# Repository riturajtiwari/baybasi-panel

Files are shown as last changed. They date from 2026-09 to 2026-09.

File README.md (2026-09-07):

# Baybasi pixel wall

Software and firmware for a WS2812B video wall. The wall is 64 pixels wide and
192 pixels high. Each wall has 48 panels of 16 x 16 pixels.

There are two identical displays. The two displays do not share a cable, a
ground or a clock. Each display is a complete and independent system.

The software runs today without hardware. A software DDP sink receives the
pixel data and shows the result in a browser. You can test the driver and the
upload utility before the boards arrive.

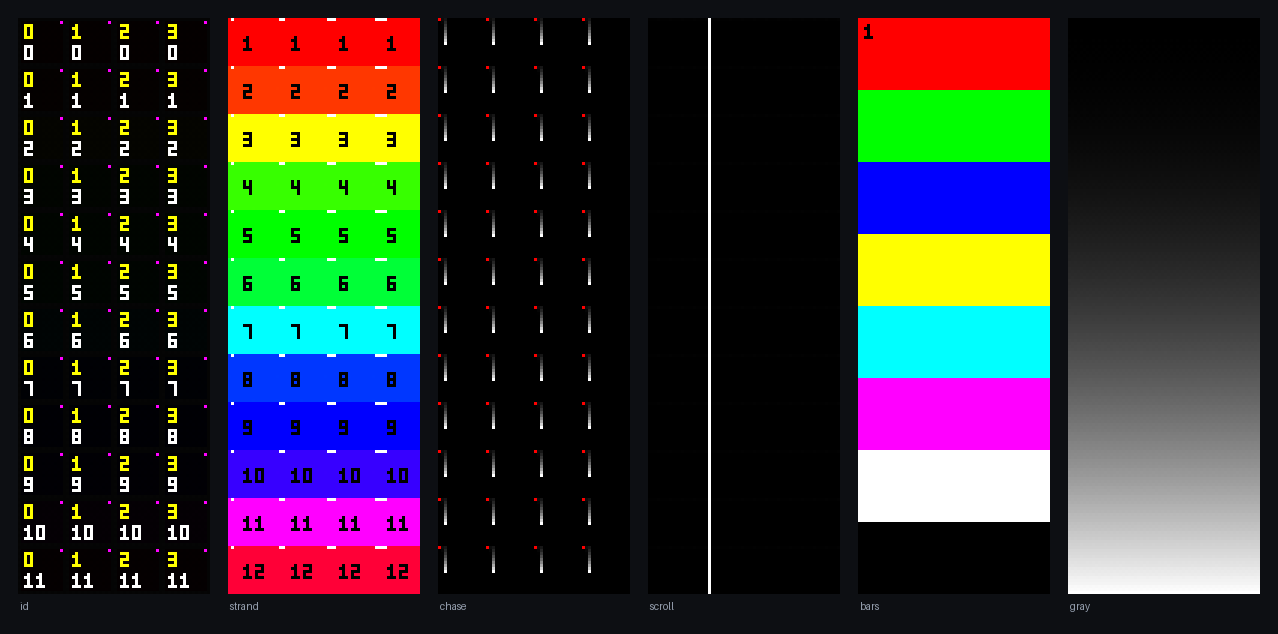
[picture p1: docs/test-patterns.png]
The test patterns


---

## 1. The system

Each display contains these parts:

| Part | Quantity |
|---|---|
| Raspberry Pi 3 or newer, Pi OS Lite, headless | 1 |
| 8-port unmanaged switch | 1 |
| Controller board, one for each panel column | 4 |
| 16 x 16 WS2812B panel | 48 |

Each controller board holds an ESP32-S3-DevKitC-1, a WIZnet W5500 Ethernet
module and two SN74AHCT245N level shifters. Each board has 12 data outputs.
Each output drives one panel. The panels are not in a daisy chain. Thus one
strand has 256 LEDs and one frame needs 7.98 ms.

The Raspberry Pi holds all the geometry. A controller knows only the quantity
of bytes that it owns. All four controllers use the same firmware.

---

## 2. The contents of this repository

| Directory | Contents |
|---|---|
| `sw/` | The driver, the upload utility and the software DDP sink. Python. |
| `fw/` | The controller firmware. C++, PlatformIO, arduino-esp32 3.x. |
| `hw/` | The board design, the fabrication files and the enclosure. KiCad. |
| `HANDOFF-software.md` | The specification. |

`sw/README.md` and `fw/README.md` give more data about each part.

---

## 3. Before you start

You must have these programs:

- Python 3.9 or newer
- `ffmpeg` and `ffprobe`, on the PATH
- PlatformIO, but only to build the firmware

Install the software:

```bash
cd sw && python3 -m venv .venv && .venv/bin/pip install -e .
```

Make sure that the configuration is correct:

```bash
.venv/bin/baybasi check
```

The command shows the geometry and the wire budget. The command shows
`no problems found` if the configuration is correct.

---

## 4. Procedure: test the software without hardware

Do this procedure before the boards arrive. The procedure finds mapping errors
on a screen. You do not have to look at 8 feet of LEDs.

1. Start the software DDP sink in the first terminal:

   ```bash
   cd sw && .venv/bin/baybasi sink
   ```

2. Open `http://localhost:8088` in a browser.

3. Send a test pattern from the second terminal:

   ```bash
   cd sw && .venv/bin/baybasi pattern id --target 127.0.0.1
   ```

4. Look at the browser. Each of the 48 panels shows its own column number in
   yellow and its own row number in white. If a number is in the wrong
   position, correct the `panels:` list in `sw/config/wall.yaml`.

5. Send the other patterns. Refer to section 7.

6. Stop the pattern. Then start the driver and the upload utility:

   ```bash
   cd sw && .venv/bin/baybasi driver --target 127.0.0.1
   ```

   ```bash
   cd sw && .venv/bin/baybasi web
   ```

7. Open `http://localhost:8080`. Add a media file. Set the fit policy. Look at
   the preview.

**Caution: Do not send two patterns at the same time.** Two senders on UDP port
4048 cause torn frames. The sink shows a warning if this condition occurs.

---

## 5. Procedure: install on the Raspberry Pi

Do this procedure on each of the two Raspberry Pi computers.

```bash
sudo IFACE=eth0 PI_IP=192.168.50.1 ./sw/deploy/install.sh
```

The script does these tasks:

1. Installs Python, `ffmpeg` and `chrony`.
2. Installs the software in `/opt/baybasi`.
3. Puts the media library in `/var/lib/baybasi`.
4. Sets the wired interface to `192.168.50.1/24`.
5. Sets `ipv4.never-default yes` on that interface.
6. Starts the driver and the upload utility as services.

**The LED network must not become the default route.** The LED network has no
connection to the internet. If the LED network becomes the default route, the
Raspberry Pi loses DNS and NTP. NTP keeps the two displays in step.

---

## 6. Procedure: flash and commission a board

**Warning: Flash each board on the bench. Do not flash a board that is in a
controller.** A devkit in a controller with USB power sends 5 V out through the
power terminal. The 5 V can energize the panel column.

**Note:** Many USB-A to USB-C cables supply power only. Such a cable makes the
devkit port look defective. If the devkit does not show on the USB bus, replace
the cable first.

1. Connect the devkit to the computer with a USB-C data cable.

2. Build and flash the firmware:

   ```bash
   cd fw && pio run -t upload
   ```

3. Flash all 10 devkits at the same session. Then install the devkits in the
   controllers.

4. Connect the controller to the switch. Apply power.

5. Find the board on the Raspberry Pi:

   ```bash
   baybasi discover
   ```

   The board shows its factory MAC address. The column is empty.

6. Give the board its column:

   ```bash
   baybasi assign aa:bb:cc:dd:ee:ff 2
   ```

   The board writes the column to NVS. Then the board restarts. The board keeps
   the column after an update.

7. Do steps 4 to 6 for each of the four boards.

After the first flash, use the network for all subsequent updates:

```bash
baybasi ota .pio/build/baybasi-ctrl/firmware.bin --pi-ip 192.168.50.1
```

If an update fails, remove the devkit from its sockets. Then install a
different devkit.

---

## 7. The test patterns

```bash
baybasi pattern <name> --target 127.0.0.1
```

| Name | Function | What you must see |
|---|---|---|
| `id` | Panel identification | Each panel shows its column and its row. |
| `strand` | Output identification | Each output has a different colour. |
| `chase` | LED chain | A comet moves smoothly along the chain. |
| `scroll` | Frame synchronization | A white column moves across the wall. The line does not break at the column seams. |
| `bars` | Colour order | The top band is red. |
| `gray` | Gamma and dither | A smooth ramp. There are no bands. |
| `solid` | Power supply | A flat colour. |

`scroll` is the most important pattern. Only `scroll` shows a synchronization
error between the four controllers.

**Caution: `solid` at full white causes the maximum current.** Do not use
`solid` at full white before the power injection is correct.

---

## 8. Configuration

`sw/config/wall.yaml` holds all the geometry. The file is data and not code.
You can correct an error in the wall with a text editor. You do not have to
change the Python code.

The file contains these items:

| Item | Function |
|---|---|
| `panel.chain` | The sequence of the 256 LEDs in one panel. |
| `controllers[].panels` | The wall row that each output drives. |
| `transform` | The rotation of one panel. Use this for a panel that is upside down. |
| `color_order` | The channel sequence on the network. |
| `render` | The frame rate, the gamma, the brightness and the epoch. |
| `network` | The addresses, the port and the packet size. |

Example: row 7 of column 2 shows the picture of row 8. To correct this error,
change two lines in the `panels:` list. Then restart the driver.

---

## 9. The status LED

The status LED is the only indication that you can see when the board is behind
a panel.

| Colour | Condition |
|---|---|
| Red | The board is in the start sequence. |
| Red, slow flash | There is no Ethernet link. |
| Amber | The link is up. There are no pixels for more than 500 ms. |
| Blue | The board receives data. The outputs are off. |
| Green, slow pulse | The board operates correctly. |
| Magenta | The frames are not complete. |
| White, pulse | An update is in progress. |
| White, fast flash | The operator sent a Find command. |
| Red, fast flash | There is a fault. Read the serial log. |

---

## 10. Keep the two displays in step

No messages go between the two displays. Each Raspberry Pi calculates the frame
number from the time of day:

```python
frame_index = int((time.time() - EPOCH) * FPS) % n_frames
```

Thus the two displays agree only if the two playlists are the same. The
playlist compiles to a frame timeline. The manifest digest is a hash of that
timeline.

Procedure:

1. Upload the same media to the first Raspberry Pi.
2. Upload the same media to the second Raspberry Pi.
3. Download the manifest from the second Raspberry Pi.
4. Use the **Compare** button on the first Raspberry Pi.

If the two digests agree, the two walls show the same content. If the two
digests do not agree, the utility gives the reason:

```
$ baybasi manifest --compare pi-b.json
DIFFERS:
  sunset.jpg: fit letterbox vs crop
  same media, different playlist order
```

The `EPOCH` value in `wall.yaml` must be the same on the two computers. The
`wall_digest` value must also be the same.

---

## 11. Troubleshooting

| Symptom | Cause | Correction |
|---|---|---|
| The sink shows torn frames and a high gap count. | Two senders transmit on port 4048. | Stop the other `baybasi pattern` or `baybasi driver`. |
| The wall shows noise at power-up. | The level shifters became active too soon. | Measure GPIO 8. GPIO 8 must stay high until the first complete frame. Check R15 to the 3V3E rail. |
| The wall keeps one picture after a fault. | The controller still receives packets. | Look at the driver log. A controller goes to black 500 ms after the last packet. |
| Red and green are not correct. | The Pi and the firmware both change the channel order. | Set `LED_ORDER_GRB` to 0 in `fw/src/config.h`. Refer to section 12. |
| The driver reports dropped frames. | The Raspberry Pi cannot do the work in time. | Read the stage times in `baybasi status`. The slowest stage is the cause. |
| The board does not show in `baybasi discover`. | There is no link, or the board has no address. | Look at the status LED. A red flash shows that there is no link. |
| The two walls do not agree. | The playlists are different. | Compare the manifests. Refer to section 10. |

---

## 12. Two decisions that the specification did not make

**The network carries RGB. The firmware changes the sequence to GRB.** The
WS2812B is a GRB device, but that is a property of the LED and not of the
network. The DDP data-type byte declares RGB. Thus a GRB payload would give
incorrect data to Wireshark and to other DDP tools.

One flag controls each side: `color_order` in `wall.yaml`, and `LED_ORDER_GRB`
in `fw/src/config.h`. Only one of the two must change the sequence. The `bars`
pattern shows which condition is true. The top band must be red.

**Each controller has its own DDP destination identifier, 10 to 13.** The four
boards are still different only by IP address. The identifier comes from the
column number. The firmware also accepts identifier 1 and identifier 255. The
byte counts do not change.

The identifier gives two advantages. One software sink on one computer can
replace four boards on four addresses. A packet that goes to the incorrect
board is rejected and not shown.

---

## 13. Tests

Python, 70 tests:

```bash
cd sw && .venv/bin/python -m pytest tests -q
```

Firmware logic, 20 tests. The tests run on the host computer:

```bash
cd fw && clang++ -std=c++17 -O1 -g -fsanitize=thread -I test/shim \
    -o /tmp/fwtest test/test_framebuf.cpp src/framebuf.cpp && /tmp/fwtest
```

---

## 14. The condition of this project

The software is complete and tested. A measured run gives 30.0 frames each
second with 0 torn frames and 0 protocol errors. The Raspberry Pi work is
3.0 ms of the 33.3 ms budget.

The firmware is complete but **no person has flashed the firmware to a board**.
The boards are in fabrication. Only the frame assembler is proven. The frame
assembler compiles on the host computer and passes the thread tests.

These items are not proven:

- The Ethernet start sequence
- The `/OE` sequence at power-up
- The update through the network
- The LED library with the 12 pins of the board

Do these three checks first at the bench:

1. The serial log shows the factory MAC address and a successful `ETH.begin`.
2. `baybasi discover` finds the board.
3. `baybasi pattern bars` lights the panels. The top band is red. There is no
   flash at power-up.

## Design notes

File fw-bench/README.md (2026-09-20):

# Bench panel test

Confirm WS2812B panels are alive before any of the real hardware exists. Runs on
a **classic ESP32 devkit** (ESP-WROOM-32, 30-pin, HW-394 or similar), not the
ESP32-S3 the controllers use.

Shares nothing with `../fw` except the serpentine mapping. Different chip,
different pins, no Ethernet. Do not carry pin numbers between them.

## What it does

Chains **4 panels on one wire** (1024 LEDs, one row of the wall) and cycles four
patterns forever. **It runs standalone.** Flash it, unplug the laptop, and it
keeps going: nothing waits on serial and nothing ever finishes.

| # | Pattern | Lit at once | Answers |
|---|---|---|---|
| 1 | **Panel walk**, one panel white | 256 | Is each panel alive, and in what order? |
| 2 | **Band**, a sliding hue-cycling band on every panel | 128 | All panels at once, and every colour channel |
| 3 | **Block**, a quarter panel marching the row in six colours | 64 | Every LED, every colour, at full brightness |
| 4 | **Trace**, one LED end to end | 1 | Exactly which LED does the chain stop at? |

**Nothing ever lights the whole row.** 1024 LEDs at white is ~61 A, which no
bench supply wants, least of all unattended. So the most any pattern lights is
one panel's worth. That is not only safer, it looks better: FastLED scales the
whole frame down to fit the current cap, so lighting less at a time means what
IS lit runs near full brightness.

**The onboard LED blinks at 1 Hz while the firmware is alive.** With no laptop
attached that is your only diagnostic, and it is worth more than it looks:
panels dark but LED blinking means power, data or panels, not a crashed board.

## The two numbers that change on a chain

| | One wire, 4 panels | Production, 12 outputs |
|---|---|---|
| LEDs per wire | 1024 | 256 |
| Frame time | ~31 ms, so ~32 fps | 8 ms, so 125 fps |
| Whole string white | **~61 A** | ~15 A per output |

This rig is a bench convenience. Those two numbers are the whole reason the real
controller gives every panel its own output.

## Powering it standalone

The dev kit needs its own 5 V once the laptop is gone. Two ways:

- **USB phone charger into the USB-C port.** Preferred. It isolates the ESP32
  from LED rail sag, so a heavy moment on the panels cannot brown out the board
  and reset it mid-test. Still tie ESP32 **GND** to panel **GND**.
- **VIN pin from the same 5 V that drives the panels.** One supply, and the
  common ground comes free, but a sagging rail takes the ESP32 down with it.

**Set `SUPPLY_MA` in `src/main.cpp` to what your bench supply can actually
deliver.** It defaults to 5000 mA. FastLED rescales brightness every frame to
stay inside it, so the column comes out dim. That is correct, not a fault.

**Inject 5 V at both ends of the chain.** Twelve panels fed from one end drop a
lot of voltage along the way, and the far panels go dim and orange. That is
voltage drop, not dead LEDs, and it is the most common false alarm on a chain
this long.

## NEVER power a panel from the dev kit

This destroyed a dev kit on 2026-09-13. Read both warnings before you wire anything.

The panel's lead carries three conductors: 5 V, DIN, GND. **Plug all three into the dev
kit and you have made the dev kit the panel's power supply.** Use two of them. Tape off
or pull the 5 V conductor.

256 WS2812B is 15.4 A at white. `SUPPLY_MA` defaults to 5000, so FastLED will happily
scale to a 5 A budget and ask the 5 V pin for it:

| Path | Realistic capability |
|---|---|
| Laptop USB 2.0 port | 500 mA |
| USB 3 port | 900 mA |
| Phone charger | 1.5 - 3 A |
| Dev kit 5 V trace and USB connector | ~1 - 2 A |
| What the firmware asks for at default | **5 A** |

Five to ten times what the path can carry. What burns is the USB connector, the board's
5 V trace or its series protection diode, and the AMS1117 on the same rail.

The production board does not make this mistake: J1-J12 are two-pin, DATA + GND, no
+5 V pin, with 330 ohm in series on every output. Wire the bench the same way.

If you genuinely must run a panel from USB, say so in the build flags. After the
ESP32's own ~50 mA a laptop port leaves about 400 mA, which is seven LEDs at white or
the whole panel at ~2.5 %:

```bash
PLATFORMIO_BUILD_FLAGS="-DPANELS=1 -DSUPPLY_MA=400" pio run -t upload
```

That is enough to prove a panel is alive and nothing more.

## NEVER drive data into an unpowered panel

The WS2812B's DIN pin has an ESD clamp diode to VDD. Drive DIN at 3.3 V while the
panel's 5 V rail is dead and that diode forward-biases, and **your GPIO becomes the
power supply for the whole panel**:

    GPIO 13 -> LED1 DIN -> ESD clamp diode -> the panel's entire 5 V net

An ESP32 pad is rated 40 mA absolute maximum. 256 WS2812B just sitting quiescent is
~256 mA, and at the ~2.6 V a clamp diode passes they are all in brownout, where the
draw is not 256 mA but whatever the half-biased silicon decides. LED 1's diode fails
short, GPIO 13 becomes a dead short to ground, and the AMS1117 on the dev kit
current-limits at about 1 A while dropping 1.7 V. That is the smoke.

**A switched-off supply does not save you. It is the reason it never stops.** An SMPS
with its switch off still has output capacitors and a bleeder resistor between +V and
-V, and -V is tied to your ESP32 ground. The panel's 5 V net therefore has a permanent
path to ground, so the GPIO never charges something up and stops. It sources current
until something fails.

Two rules, both cheap:

1. **One switch for everything.** Panel 5 V comes up before or with the ESP32, and goes
   down after it. Easiest is to power the ESP32 from the same 5 V that feeds the panels.
2. **330 ohm in series with DIN at the ESP32 end. Always, not just when debugging.**
   It caps a repeat of this at 3.3 V / 330 = 10 mA, which the pad shrugs off, and it
   does not measurably soften the edge over a short lead.

If it has already happened: the dev kit is scrap, do not try to rescue it. Test the
panel on a known-good board too — a damaged LED 1 blocks data to everything behind it.

## Wiring

- **330 ohm in series** between **GPIO 13** and **panel DIN**. See above. Not optional.
- **Panel GND** to an ESP32 **GND** pin. Not optional either, and the usual reason a
  column sits dark.
- **No wire, ever, between the dev kit's 5 V or VIN pin and the panel.** The panel's
  5 V comes from the bench supply and only from the bench supply:

      bench supply (ON) --5 V--+-- panel VDD
                               +-- panel GND --+-- ESP32 GND     <- mandatory
      USB -- ESP32 -- GPIO 13 --[330]----------+-- panel DIN
- **Panel 5 V and GND** to the bench supply, at both ends of the chain.
- ESP32 powered from a USB charger, or from VIN — see above.
- Keep the lead to the first panel under about 30 cm.

**Power the panel supply on first, and off last.** Every time.

A phone charger makes a fault worse than a laptop does: a laptop USB port will often
current-limit or shut down, a charger will happily deliver 2 A into a short.

**GPIO 12 is not used and must not be.** Held high at reset it sets the flash
voltage wrong and the board will not boot. On the header it sits between D14 and
D13, so count pins rather than trusting the gap.

### Do not use the blue level shifter

The 4-channel BSS138 board shifts through a MOSFET with 10 k pull-ups. The rising
edge takes hundreds of nanoseconds against a 400 ns data pulse, so it turns clean
data into garbage. It is the part the controller design rejected in favour of the
SN74AHCT245. Drive the first panel straight from the ESP32 at 3.3 V.

3.3 V into a 5 V-powered WS2812B is marginal on paper, since DIN wants
0.7 x VDD = 3.5 V, but it works over a short lead and is how these are normally
bench-tested. Only the first panel sees it; every LED reshapes the signal for the
next one, so a long chain is no harder than a short one. If the first panel
misbehaves:

1. Shorten the data lead.
2. Drop the panel supply to about 4.5 V, which pulls the threshold under 3.3 V.

(The 330 ohm series resistor is already mandatory — see the wiring section.)

## Bringing up the controller board on flying leads

The devkit in hand measures **2.5 mm wider** between its header rows than the
board's A1L/A1R sockets - 25.4 mm against 22.86 mm, which is exactly one 2.54 mm
pitch. It will not seat. **Do not press harder**: the sockets are factory-soldered
and splaying their contacts turns a good board into scrap.

You do not need it seated.

### First try: does the LEFT row alone go in?

At a 2.54 mm mismatch one row often seats while the other rides outboard. If the
left row (A1L) is down, **you need no jumpers at all** - everything the bring-up
firmware touches is on it:

| Devkit pad | GPIO | On this board |
|---|---|---|
| 4, 5, 6 | 4, 5, 6 | LED outputs D1, D2, D3 -> J1, J2, J3 |
| 7  | 7  | sync in |
| 8  | 15 | W5500 RST |
| 12 | 8  | /OE for both 245s |
| 16, 17, 18, 19 | 10, 11, 12, 13 | W5500 CS, MOSI, SCK, MISO |
| 20 | 14 | W5500 INT |
| 21, 22 | - | 5 V in, GND |

**The whole W5500 interface is on that row**, so Ethernet and the production
firmware in `../fw` can be brought up with the devkit half-seated. D4-D12 are all
on the right row and stay dark; they are nine more copies of the circuit D1-D3
already proves.

Three cautions while it sits at an angle:

- **Check the loose row touches nothing.** Those pins sit over U2's socket and
  the output resistors. Slide card or Kapton underneath.
- **Confirm seating in one second:** power from J13 with no USB. If the devkit
  comes up, pads 21 and 22 are making contact.
- **Expect noise on J4-J12.** Their 245 inputs float with the row unseated, so
  the buffers pass garbage to those terminals. Harmless if nothing is connected.

Do not leave a devkit levered like this permanently - the seated pins carry the
bending moment and A1L's contacts take it.

### If neither row seats: three jumpers

Female-to-male Dupont leads: the female end onto the devkit's header pin, the
male end (0.64 mm square) straight into the socket hole. Count holes on **A1L**,
the LEFT socket, from the **TOP** of the board - the J1-J6 terminal-block end,
with the devkit's USB ports toward the bottom edge.

| Devkit pin | A1L hole | Carries |
|---|---|---|
| `GND` (below `5Vin`) | **22**, the last one | the only logic reference. Not optional |
| `8`  | **12** | /OE. LOW or nothing leaves the board |
| `4`  | **4**  | output D1 -> R1 330R -> J1 |

**Check the count before you trust it.** A1L hole 22 is a dead short to the J13
GND terminal, and hole 21 shows a diode drop to J13 `+` through Q1. If those two
do not read that way you are counting from the wrong end, and hole 4 is really
hole 19 (GPIO13) - which will look exactly like a dead board.

Power:

- **Board** from J13, off the bench supply.
- **Devkit** from USB only. Do NOT also jumper 5 V: its 5 V pin back-feeds this
  board through Q1's channel. See FABRICATION.md.
- **Panel 5 V and GND from the bench supply**, never from this board. J1-J12
  carry DATA + GND only, which is exactly why this board cannot repeat the
  dev-kit failure above.
- Panel DIN to J1's **square** pad (`J1-J12: SQ PAD = DATA` on the silkscreen).

```bash
pio run -e ctrl-board -t upload
```

Flash over the **COM** port (the UART bridge). The monitor is on the **USB**
port, because the env sets `ARDUINO_USB_CDC_ON_BOOT=1`.

What lights proves: J13, Q1, the 5 V rail, U3 and the 3V3E rail, R15, U1, R1,
J1 and the full signal chain. What it does not touch: U2 and outputs 7-12, and
the W5500. Add `-DLED_PIN=5` and move the jumper to A1L hole 5 to walk along
D2, D3, and so on.

## Flashing the S3 devkits: expect the BOOT dance

Confirmed on hardware 2026-09-19. These boards have two USB-C ports. The one that
enumerates on macOS as **`/dev/cu.usbmodem*`** is the **native USB-Serial/JTAG**
port, not a UART bridge (a bridge would appear as `cu.wchusbserial*` or
`cu.usbserial-*`). esptool cannot reset a native-USB port into download mode while
application firmware owns it, so a plain upload fails with:

    A fatal error occurred: Failed to connect to ESP32-S3: No serial data received.

Force download mode by hand, every upload:

1. Hold **BOOT**.
2. Tap **RST**.
3. Wait a beat, release **BOOT**.
4. The RGB LED goes dark - that is your confirmation. Wait ~2 s to enumerate.

**Then do NOT pass `--upload-port`.** The device renames itself between application
mode and ROM download mode (seen: `usbmodem1234561` -> `usbmodem101`), so a pinned
port fails with "No such file or directory". Let auto-detect find it:

```bash
ls /dev/cu.* && pio run -e ctrl-all12 -t upload
```

A good upload reports `USB mode: USB-Serial/JTAG` and `Hash of data verified` on
every block. It also prints the **MAC address** - record it, the driver assigns
columns by MAC.

## Build and flash

PlatformIO is not installed by default on this machine:

```bash
uv tool install platformio
```

Plug the devkit in with a **data** USB-C cable first. A charge-only cable is
indistinguishable from a dead board. Check it appeared with `ls /dev/cu.*`,
looking for `/dev/cu.wchusbserial*`. The HW-394 uses a CH340C, which macOS
Sequoia drives natively.

```bash
pio run -t upload && pio device monitor
```

If upload times out, hold **BOOT**, tap **EN**, release **BOOT**, retry.

### If nothing lights at all

Check the chipset before suspecting hardware. These panels are older than the
WS2812B the wall is specified around, and the wrong chipset looks identical to a
dead column. Uncomment one line in `platformio.ini` and reflash:

```
; -DLED_CHIPSET=WS2811
; -DLED_CHIPSET=WS2812
; -DLED_CHIPSET=SK6812
```

### Testing a different number of panels

`PANELS` is a build flag, so no source edit is needed:

```bash
pio run -t upload                                   # 4 panels, one row
PLATFORMIO_BUILD_FLAGS="-DPANELS=1"  pio run -t upload   # a single panel
PLATFORMIO_BUILD_FLAGS="-DPANELS=12" pio run -t upload   # a whole column
```

Every pattern scales itself, and the lit-LED count stays bounded at one panel's
worth regardless, so a column is no harder on the supply than a row.

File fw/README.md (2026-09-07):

# Baybasi controller firmware

One image for all four boards. ESP32-S3-DevKitC-1, W5500 on SPI, twelve
parallel WS2812B outputs through two SN74AHCT245N level shifters.

```bash
pio run                      # build
pio run -t upload            # first flash, over the devkit's USB-C, on the bench
pio device monitor
```

Then everything after the first flash goes over Ethernet, from the Pi:

```bash
baybasi ota .pio/build/baybasi-ctrl/firmware.bin --pi-ip 192.168.50.1
```

## Flash all ten before any of them goes into a board

Two traps, both of which cost a day if you meet them mid-assembly:

- **Many USB-A to USB-C cables are charge-only** and make the devkit's port look
  dead. If nothing enumerates, change the cable before you change anything else.
- **A devkit seated in a board with USB live back-feeds 5 V** out through the
  power terminal and tries to power the panel column. Flash on the bench, before
  the devkits are seated. If you must flash a seated devkit, do it with the LED
  PSU on, or with the panel supply disconnected.

Recovery from a bricked OTA is to pull the devkit out of its sockets and put
another one in. That is what the sockets are for.

## Pin map

Final, from the board's pad coordinates. `src/config.h`.

| Function | GPIO |
|---|---|
| W5500 CS / MOSI / SCK / MISO | 10 / 11 / 12 / 13 |
| W5500 INT | 14 |
| W5500 RST | 15, active low |
| LED outputs D1, D2, D3 | 4, 5, 6 |
| LED outputs D4 … D12 | 1, 2, 21, 38, 39, 40, 41, 42, 47 |
| Level-shifter /OE, both chips | 8 |
| Sync input, optional, unpopulated | 7 |
| Status RGB LED | 48 |

## The three things that will otherwise cost you a day

**Twelve outputs cannot use RMT.** The ESP32-S3 has four RMT transmit channels.
Twelve parallel outputs go through the LCD_CAM peripheral in parallel mode,
which is what `I2SClocklessLedDriver` does. Any GPIO works, because it routes
through the GPIO matrix.

**GPIO 8 is /OE and is pulled up to 3V3E on the board.** HIGH means the shifters
are high-impedance and every panel sees a defined low through R16-R27. The
firmware holds it high through boot and drives it low only once the first
*complete* frame has been buffered and clocked out. Skip that and the wall
shows noise at power-up.

**The W5500 needs 50 ms after RST is released before SPI.** `net.cpp` does the
reset itself and waits, then passes `rst = -1` to `ETH.begin` so the driver does
not pulse it again and skip the wait.

## Order of events at power-up

1. `/OE` stays HIGH. Nothing on the wall lights up.
2. Ethernet comes up. Static address from NVS if this board has a column; DHCP
   (in practice link-local) if it does not, which is enough to be seen and
   commissioned and not enough to be mistaken for a working column.
3. The first complete DDP frame is buffered and clocked out.
4. `/OE` goes LOW and the wall becomes visible.

## Board identity

All four boards run the same binary, so something has to say which column a
board owns. That something is NVS, not the image — building four images turns
every OTA into an opportunity to put column 3's code on column 1.

An unassigned board broadcasts an announcement every two seconds on UDP 4049
carrying its factory MAC, which is unique per chip. The W5500's MAC is that same
factory MAC, so the identity on the wire and the identity in the announcement
cannot drift apart. The Pi holds the MAC-to-column table, consistent with the Pi
holding all the other geometry.

Commissioning a replacement board:

```bash
baybasi discover                   # watch the new MAC appear
baybasi assign aa:bb:cc:dd:ee:ff 2 # it reboots onto 192.168.50.13 and stays there
```

Or the same two steps in the upload utility's **Controllers** panel, which also
has a **Find** button that flashes the board's status LED — useful when the
board is behind a panel, mid-column, and you need to know which one it is.

## Frame handling

The board owns 9216 bytes and knows nothing else about the wall. Seven data
packets arrive per frame; one zero-length broadcast PUSH latches all four
controllers together.

Completeness is tracked as a set of byte intervals, not a byte count — a
duplicated packet must not be mistaken for a complete frame. An incomplete
frame at PUSH is counted and **dropped**, never shown.

Three buffers, not two. A frame takes 7.98 ms to clock out and the LED
peripheral reads its buffer by DMA the whole time; with two buffers a latch
arriving mid-transmission hands the network thread the buffer still being
clocked out. The writer, the frame waiting, and the frame being shown are always
distinct, with no lock on the receive path.

After 500 ms with no packets the board fades to black over 600 ms. A frozen wall
looks like working content and hides the fault.

## Status LED

The only thing you can see once the board is in an enclosure behind a panel.

| | |
|---|---|
| red | booting |
| red, blinking | no Ethernet link |
| amber | link up, no pixels for over 500 ms |
| blue | receiving, outputs still disabled |
| green, breathing | running |
| magenta | frames are arriving incomplete |
| white, pulsing | OTA in progress |
| white, flashing | "Find" from the Pi |
| red, fast | fault — read the serial log |

## Colour order

The Pi sends RGB; this firmware reorders to GRB on the way into the strand
buffer (`LED_ORDER_GRB` in `config.h`). If your build of the LED library *also*
reorders, the two swaps cancel and red and green come out exchanged. Set
`LED_ORDER_GRB` to 0 and rebuild.

`baybasi pattern bars` on the Pi settles it in one look: the top band is red.

## Tests

The frame assembler is the part most likely to be subtly wrong, and it is pure
logic, so it compiles and runs on a host:

```bash
clang++ -std=c++17 -O1 -g -fsanitize=thread -I test/shim \
    -o /tmp/fwtest test/test_framebuf.cpp src/framebuf.cpp && /tmp/fwtest
```

That covers out-of-order and duplicated packets, a lost packet leaving the frame
incomplete, the RGB-to-GRB reorder across packet boundaries, and a two-thread
stress test of the triple buffer under ThreadSanitizer.

## Not yet run on hardware

The boards are in fabrication. Everything above is written against the
datasheets, `hw/FABRICATION.md` and the arduino-esp32 3.x API; the frame logic
is tested on a host, but nothing here has been flashed. The first three things
to check on the bench, in order:

1. Serial output shows the factory MAC and `ETH.begin` succeeding.
2. `baybasi discover` on the Pi sees the announcement.
3. `baybasi pattern bars` — panels light, red at the top, no flicker at
   power-up.

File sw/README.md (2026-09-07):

# Baybasi wall software

Driver, upload utility and software DDP sink for a 64 x 192 WS2812B wall, per
`../HANDOFF-software.md`. The controller firmware is in `../fw`.

Everything here runs today, against the software sink, with no hardware.

```bash
python3 -m venv .venv && .venv/bin/pip install -e .   # needs ffmpeg on PATH
.venv/bin/baybasi check                               # validate the wall config

# terminal 1 - pretend to be all four controllers
.venv/bin/baybasi sink --bind 127.0.0.1
#   -> http://localhost:8088

# terminal 2 - drive them
.venv/bin/baybasi pattern scroll --target 127.0.0.1
```

`scroll` is the pattern you will use more than any other: a single white column
sweeping across the wall. If the four controllers ever latch at different
times, the line breaks at the column seams and nothing else shows that.

## What is here

| | |
|---|---|
| `baybasi/ddp.py` | the wire format, and the rules that go with it |
| `baybasi/geometry.py` | `wall.yaml` -> per-controller index arrays |
| `baybasi/pixels.py` | gamma, brightness, dither, pack/unpack |
| `baybasi/media.py` | ffmpeg decode and the frame cache |
| `baybasi/library.py` | playlist, timeline, manifest |
| `baybasi/driver.py` | the 30 fps loop |
| `baybasi/sender.py` | packetise, send, broadcast PUSH, wall-clock pacing |
| `baybasi/sink.py`, `sinkweb.py` | the software controller and its viewer |
| `baybasi/patterns.py` | test patterns |
| `baybasi/webapp.py`, `web/` | the upload utility |
| `baybasi/control.py` | discovery, commissioning, OTA |
| `config/wall.yaml` | **all** the geometry |
| `deploy/` | systemd units and a Pi installer |

## Commands

```
baybasi check                          validate the config, print the wire budget
baybasi sink [--out web|ansi|png]      software DDP controller + viewer
baybasi pattern <name> [--target IP]   send a test pattern
baybasi driver [--pattern <name>]      run the wall
baybasi web                            the upload utility
baybasi add FILE...                    add media from the command line
baybasi playlist                       show the compiled timeline
baybasi manifest [--compare other.json]  print or diff the manifest
baybasi discover                       watch for controllers announcing themselves
baybasi assign MAC COLUMN              commission a board
baybasi ota IMAGE [--mac ...]          push firmware over Ethernet
baybasi status                         what the running driver reports
baybasi render --pattern id            render frames to PNG, no network at all
```

Patterns: `id` `strand` `scroll` `chase` `bars` `gray` `solid`.

## The wall config

`config/wall.yaml` holds the whole geometry: panel chain, row-to-output map,
per-panel rotation, addresses, gamma, brightness, epoch. It is data because it
*will* be wrong somewhere on the first build, and you will want to fix it by
editing a file at 2 a.m. rather than editing Python.

The chain is expressed as `axis`/`start`/`serpentine` rather than a hard-coded
formula. The defaults reproduce the team's verified mapping exactly, and a test
asserts that against `local = x * 16 + (y if x % 2 == 0 else 15 - y)`.

Row 7 of column 2 showing row 8's picture is a two-line edit in `panels:`.
A panel mounted upside down is `transform: rot180` on that row.

## Bring-up order

1. `baybasi check` - config valid, every pixel driven exactly once, 8.92 Mbps.
2. `baybasi sink` in one terminal, `baybasi pattern id --target 127.0.0.1` in
   another. Every panel should be captioned with its own column and row.
3. `baybasi pattern chase` - the comet must walk the serpentine smoothly. A
   zig-zagging comet means the chain spec is wrong.
4. With boards: `baybasi discover`, then `baybasi assign <mac> <column>` for
   each. They keep the assignment across OTA.
5. `baybasi pattern bars` - **check red is at the top.** This is the one thing
   the software cannot check for you; see "Colour order" below.
6. `baybasi pattern scroll` - look along the column seams for a broken line.
7. `baybasi web`, upload something, and look at the preview before it is eight
   feet tall.

## Two walls, one media set

The displays share no cable and no clock. Both Pis compute

```python
frame_index = int((time.time() - EPOCH) * FPS) % n_frames
```

so they stay together only if they are playing the *same timeline*. The
playlist therefore compiles to a deterministic frame timeline - an ordered list
of (media, fit, frame count) - and the manifest digest over that timeline is
what you compare between the two Pis.

Upload to each Pi in turn, then on either one open the utility and use
**Compare** with the other's `manifest.json`. Matching digests mean matching
walls. A mismatch is reported in operator terms, not as a hash:

```
$ baybasi manifest --compare /media/usb/pi-b-manifest.json
DIFFERS:
  sunset.jpg: fit letterbox vs crop
  same media, different playlist order
```

`EPOCH` is in `wall.yaml` and must be identical on both Pis. So must the clock:
both run NTP, and `chronyc tracking` is worth a look before you trust the sync.

## Decisions this made that the handoff left open

**Colour order on the wire is RGB, and the firmware reorders to GRB.** The
WS2812B is a GRB part, but that is a property of the LED, not of the link. DDP's
data-type byte declares RGB, so sending GRB while declaring RGB would mislead
Wireshark and any third-party DDP tool. One flag on each side controls it
(`color_order` here, `LED_ORDER_GRB` in the firmware) and *exactly one* of them
must swap. `baybasi pattern bars` tells you which way round you are in one look:
the top band is red.

**Each controller has its own DDP destination id (10-13).** The handoff says the
four boards differ only by IP address, which is still true - the id is derived
from the column, the firmware also accepts the standard id 1 and the broadcast
255, and no byte counts change. It buys two things: one software sink on one
host can stand in for four boards on four addresses, and a packet that arrives
at the wrong board is rejected instead of drawn.

**Media is pre-decoded to raw frames at wall resolution.** A frame is 36 864
bytes; a 30-second clip is 33 MB. The driver then memory-maps and slices instead
of decoding, which is what lets a Pi 3 hold 30 fps with room to spare, and it
makes the two Pis produce byte-identical pixels from byte-identical files.

**Rendering in the sink runs on its own thread.** The first version encoded PNGs
on the receive thread, overflowed the socket buffer, and reported its own
slowness as torn frames from the driver. A debugging tool that lies about the
thing it is debugging is worse than none.

## Performance

Measured on this development machine, per frame, against a 33.33 ms budget:

```
decode 0.08 ms   gamma/dither 0.30 ms   pack 0.88 ms   send 0.33 ms
```

The driver reports these continuously and, when it cannot keep up, names the
slowest stage - because "dropped frames" on its own tells you nothing you can
act on.

## Tests

```bash
.venv/bin/python -m pytest tests -q      # 68 tests, ~12 s
```

They cover the wire rules (payload ceiling, no PUSH on data packets, exactly
seven packets plus one broadcast PUSH per frame), the panel chain against the
team's verified formula, pack/unpack round-tripping, the gamma/dither pipeline,
the playlist timeline and manifest diffing, the upload flows, and a real
driver-to-sink loop over a socket including a deliberately torn frame.

## Installing on a Pi

```bash
sudo IFACE=eth0 PI_IP=192.168.50.1 ./deploy/install.sh
```

That installs to `/opt/baybasi`, puts the library in `/var/lib/baybasi`, sets
the wired interface static with `ipv4.never-default yes` so the LED network
cannot become the default route, enables NTP, and starts both services.

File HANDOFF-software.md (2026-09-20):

# Baybasi pixel wall — software handoff

Build the software for a WS2812B video wall whose hardware is already designed,
ordered and specified. Nothing in this document is open for redesign; the
electrical and topology decisions are settled and the boards are in fabrication.
What does not exist yet is any software at all.

## What to build

1. **The driver.** Runs on a Raspberry Pi. Decodes media, maps it onto the wall,
   and streams pixels to four controller boards over Ethernet at 30 fps.
2. **The upload utility.** Lets a non-technical person put media on the Pi from a
   laptop or phone, order it into a playlist, and see what the wall will show.
3. **The controller firmware.** Runs on each ESP32-S3. Receives pixel data and
   drives twelve WS2812B panels in parallel. Treat this as in scope: nothing
   works without it, and the pin map below is final.

## The system this plugs into

There are **two physically separate displays**. They share no cable, no ground
and no clock. Each is a complete independent system:

| Per display | Count |
|---|---|
| Raspberry Pi 3 or newer, Pi OS Lite, headless | 1 |
| 8-port unmanaged switch | 1 |
| Controller board, one per panel column | 4 |
| 16×16 WS2812B panel | 48 |

Each controller board is an ESP32-S3-DevKitC-1 with a WIZnet W5500 Ethernet
module on SPI and two SN74AHCT245N level shifters. It has **twelve parallel data
outputs, one per panel**. Panels are never daisy-chained. That is what holds a
strand to 256 LEDs and the frame time to 8 ms.

## Geometry

A display is **64 pixels wide by 192 tall, portrait**. Four columns of panels
across, twelve rows down.

- Column `c` in 0..3 covers `x = c*16 .. c*16+15`. Controller `c` drives it.
- Row `r` in 0..11 covers `y = r*16 .. r*16+15`. Output `D(r+1)` drives it.
- Within a panel, the chain is **column-serpentine**, verified against the
  team's earlier code:

```python
# x, y are 0..15 within the panel
local = x * 16 + (y if x % 2 == 0 else 15 - y)
```

Put the row-to-output assignment and the panel chain order in **YAML, not code**.
It will be wrong somewhere on the first build and you will want to fix it by
editing data at 2 a.m., not by editing Python.

## Pixel format

WS2812B is 24-bit **GRB**, most significant bit first. There is no intensity or
global brightness byte; that is APA102 and this is not that. Brightness is
arithmetic you do before transmission.

Timing, which sets the ceiling and is not negotiable:

| | |
|---|---|
| Bit period | 1.25 µs |
| Per LED | 30 µs |
| 256-LED strand | 7.68 ms |
| Latch | 300 µs budget, covers both the 50 µs and 280 µs part variants |
| **Frame floor, one strand** | **7.98 ms, so 125 fps** |
| **Target** | **30 fps** |

All twelve outputs run simultaneously, so a board's frame time is one strand's,
not twelve.

## Wire protocol

**DDP over UDP, port 4048.** Not Art-Net, not E1.31. Chosen and settled.

- The Pi holds all geometry. A controller knows only how many bytes it owns and
  where they go on its twelve outputs. All four controllers run identical
  firmware and differ only by IP address.
- Each controller owns 3072 pixels, which is 9216 bytes.
- **Payload must not exceed 1472 bytes.** The W5500 does not fragment IP. Use
  480 pixels per packet: 1440 bytes of data plus a 10-byte DDP header is 1450.
- Send a **broadcast PUSH** to latch all four controllers on the same frame.
  Latching per-controller tears visibly at the column seams.
- The controller **double-buffers and latches only complete frames.** A torn
  frame must be dropped, not shown.
- After **500 ms with no packets**, the controller fades to black. A frozen wall
  looks like working content and hides the fault.

Aggregate bandwidth per display is about 8.8 Mbps, so 100 Mbit is ample.

## Network

- Both displays use the **identical subnet, 192.168.50.0/24**. They never see
  each other, so there is no conflict.
- Pi is `.1`. Controllers are `.11` through `.14`, static, held in NVS and set
  at commissioning rather than compiled in. See **Board identity** below.
- Set `ipv4.never-default yes` on the Pi's wired interface. The LED network must
  not become the default route.
- Wired only. No WiFi anywhere in the pixel path.

## Keeping the two displays in step

**No messages pass between the displays.** Both Pis run NTP and derive the same
frame from wall-clock time:

```python
frame_index = int((time.time() - EPOCH) * FPS) % n_frames
```

`EPOCH` is a fixed constant compiled into both. This means **the media set on
both Pis must be byte-identical**, including playlist order. The upload utility
has to make that easy and has to make divergence visible.

## Deliverable 1: the driver

Runs on the Pi. Python is fine; NumPy for the pixel pipeline.

- Decode JPG, PNG, GIF and video. GIF and video both become frame sequences.
- Scale to 64×192. The wall is tall and narrow and most source media is not, so
  make the fit policy configurable per item: letterbox, crop, or stretch.
- Apply gamma then brightness in 16-bit, then dither down to 8-bit. Banding on a
  large dim wall is the most common way this looks cheap.
- Slice into four column spans, pack each into DDP packets, send, broadcast PUSH.
- Pace to 30 fps against a monotonic clock, not `sleep(1/30)`.
- Report achieved fps and dropped frames. Log when the pipeline cannot keep up
  and say which stage was slow.
- **Ship a test-pattern generator.** Panel ID overlay, per-strand colour
  identification, and a vertical white line scrolling horizontally. That last
  one is the pattern that reveals tearing between columns, and you will use it
  more than anything else.

## Deliverable 2: the upload utility

Runs on the Pi. The Pi is headless, so this is a small web app reachable from a
laptop or phone on the same network.

- Accept JPG, PNG, GIF and video. Validate on upload, do not fail at playback.
- List, delete, reorder into a playlist. Set the per-item fit policy and duration.
- **Preview what the wall will actually show**, rendered at 64×192 through the
  same scaling and gamma path as the driver. Someone will upload a landscape
  photo and needs to see the crop before it is eight feet tall.
- Tell the driver to reload without a restart.
- Because the two displays are network-isolated from each other, the same media
  must be uploaded to each Pi in turn. Make that a first-class flow and show a
  checksum or manifest so a mismatch between the two walls is obvious.

### Commissioning, which also lives in the utility

The MAC-to-column table has to be editable by a person, and this is where that
happens. Without it the boards are provisioned by editing a file over SSH, which
is exactly the job that gets done wrong on a ladder at 11 p.m.

- **Discover unprovisioned boards.** There is no DHCP on the pixel segment, so
  discovery cannot lean on it. Have an unassigned board announce itself with a
  UDP beacon carrying its factory MAC and firmware version, and have the utility
  listen. Show MAC, firmware, assigned column, last seen, and whether it is
  currently receiving frames.
- **Assign, reassign and clear** a column for a MAC. Four columns, four boards.
- **Refuse duplicate assignments.** Two boards claiming the same column is the
  failure that silently duplicates a quarter of the image, and it looks like a
  content bug rather than a wiring one. Block it, do not warn about it.
- **Identify a board physically.** A button that makes the selected board flood
  its whole column white, or blink its status LED. Behind the wall there are four
  identical boxes and a MAC tells you nothing about which is which. This one
  control is the difference between ten minutes of commissioning and an hour.
- **Survive a swap.** Replace a board, its new MAC appears unassigned, assign it
  the same column, done. No reflash, no rebuild.

**The MAC table is the one thing that must NOT be copied between the two Pis.**
Media and playlist have to be byte-identical across both displays; the board
assignments are per-display, because they name different physical hardware.
Whatever you build for pushing content to both walls must exclude this table,
and it is worth a test that proves it does.

## Deliverable 3: the controller firmware

Arduino framework or ESP-IDF, your call.

**Final pin map.** These came from the board's pad coordinates and are not
suggestions:

| Function | GPIO |
|---|---|
| W5500 CS / MOSI / SCK / MISO | 10 / 11 / 12 / 13 |
| W5500 INT | 14 |
| W5500 RST | 15, active low |
| LED outputs D1, D2, D3 | 4, 5, 6 |
| LED outputs D4 … D12 | 1, 2, 21, 38, 39, 40, 41, 42, 47 |
| Level-shifter /OE, both chips | 8 |
| Sync input, optional, unpopulated | 7 |
| Status RGB LED | 48 |

Two things that will otherwise cost you a day:

- **The ESP32-S3 has only four RMT transmit channels.** Twelve parallel outputs
  must use the LCD_CAM peripheral in parallel mode, which is what FastLED's
  ESP32-S3 I2S driver and I2SClocklessLedDriver use. Any GPIO works because it
  routes through the GPIO matrix.
- **GPIO 8 drives /OE and is pulled up to 3.3 V on the board.** High means the
  shifters are high-impedance and the panels see a defined low through the
  output pull-downs. Hold it high through boot and drive it low only once the
  first complete frame is buffered. Otherwise the wall shows noise at power-up.

Ethernet brings up with `ETH.begin(ETH_PHY_W5500, ...)` on arduino-esp32 core
3.x. Wait 50 ms after releasing RST before touching SPI.

## Getting firmware onto the boards

**First flash is over USB, on the bench, before the devkits are seated.** Each
ESP32-S3-DevKitC-1 has a USB-C port with a USB-to-UART bridge; esptool,
PlatformIO or the Arduino IDE all work. Flash all ten in one sitting before any
of them goes into a controller. Two traps: many USB-A to USB-C cables are
charge-only and make the port look dead, and a devkit seated in a board with USB
live will back-feed 5 V out through the power terminal and try to power the
panel column. Bench flashing avoids both.

**Everything after that is over Ethernet, pushed from the Pi.** The boards end
up mid-column, inside enclosures, behind panels, and the enclosure has no USB
opening. Build OTA in from the start, serve the image from the Pi, and make the
driver able to report each controller's running firmware version.

**Recovery is to pull the devkit.** It sits in sockets precisely so a bricked
OTA or a dead chip is a swap rather than a rework.

### Board identity

All four controllers run the same image, so something has to tell a board which
column it owns. Do not solve this by building four firmware images; that turns
every OTA into an opportunity to put column 3's code on column 1.

Recommended: identity lives in NVS, not in the image. A board with no assignment
comes up, takes a link-local or DHCP address, and announces itself with its
factory MAC, which is unique per chip. You assign it a column once, it persists,
and OTA never touches it. Set the W5500's MAC from the same factory MAC so the
two identities cannot drift apart.

The Pi keeps the MAC-to-column table, which is consistent with the Pi holding
all the other geometry. Commissioning a replacement board is then: plug it in,
see the unassigned MAC appear, tell it which column it is.

## Decided already — do not reopen

One panel per output. Pi holds geometry, controllers hold byte counts. DDP over
UDP. Wired Ethernet only. Gamma and brightness on the Pi. Two fully independent
systems synchronised by wall clock. Panel power is injected separately and never
routes through a controller board.

## Where to start

- Prior art from the team, and the source of the panel mapping:
  https://github.com/chanchal1987/baybasi_panel_2025
- Board design, pin map and fabrication notes: `hw/` in this repo, especially
  `hw/FABRICATION.md`.
- **Build a software DDP sink first.** A script that listens on 4048 and renders
  received frames to a window or a PNG. It lets the driver and the utility be
  finished and demoed before a single board arrives, and it is the only way to
  debug mapping bugs without staring at eight feet of LEDs.

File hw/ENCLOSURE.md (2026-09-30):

# Per-column unit enclosure, rev B

One printed box per column holds the 12-way fused block and the column
controller, block above board, on the inside of a hinged door. Four make a
display, two to a 16 in door. Source: [enclosure.scad](enclosure.scad).
Outputs: [enclosure/](enclosure/), regenerated by
[export_enclosure.sh](export_enclosure.sh), which also runs
[annotate_enclosure.py](annotate_enclosure.py) to label the illustrations.

**Box: 144 wide x 328 tall x 65 deep (mm).** Two fit a 406 mm door with
118 mm to spare. Allow about 430 mm of door height, which covers the box plus
the feed bends above and below it.

## Illustrations

The unit as you'll meet it, standing on its door, with the lid and cover on and
off. The coloured parts inside and the cables are stand-ins; the lid and cover
are tinted only so you can tell them apart. In OpenSCAD, pick `illus_closed`,
`illus_open`, `illus_lead` or `illus_mount` from the `part` dropdown to turn
any of these round yourself.

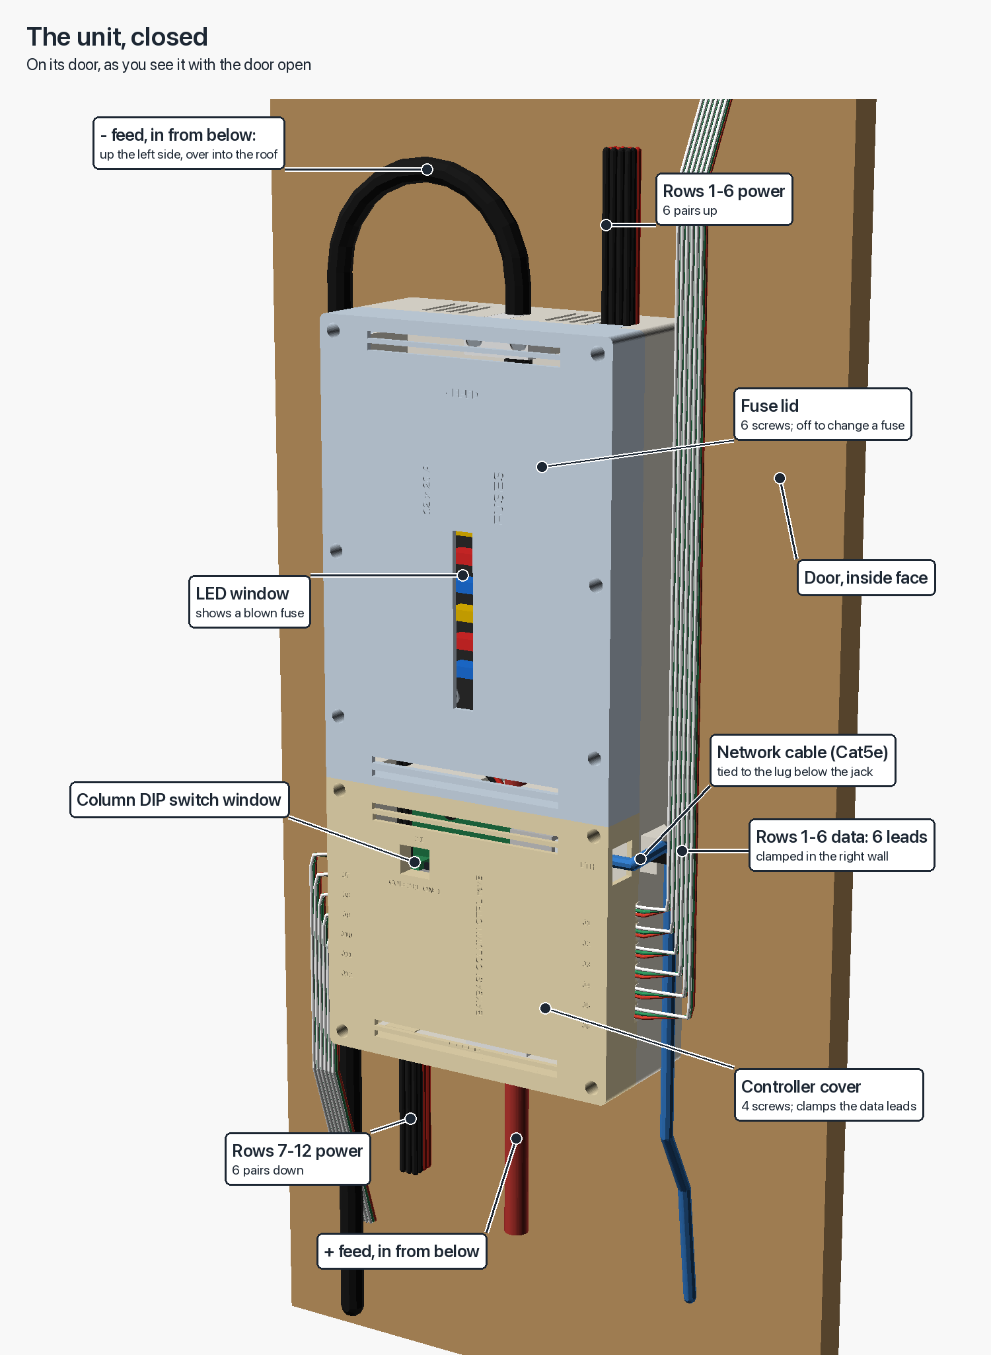
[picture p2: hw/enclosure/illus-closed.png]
The unit, closed, on its door


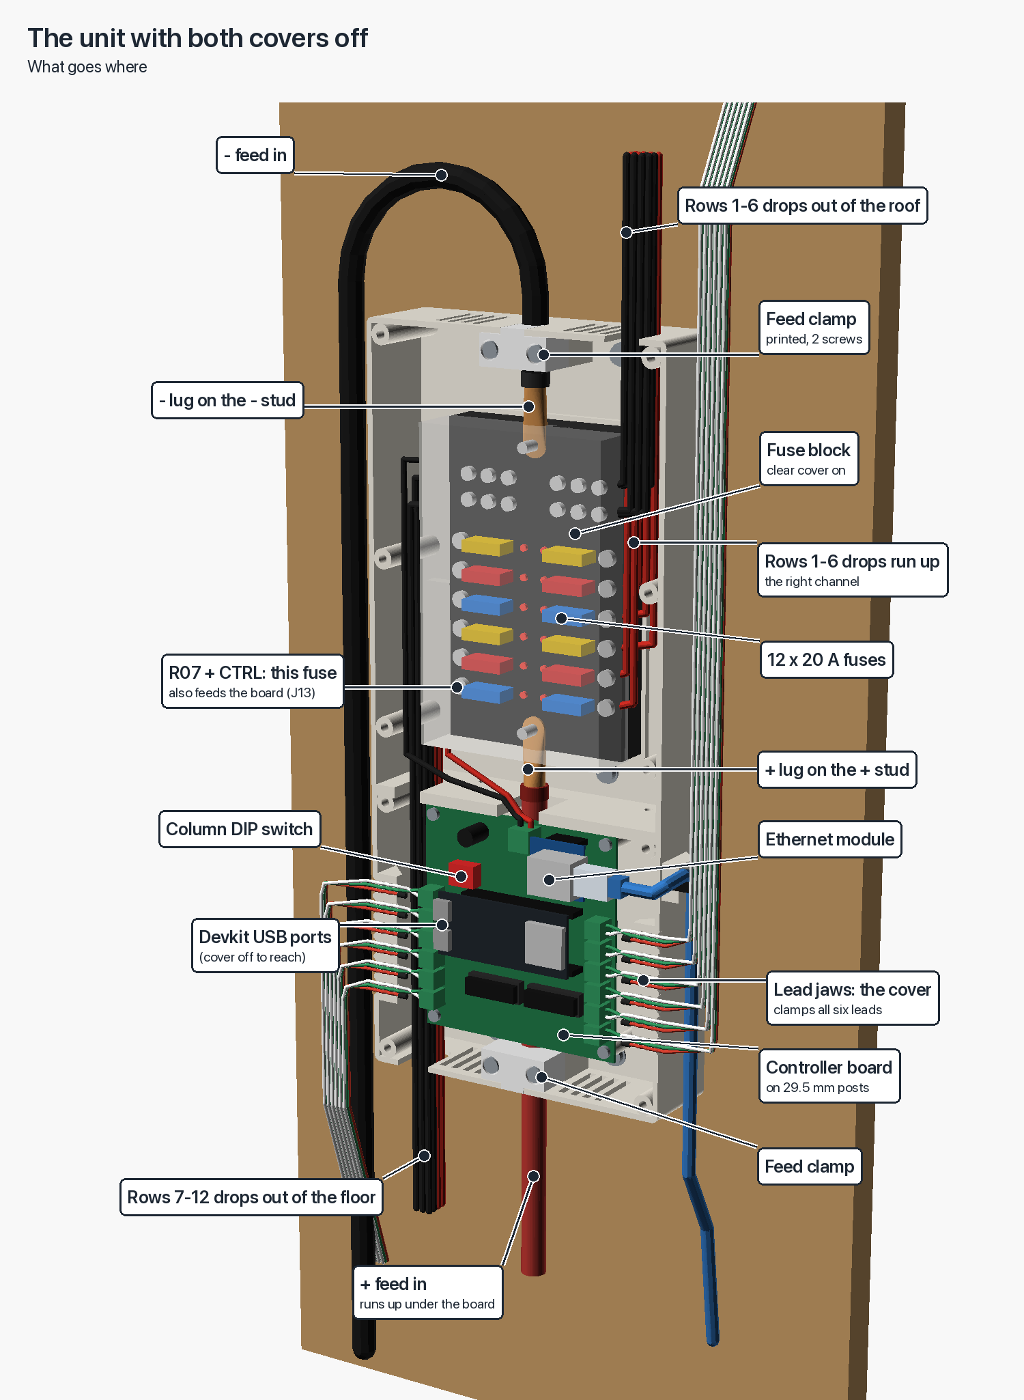
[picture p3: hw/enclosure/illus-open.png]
The unit with both covers off


### How the data leads are held

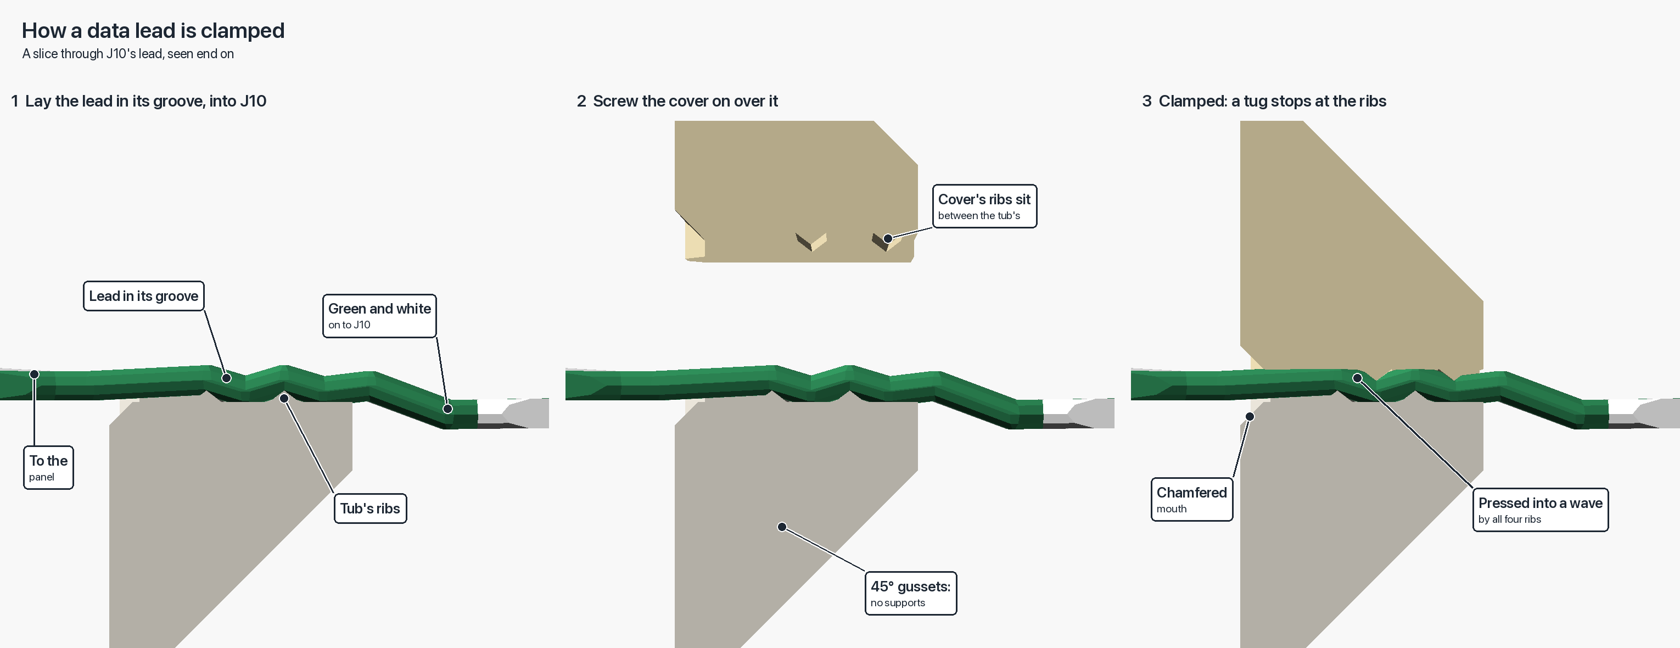
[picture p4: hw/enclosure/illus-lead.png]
How a data lead is clamped


Each panel's data lead is wired straight into its terminal, J1-J12, as the
shopping list plans. There is no connector at the box. The lead's box end is
cut off, green (data) and white (ground) go into the terminal, and red, the
panel's own 5 V, is cut back at both ends under heat-shrink. Three things
keep a tug off the terminal:

1. **Ribbed jaws in the wall.** Each lead lies flat in a groove at the
   tub/cover joint. The cover's ribs sit between the tub's, so its four
   screws press all six leads on a side into a slight wave. A tug would have
   to drag the lead through the wave.
2. **A P-clip on the door**, within about 10 cm of the box, for each side's
   six leads. E-2 already asks for a clamp on both sides of the hinge. This
   one also holds the leads while the cover is off.
3. **Slack inside**: a small bow between the jaws and the terminal.

You unplug a panel at the panel end, where the lead's own latch is, the same
as its power drop. Rev A held a JST housing in the wall instead. Whichever
half sat there, either its lock was out of reach inside the box or the leads
needed crimping male at both ends, so it is gone.

### How the box mounts to the door

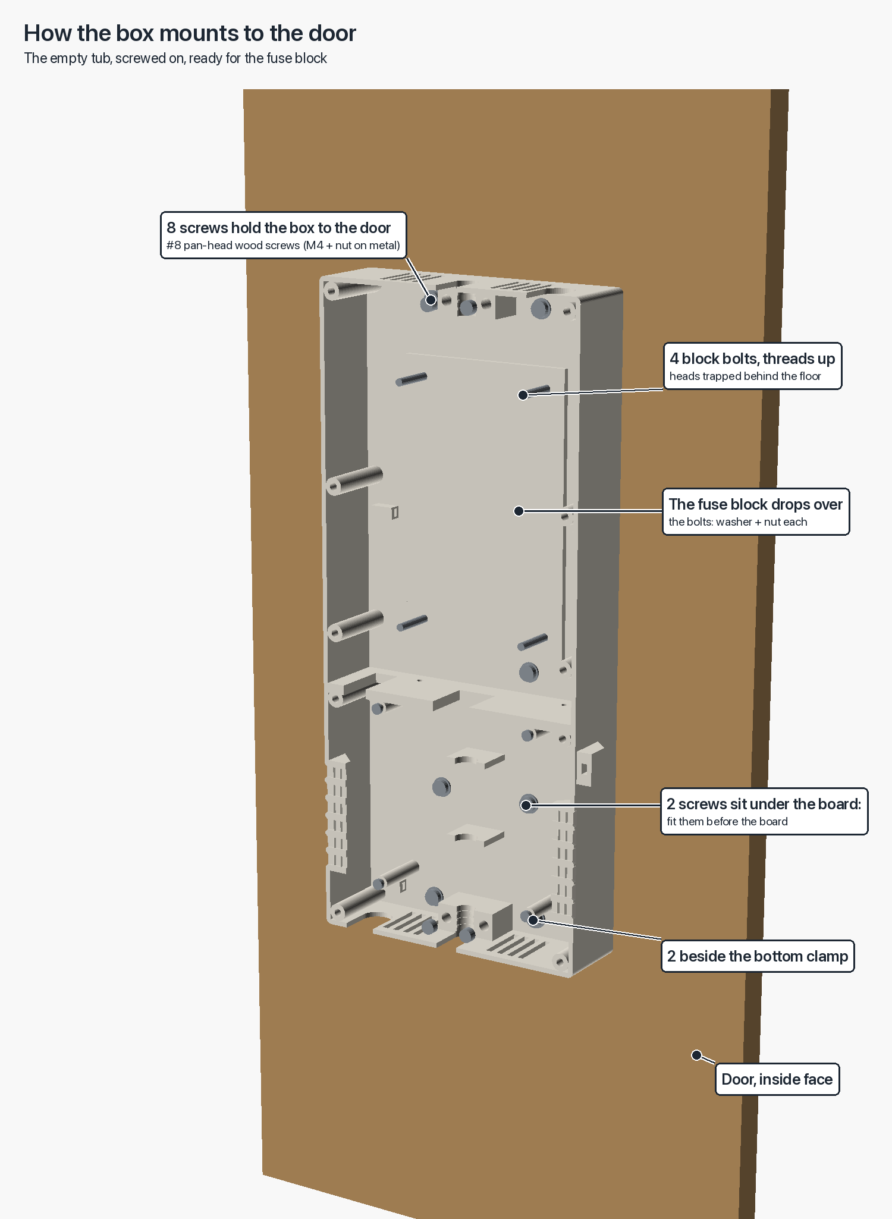
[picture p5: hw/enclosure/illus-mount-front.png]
How the box mounts to the door


The tub, the back half, screws flat to the inside face of the door with 8
screws through its 3 mm floor, into 4.5 mm holes: two by the roof clamp, two
in the gallery above the divider, two under the board and two by the floor
clamp. For the split tub, four are in each half. Fit them before anything
goes in the box, because two end up under the board. The covers screw to the
tub separately, so the tub never comes off the door to change a fuse or reach
the board.

| Door | Door screws, 8 per box |
|---|---|
| 3/4 in wood or plywood | #8 x 5/8 in pan-head wood screw. About 12 mm bites into the door and 7 mm stays behind it |
| 1/2 in wood or plywood | #8 x 1/2 in pan-head wood screw |
| sheet steel, 1-2 mm | #8 x 1/2 in pan-head sheet-metal screw into a 3.2 mm pilot hole, or M4 x 10 pan head with a nut behind |
| hollow-core | a plywood backer panel glued and screwed to the door first; the skin alone won't hold a screw |

A screw should reach no further than 3 mm (the floor) plus about two thirds
of the door's thickness. The loaded unit weighs about 1.5 kg, so eight #8s
are far more than it needs.

The fuse block has its own four M4 bolts. Their hex heads sit in pockets in the
back of the floor, trapped between the tub and the door so they can't turn, with
the threads standing up through the floor. The block drops over them and takes
a washer and nut on each.

**Closing it up.** The controller cover takes 4 M3 x 12 socket-head screws and
the fuse lid takes 6, all into brass heat-set inserts in the tub's corner
bosses. The screw heads sit at the bottom of 6.5 mm counterbores, so use a
2.5 mm hex key with a long arm. Fit the cover first. Its jaws clamp the data
leads and its tongue closes the floor drop slot, so before it goes on each
lead should lie flat in its labelled groove, and the rows 7-12 drops should
be tied down in the bottom of the floor slot. The lid's tongue does the same
for the rows 1-6 drops in the roof slot. Tighten each screw until its cover
sits flat on the tub all round, then stop. The grip on the leads and drops is
set by the geometry, not by torque, and a brass insert in PETG strips if you
lean on it.

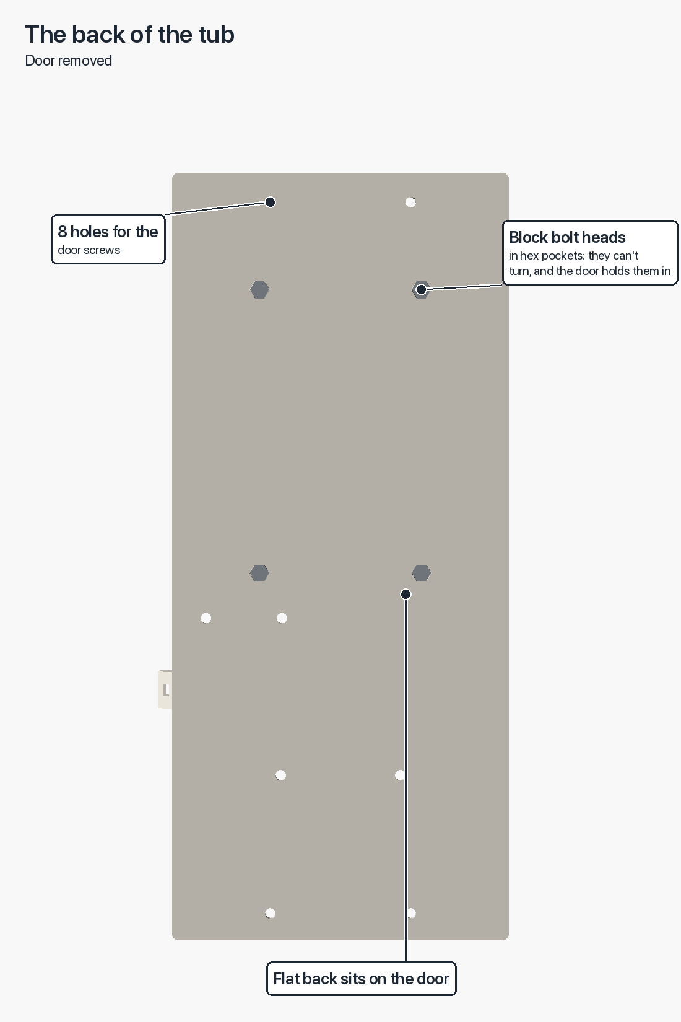
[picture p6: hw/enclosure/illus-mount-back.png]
The back of the tub


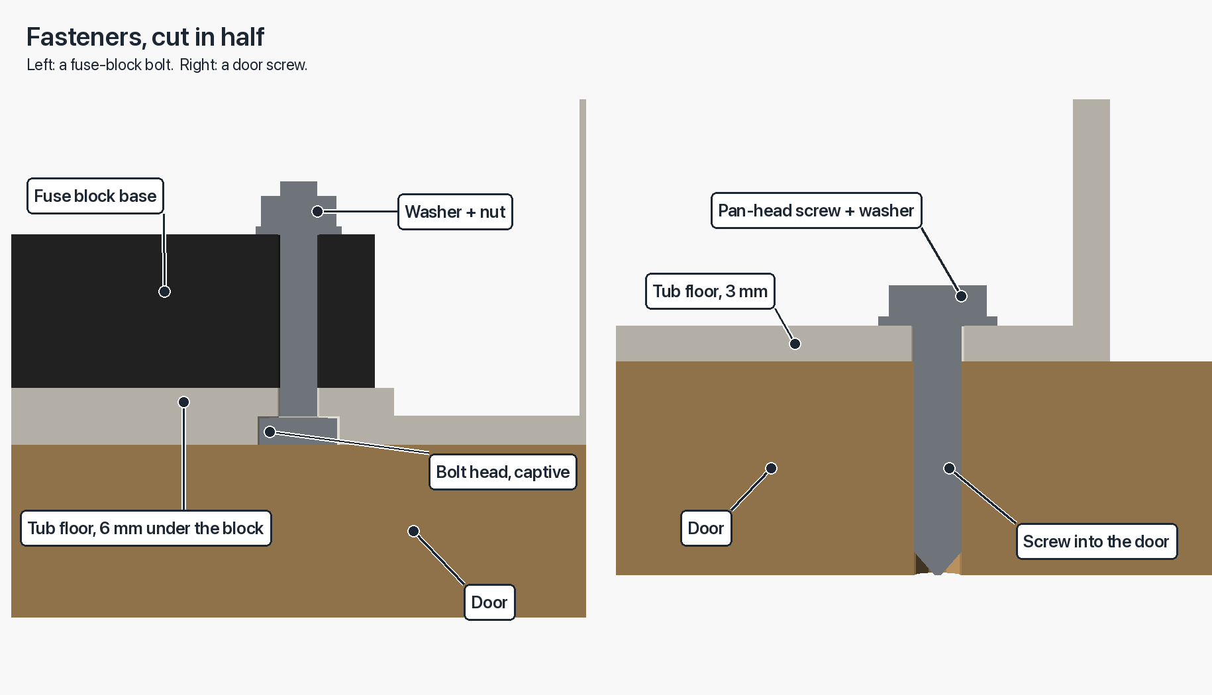
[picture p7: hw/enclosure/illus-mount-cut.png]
Fasteners cut in half


### More views

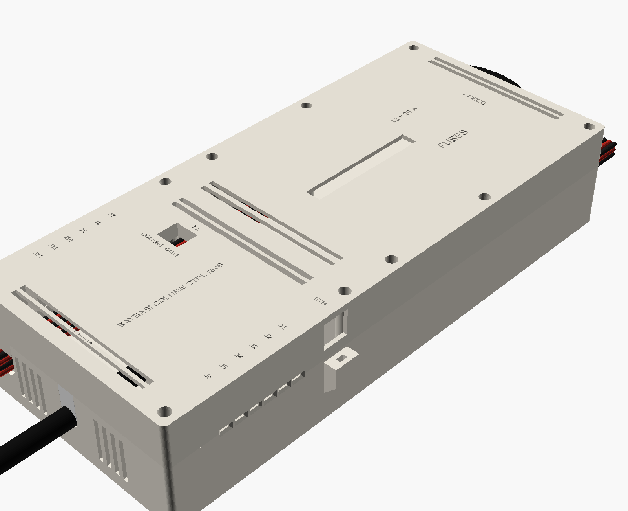
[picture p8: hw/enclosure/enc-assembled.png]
closed

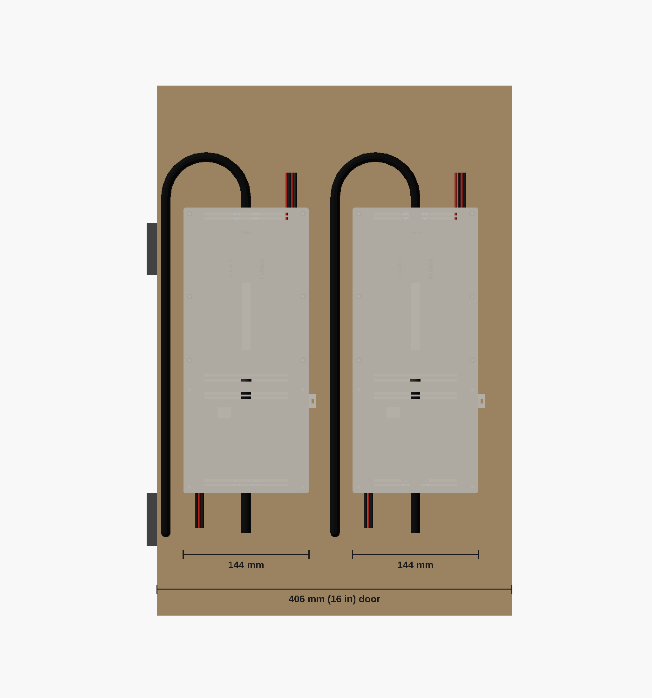
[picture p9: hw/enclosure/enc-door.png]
two on a door


## Design decisions

**The block stands on end, - end up.** DAIER's drawings of the FB-1714 put
the + and - studs on the centreline at opposite ends. The block's own cover
lets a cable reach a stud only through a notch in that end wall, so each 6 AWG
lug must point straight out along the block's axis. E-1 draws the block lying
across the box. That puts both feeds out through the side walls. Block, lug,
heat-shrink and clamp at each end come to 215 mm of box before either cable
turns, so two do not fit on the door.
Standing the block on end, the - feed drops straight in through the roof and
the + feed comes straight up through the floor. Neither cable bends inside the
box. Both come from the supply at the foot of the wall, so the - climbs the
left side of the box and bends over into the roof clamp. At the 45 mm minimum
radius that takes about 26 mm beside the box and 60 mm above it. The rows 1-6
drops leave the right of the roof, clear of the bend.

**The + feed runs under the board.** The board sits below the block, so the
+ cable passes under it on the centreline. The board stands on 29.5 mm posts
to clear it. **That sets the box depth, not the block**:
`blk_lug_z` + half the cable + 2 mm + the board's solder tails. The depth
moves 1:1 with `blk_lug_z`, which answers the "enclosure depth" open item on
the electrical sheet once you measure it.

**The board turns 90 degrees clockwise.** J13 faces up, towards the block that
feeds it, about 40 mm from the + stud. J1-J6 and the RJ45 face the
right wall, and J7-J12 and the devkit's USB face the left wall.

**Half the column goes up, half down (E-3).** The right half of the box serves
rows 1-6. The right fuse column's six drops and the six negative screws on
that side go up the right channel and out of the roof slot, and J1-J6's leads
leave the right wall and turn up. The left half serves rows 7-12. Its drops
go down the left channel, through a notch in the divider, past the board
between the cover's corner screw and the board's post, and out of a floor slot
beside the + clamp. J7-J12's leads leave the left wall and turn down. Power
leaves the ends and data the sides, so the looms part at the box (E-3 note 3).
Label the fuses to match. R07 is the left column's bottom fuse, the one
nearest J13.

**The controller shares fuse R07.** E-1 doubles the board's 5 V onto R07's
output screw, a 14 AWG ring over the drop's ring, instead of giving it its own
5 A inline fuse. So the gallery no longer holds a tap holder. Label the fuse
`R07 + CTRL`.

**Two front covers.** The fuse **lid** (6 screws) covers the block, the
gallery and the roof clamp, and a tongue on it closes the roof drop slot. The
controller **cover** (4 screws) clamps the twelve data leads, and its tongue
closes the floor drop slot. A fuse change never unclamps a data lead, and the
box never comes off the door.

**Feeds are clamped to the tub, not to a cover.** Each feed gets a split
saddle clamp: half in the tub, half a separate printed part held by 2 x M4. Its
bore is `feed_od - 0.8` with three ridges, and the clamp bottoms out on the
cradle, so the grip is set by geometry rather than by torque. The wall
opening has a bell mouth. The flexing belongs in the hinge loop, so also
P-clip each feed to the door 100-150 mm outside the box (E-2's "clamp on
both sides").

**Drops**: twelve wires a side, tied at two anchors each, and each slot is
closed over its bundle by a tongue on the lid (roof) or the cover (floor).
**Data**: six leads a side in ribbed jaws at the joint, labelled J1-J12 on
the cover. **Cat5e**: the lead plugs straight into the module through
the right wall, turns down the side, and a cable tie through the lug below the
opening holds it. (Rev A's tie block sat flat on the mounting surface with its
slot along the cable, so a tie couldn't go round the lead. The lug replaces it.)

**USB is reached by taking the cover off, not through a wall port.** A wall
port was designed and dropped. The devkit is a third-party board whose USB
position is unmeasured, the port would crowd J7-J12's leads out of the left
wall, and README section 6 says not to flash in a controller at all. With the
cover off, a USB-C plug reaches the devkit over J7-J9 and over the tub's low
wall without removing the board. See "Reflashing in place" below.

**The DIP switch is set through a window** in the cover. It is about 25 mm
down, so set it with a pick. Poles run right to left: 1, 2, SP, SP. Read ON from the
switch body; KiCad's footprint puts ON towards the bottom of the box, but
that is its convention, not the part's.

**Venting.** Slots in the floor and roof walls either side of each clamp, and
rows across both faces top and bottom. Air comes in low and leaves high on a
vertical door. The LED slot in the lid shows the blown-fuse LEDs with the lid
on.

**The tub prints in two halves.** They split at the divider between lid and
cover, each half fits a 220 mm bed, and they join with 2 x M3 through the
divider. Each half also has its own door screws. `part="tub"` is the one-piece
version, for a 330 mm bed.

## Measure before printing

The block's dimensions come from DAIER's own FB-1714 drawings: the
[dimensioned drawing](https://www.daierswitches.com/cdn/shop/products/FB-1714DimensionedDrawing_1600x.jpg)
and the [product size sheet](https://www.daierswitches.com/cdn/shop/files/FB-171412-WayBladeFuseBlockSize_1600x.jpg).
The two sheets disagree by up to 2 mm. A reseller
[listing](https://carkart.com/products/daiertek-12-way-fuse-block-12-volt-blade-fuse-block-with-led-indicator-12-circuit-fuse-box-12v-ato-atc-marine-fuse-panel-24v-wi)
identifies the DaierTek Amazon block as FB-1714, but the part in hand has not
been checked. **Treat every value below as a guess until measured.**

| Parameter | Default | Source | What it moves |
|---|---|---|---|
| `blk_lug_z` | 16 | estimated from DAIER's end view | **Box depth, 1:1.** Fit a 6 AWG lug on a stud; measure mounting face to barrel axis |
| `blk_l`, `blk_w` | 137.7, 85.1 | DAIER size sheet (138.25, 85.0 on the drawing) | box height, channel width |
| `blk_w_cover` | 88.0 | DAIER drawing | channel width |
| `blk_h` | 36.5 | DAIER drawing (35.7 on the size sheet) | assert against the lid |
| `blk_hole_px`, `blk_hole_py` | 121.0, 69.1 | DAIER size sheet; 123.25 x 70 on the drawing may be the back screws | the four block bolts. **Check on the template** |
| `blk_stud_in` | 8.35 | in line with the holes on both sheets | where the lugs sit |
| `lug_reach` | 16 | 6 AWG ring lug for M5: ~30 long less the stud's inset | gallery and roof zone height |
| `feed_od` | 11.0 | brief | clamp bore and wall slot |
| `pcb_pins` | 3.0 | assumed | board post height, depth 1:1 |
| `dk_usb_by` | 80.5 | silkscreen outline (third-party devkit) | ghost only; check the plug clears J7-J9 |
| `lead_w`, `lead_t` | 5.2, 1.7 | typical flat 3 x 22 AWG LED lead | the jaw grooves. **Calipers on one of the leads** |
| `lead_bite` | 0.6 | guess | how hard the jaws grip. **Coupon check 1** |
| `rj45_h`, `sock_h`, `hdr_spacer` | 13.5, 8.5, 2.5 | rev A, BOM, FABRICATION.md | depth, Ethernet opening |
| block bolt length | M4 x 25 | DAIER's end view shows the holes through the whole ~16 mm base; plus 3 mm of floor, washer, nut | measure the base thickness at its holes; add any extra to the bolt |

Asserts in the SCAD stop the build if a measurement makes two printed
features collide, or leaves the rows 7-12 drops no room past the board.
`openscad` echoes the box size on every run.

## Coupon and template first

Print `coupon.stl`, `template.stl` and one `clamp.stl` (about 1.5 h in
total) before the tub, which takes a day.

1. **Lead clamp.** Two insert-and-screw jaw pieces, a strip of the side wall
   each. Lay a real data lead flat in a groove, screw the halves together, and
   hang a full gallon jug of water (about 4 kg) from the lead for a minute.
   It must not creep. If it does, raise `lead_bite` by 0.2. If the lead won't
   lie flat in its groove, set `lead_w` and `lead_t` from calipers.
2. **Inserts.** Seat an M3 and an M4 heat-set insert. Adjust `m3_insert` /
   `m4_insert` if they are loose or crack the boss.
3. **Block bolt.** An M4 hex bolt head must drop into the pocket from below
   without turning.
4. **Feed clamp.** Screw the clamp onto the cradle over an offcut of the real
   6 AWG. It should grip hard enough that you cannot pull the cable through by
   hand. Adjust `feed_od` or `feed_squeeze`.
5. **Template.** Stand the block on it. All four bolt holes and the outline
   must line up, and each stud must sit on the spine running past each end.

## Print settings

PETG, not PLA: the box lives next to 60 A joints on a warm wall, and PLA
creeps under heat-set inserts. 0.4 mm nozzle, 0.2 mm layers, 4 perimeters,
5 top and 5 bottom layers, 20-25 % gyroid infill. **No supports on any
part**, and every STL is exported already in its print orientation:

| Part | Qty | Orientation | Bed | ~Time* |
|---|---|---|---|---|
| `tub-upper.stl` | 1 | floor down | 144 x 204 | 10 h |
| `tub-lower.stl` | 1 | floor down | 153 x 124 | 8 h |
| `lid.stl` | 1 | face down | 144 x 204 | 6 h |
| `cover.stl` | 1 | face down | 144 x 124 | 5 h |
| `clamp.stl` | 2 | clamping face up | 32 x 17 | 0.3 h |
| `coupon.stl`, `template.stl` | 1 | as exported | | 1 h |
| `tub.stl` (instead of the halves) | 1 | floor down | 153 x 328 | 18 h |

\*Scaled from rev A's 8 h box by volume. About 30 h and 750 g of PETG per
unit, or 240 h for all eight.

## Hardware, per unit

| | Qty |
|---|---|
| M3 x 5.7 heat-set insert | 16: 4 board posts, 4 cover, 6 lid, 2 tub joint |
| M4 heat-set insert, ~5.6 OD | 4: feed clamps |
| M3 x 12 socket head | 10: lid 6, cover 4 |
| M3 x 8 socket head | 2: tub joint, split tub only (a 12 would bottom out) |
| M3 x 6 pan head | 4: board to posts |
| M4 x 20 socket head | 4: feed clamps |
| M4 x 25 hex bolt (DIN 933), nut, washer | 4: block; length per the table above |
| #8 pan-head screw, length and type by door (table above) | 8: box to door |
| cable tie, up to 3.6 mm wide | 5: four on the drops, one on the Cat5e |
| screw-mount P-clip, 3/8 in (E-1's stock) | 2: one per side for the data leads, near the box |
| 22 AWG bootlace ferrule | 24: green and white of each data lead |
| heat-shrink, ~2.5 mm bore | 24: each red conductor, cut at both ends |

Installing the heat-set inserts uses an iron as a heat tool only. Every
electrical joint is still a crimp or a screw terminal.

## Assembly order

1. Press all the heat-set inserts in. For the split tub, the joint inserts go
   into `tub-lower` from its split face.
2. Drop the four M4 hex bolts into the pockets under the block seat, threads
   up. The door will hold them captive; tape them for now.
3. Split tub only: butt the halves at the divider and fit the two M3 joint
   screws from the gallery side.
4. **Mount the empty tub on the door** with its 8 screws. Two of them sit
   under the board, so they have to go in first.
5. Lower the block over the bolts, - end up, and fit washers and nuts.
6. **+ feed:** lay it into the floor slot and along the guides under the board
   position. Land the 6 AWG lug on the + stud and screw the floor clamp down.
7. **- feed:** lay it into the roof slot, land the lug on the - stud, and screw
   the roof clamp down.
8. Mount the board on its posts with J13 at the top. Its tails clear the
   + feed by 2 mm, so check that nothing sags onto them.
9. Drops: crimp and land them on the block. **Rows 1-6**, the right fuse
   column and the right six negative screws: up the right channel and out of
   the roof slot. **Rows 7-12**, the left column and the left negatives: down
   the left channel, through the divider notch, past the board on its left
   and out of the floor slot. Tie each bundle at both of its anchors.
10. Controller 5 V (E-1): stack the 14 AWG tap's ring on R07's output screw,
    over the drop's ring, and run it through the divider notch to J13+. Run
    J13- to a negative-bus screw the same way.
11. Data: cut each lead's box end off. Cut red back at both ends and
    heat-shrink the stubs, because it is the panel's live 5 V. Ferrule green
    and white, lay the lead flat in its groove as labelled on the cover
    (J7-J12 left, J1-J6 right), leave a small bow, and screw it into its
    terminal, data on the square pad (FABRICATION.md). Set the DIP switch.
12. Fit the cover (it clamps the leads) and the lid. Plug in the Cat5e and tie
    it below the opening.
13. Outside the box: bring the pair in from below. The + goes straight up into
    the floor clamp. The - runs up the left side of the box and bends over
    into the roof clamp, radius at least 45 mm. P-clip both to the door. Then
    P-clip each side's data leads within about 10 cm of the box, rows 1-6
    turning up the right side and rows 7-12 down the left.

**Changing a fuse:** remove the lid's 6 screws, then press the block cover's
latches and lift it off. All 12 fuses are there. R07's also feeds the controller.
Spares and the puller live in the pocket on the inside of the lid.

**Reflashing in place:** README section 6 says to flash on the bench, because
USB back-feeds the column through the board (FABRICATION.md, "known,
accepted"). If you must flash in place, **pull fuse R07 first**. That
isolates J13 from the block, so USB powers only the controller, and panel R07
goes dark until you refit it. Then take the cover off and plug in. The data
leads stay put in their grooves, held by the P-clips outside.

## Open

- **Door height** is not fixed yet. The unit needs about 430 mm including its
  feed bends.
- **The depth is 65 mm until `blk_lug_z` is measured.** Confirm the bay
  clears it with the door shut.
- **Door spacing.** Each unit needs about 26 mm clear on its left for the
  - feed and about 20 mm on its right for the rows 1-6 leads and the Cat5e.
  So place the boxes 30 mm from the hinge edge and 50 mm apart, which leaves
  38 mm at the free edge. On door 2, whose hinge is on the right, the 38 mm
  gap is at the hinge. The enc-door render shows this spacing. Check it
  against the real door and hinge.
- **Data lead size.** `lead_w` and `lead_t` are guesses for the shopping
  list's flat 3 x 22 AWG leads.
- DAIER's page lists the 24 small terminals as **M4 threaded studs**. If they
  take ring or fork terminals rather than ferrules, those lugs are longer, so
  check they still turn up inside the 24 mm channels (`side_ch`).

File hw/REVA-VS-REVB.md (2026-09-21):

# revA vs revB — pre-order verification

Run 2026-09-21, before committing to ten boards. revA is the batch-1 design
that was fabricated, assembled and validated on the bench; everything on it
checked out except the dev-kit socket pitch. The question this answers is
whether revB differs from it in exactly two intended ways and nothing else.

Method: compare the two **board files** with KiCad's own parser, not the
generators. `git show 76fae02:hw/baybasi-ctrl.kicad_pcb` is revA.

**Result: two intended changes, no unintended ones.**

## 1. Components — SW1 added, nothing else

| | revA | revB |
|---|---|---|
| parts | 63 | 64 |
| added | | `SW1` |
| removed | | none |
| footprint substitutions | | none |

## 2. Netlist — every revA connection preserved exactly

74 nets in both.

- **Only in revB:** `COL_B0`, `COL_B1`, `COL_SP0`, `COL_SP1`
- **Only in revA:** the four `unconnected-(A1L-Pin_N-PadN)` placeholders for
  pads 9, 10, 11 and 15 — which is precisely those pads ceasing to be
  no-connects and becoming the four nets above
- **Membership change on any shared net:** exactly one, `GND` gaining `SW1`
  pads 5-8

Nothing else moved. Every other net has byte-identical pad membership.

## 3. Placement — three parts moved, all deliberately

| ref | dx | dy | rotation |
|---|---|---|---|
| A1R | +2.54 | 0 | unchanged |
| U1 | +2.50 | 0 | unchanged |
| U2 | +2.50 | 0 | unchanged |

A1R is the pitch change. U1/U2 follow it: leaving them put would have squeezed
the A1R-to-U1 channel from ~7 mm to ~4.5 mm, and the router could not keep the
B.Cu pour continuous through it. Every other part — all twelve terminals, both
W5500 headers, the whole power section, every resistor — is bit-identical.

## 4. Physical / fab

| | revA | revB |
|---|---|---|
| board outline | 4 points, 100.1 x 95.1 mm | identical |
| drill sizes | 0.8, 1.0, 1.2, 1.3, 3.2 | **identical** |
| track widths used | 0.25 mm only | 0.25 mm only |
| tracks | 444 | 495 |
| vias | 105 | 106 |

No new drill size, no new track width, same outline. Nothing that changes the
fab tier or the tooling.

## 5. The twelve output chains — zero differences

Each output was walked end to end: devkit pad -> buffer input -> buffer output
-> 330R series resistor -> terminal, with the 10k pull-down on the terminal
side.

    D1   A1L.4  -> U1.2  ... U1.18 -> R1.1  | R1.2  -> J1.1  + R16.1
    D2   A1L.5  -> U1.3  ... U1.17 -> R2.1  | R2.2  -> J2.1  + R17.1
    D3   A1L.6  -> U1.4  ... U1.16 -> R3.1  | R3.2  -> J3.1  + R18.1
    D4   A1R.4  -> U1.5  ... U1.15 -> R4.1  | R4.2  -> J4.1  + R19.1
    D5   A1R.5  -> U1.6  ... U1.14 -> R5.1  | R5.2  -> J5.1  + R20.1
    D6   A1R.18 -> U1.7  ... U1.13 -> R6.1  | R6.2  -> J6.1  + R21.1
    D7   A1R.10 -> U2.2  ... U2.18 -> R7.1  | R7.2  -> J7.1  + R22.1
    D8   A1R.9  -> U2.3  ... U2.17 -> R8.1  | R8.2  -> J8.1  + R23.1
    D9   A1R.8  -> U2.4  ... U2.16 -> R9.1  | R9.2  -> J9.1  + R24.1
    D10  A1R.7  -> U2.5  ... U2.15 -> R10.1 | R10.2 -> J10.1 + R25.1
    D11  A1R.6  -> U2.6  ... U2.14 -> R11.1 | R11.2 -> J11.1 + R26.1
    D12  A1R.17 -> U2.7  ... U2.13 -> R12.1 | R12.2 -> J12.1 + R27.1

**Chains differing from revA: 0.** Series termination and pull-downs all
present and on the same nets. This is the set that matters most: D1-D3 and D7
are the ones proven with a panel on hardware, and the rest are identical in
construction.

## 6. Where the new traces run

| net | length | layers | vias |
|---|---|---|---|
| COL_B0 | 22.6 mm | B.Cu + F.Cu | 1 |
| COL_B1 | 45.1 mm | B.Cu | 0 |
| COL_SP0 | 52.1 mm | B.Cu + F.Cu | 2 |
| COL_SP1 | 49.2 mm | B.Cu + F.Cu | 2 |

All four run SW1 (x 24) up to A1L (x 34-38), mostly on the back layer, in
y 37-77. They stay clear of the Ethernet SPI cluster (x 3-27, y 8-34) with
about 3 mm to spare, and they carry a DC level read once at boot, so length
and layer changes are irrelevant to them.

## 7. DRC

    revB: 0 violations, 0 unconnected, 7 warnings
    revA: 0 violations, 0 unconnected, 7 warnings
    all 7 in both are lib_footprint_mismatch — the same baseline

## Still needs a human before the order

1. **SW1's CPL rotation (270 deg).** Every other rotation offset in
   `make_cpl.py` was read off JLCPCB's placement overlay; this one was
   reasoned by analogy with the DIP sockets. A 180 error maps pads 1-4 onto
   5-8 and wires the column bits to GND. **Check it in their preview.**
2. **revB is a fresh autoroute.** DRC-clean is not the same as the
   field-proven routing revA carries. The net-level comparison above says the
   connectivity is identical, which is the part that matters, but the copper
   is new.
3. **`min_resolved_spokes` is back at 1**, matching what revA was fabricated
   with. At 2 the board has 5 starved-thermal errors that need layout work.

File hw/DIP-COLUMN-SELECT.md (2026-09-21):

# Column select by DIP switch — spec for batch 2

Status: **proposed 2026-09-20**, not built. Decide before the batch-2 layout.

## The problem it solves

A board's column currently lives in NVS and is set over the network by
`baybasi assign <mac> <column>`. That works, and `identify` (added 2026-09-20)
makes it usable on a wall. But it rests on a binding no machine can check:
**which MAC is in which physical column.** The MAC is the ESP32's factory eFuse
value, not printed on the jack, the module or the board, so today the answer is
"read it on the bench and put a sticker on". A workflow that needs a sticker to
function has a gap in it.

DIP switches close it by kind, not by degree. `identify`, DHCP reservations and
power-on ordering are all ways of *discovering* a binding a human established
and must not forget. **Switches make the hardware state its own position.**
Replace a board: set the switches to match the slot, done — no laptop, no
discovery, no MAC lookup, no Pi.

## What it retires

The production addressing is a pure function of the column:

| column | IP | ddp_id |
|---|---|---|
| 0 | 192.168.50.11 | 10 |
| 1 | 192.168.50.12 | 11 |
| 2 | 192.168.50.13 | 12 |
| 3 | 192.168.50.14 | 13 |

`ip = 192.168.50.(11 + column)`, `ddp_id = 10 + column`. So a board that knows
its column derives its whole network identity. **Commissioning disappears
entirely** for boards with switches fitted: power up, read switches, take the
static address, start receiving. No discover, no assign, no reboot-on-assign,
no NVS write, nothing for the operator to type or get wrong.

`assign` and `identify` stay, for batch-1 boards and as a fallback.

## Encoding — 2 positions, GPIO 9 / 16

**Revised 2026-09-20.** The first draft used three positions, the third an
ENABLE, so that "no switches set" was distinguishable from "column 0". Two
bits gives four codes and that wanted five states, hence the extra pin.

Dropped, because the fifth state was not worth it:

- The only boards with no DIP are batch 1, which are bench-only - wrong socket
  pitch, never going in the wall. A build flag covers them if one ever needs a
  column.
- "Someone forgot to set the switches" is real - all four boards read 00, all
  claim column 0, all take .11, and four hosts on one IP is an ugly failure.
  But it is trivially visible in software: four boards announcing col:0. That
  belongs in a `baybasi verify` check, not in a GPIO.

What the two-bit version buys back is worth more than the state it gives up:
**00 / 01 / 10 / 11 needs no explanation.** The silkscreen is two labels, not a
truth table, and nobody setting a board on a ladder needs this document open.

## Pin assignment

GPIO budget on this design: 12 outputs, SPI x4, INT, RST, /OE, sync, status =
21 pins. Free and safe (clear of USB 19/20, strapping 0/3/45/46 and the N16R8's
octal PSRAM 35/36/37): **9, 16, 17, 18**. This uses three and leaves 18 spare.

| switch | GPIO | meaning |
|---|---|---|
| SW1 | 9  | column bit 0 |
| SW2 | 16 | column bit 1 |

Switch closed pulls the pin to GND; open floats to the internal pull-up. The
firmware inverts, so **closed = 1**.

| column | SW2 | SW1 |
|---|---|---|
| 0 | off | off |
| 1 | off | **on** |
| 2 | **on** | off |
| 3 | **on** | **on** |

GPIO 17 and 18 stay free.

Silkscreen: label the poles `2` and `1` by binary weight and print
`COLUMN = 2+1`. Two labels, no table, nothing to look up.

**Switches are authoritative on any board that has them.** There is no merge
with NVS and no enable bit - one source of truth was the whole point. An
`assign` command aimed at such a board is refused with an ack saying why.

**Consequence, accepted:** a board with no DIP fitted reads 00 and becomes
column 0, so batch-1 boards cannot be commissioned over the network under this
firmware. They are bench-only and one at a time, where column 0 is what you
want anyway. If that ever changes, a `-DNO_COLUMN_DIP` build restores the NVS
path.

## Circuit

Nothing but the switch. Three poles to three GPIOs, common side to GND,
internal pull-ups in firmware. No resistors, no caps. Read once at boot in
`identity::begin()`; do not poll (changing a column at runtime is not a thing
we want to support, and a reboot is the honest way to apply it).

## Part and JLCPCB assembly

**Checked against the JLCPCB assembly parts library, 2026-09-20.** Two earlier
recommendations in this doc were wrong and are corrected here.

### Use C99418

| | |
|---|---|
| Part | **C99418**, DongGuan KINGTEK **DSWB04LHGET** |
| Type | 4 position, through-hole, 2.54 mm pitch, SPST slide, red |
| Rating | 24 V / 25 mA - fine for logic-level GPIO |
| Stock | **61,704** |
| Price | **$0.2094** at qty 1 and at 40+ |
| Class | Extended, so a one-time setup fee |
| JLCPCB | https://jlcpcb.com/parts/componentSearch?searchTxt=DSWB04LHGET |
| LCSC | https://www.lcsc.com/product-detail/C99418.html |

### Two corrections, and a lesson about their search

**"Prefer an SMD 2-position DIP switch" was wrong.** JLCPCB stocks no
2-position DIP switch for assembly. `CSWDIP-2P` (C9900014698) exists in the
library at stock 0, marked Consign Part - you buy and ship them yourself.

**Then C99987 (Diptronics EI-04) was wrong too**, or at least much worse: 103
in stock at $0.52, which had me writing warnings about thin stock. C99418 is
the same 4-position THT 2.54 mm part at **a quarter the price and 600x the
stock**, so the thin-stock caveat simply disappears.

The lesson is about the tool, not the part. **JLCPCB's keyword search is
unreliable**: searching "DIP Switch" returns 12 parts and does not include
C99418 at all, despite it being a DIP switch with 61,704 in stock. Searching
the manufacturer part number finds it immediately. Browse the category or
search the MPN; do not trust a keyword search to be a survey of what they
have.

Alternatives found the same way, if C99418 ever goes: **C5145064**
(DSWB04LHGETR, KE-SWITCH, 915 in stock, $0.22) and **C99987** (Diptronics
EI-04, 103, $0.52). All the same 4 position THT 2.54 mm footprint.

### Use the 4-position part, and wire all four poles

The EI-04 being 4-position is not a compromise - it is better than the
2-position this doc specced. Use poles 1-2 for the column and **wire poles 3
and 4 to the free GPIOs 17 and 18**. Two spare configuration bits, already
placed, already routed, costing nothing. Leave them unread in firmware until
there is something to read.

That also empties the GPIO budget, which is the tradeoff: after this there are
no free pins on this design. Worth it for switches that are placed anyway.

Through-hole is not a problem - JLCPCB already places the sockets, terminal
blocks, inductor and electrolytics on this board, so THT assembly is in the
order regardless.

Record the part number in FABRICATION.md next to the devkit's, and re-check
stock before finalising - 61,704 is comfortable, but so was every part that
later went obsolete.

### If C99418 is out of stock

**Pin header plus shunts.** Headers are stocked in enormous depth (C2333,
2.54 mm 2x40P, 25,000+ in stock, $0.32) and snap to whatever length is needed.
A 1x3 with the centre pin to GND takes two shunts. Cheaper and never
unavailable; the cost is loose shunts, which inside a sealed enclosure is a
part you will eventually drop and lose.

**Or consign.** Buy 2-position SMD DIP switches from LCSC and ship them to
JLCPCB. Most control, most hassle, and it puts a manual step in every reorder.

## Firmware

`config.h`:

    static constexpr int PIN_COL_B0 = 9;
    static constexpr int PIN_COL_B1 = 16;
    static constexpr uint32_t COL_IP_BASE  = 11;   // 192.168.50.(11 + column)
    static constexpr uint8_t  COL_DDP_BASE = 10;   // ddp_id = 10 + column

`identity.cpp`, in `begin()`, before the NVS read:

    pinMode(PIN_COL_B0, INPUT_PULLUP);
    pinMode(PIN_COL_B1, INPUT_PULLUP);
    delayMicroseconds(50);              // let the pull-ups settle
    {
        const int8_t col = (int8_t)((!digitalRead(PIN_COL_B1) << 1)
                                  |  !digitalRead(PIN_COL_B0));
        // Everything else follows from the column - see the table above.
        // Nothing is written to NVS: the switches ARE the configuration, and
        // persisting them would create a second source of truth that can
        // disagree with the hardware.
        ...
    }

Rules that matter:

- **Switches win over NVS, always.** Two sources of truth is the failure this
  is meant to remove, so there is a precedence, not a merge.
- **Do not write the switch-derived column to NVS.** A board moved to another
  slot must follow its switches, not a stale memory of where it used to be.
- **An `assign` command aimed at a switch-configured board should be refused,
  with an ack that says why.** Silently accepting it and then ignoring it on the
  next boot is worse than refusing.
- Announce the source in the heartbeat (`"col_src":"dip"` / `"nvs"`), so
  `baybasi discover` shows at a glance which boards are self-configured.

## gen_pcb.py

- One **4-position** DIP footprint (Diptronics EI-04, THT 2.54 mm), near the
  devkit socket and reachable with the board mounted - it will be set with the board in hand, but read with it in
  place.
- Four traces to devkit pads for GPIO 9, 16, 17, 18, plus a common GND.
  Poles 3 and 4 are spares - placed and routed now, unread until needed.
- Silkscreen: poles 1 and 2 marked `1` and `2` by binary weight with
  `COLUMN = 2+1`; poles 3 and 4 marked `SPARE`. Mark the ON direction.
- Re-run the DRC/route pass; this is the first new footprint since revA.

## Honest cost

The batch-2 change list was one line (`A1L/A1R` 22.86 -> 25.4 mm). This adds a
footprint, four traces, silkscreen and a routing pass, plus firmware and a new
part in the BOM. It is a real increase in respin scope and wants a careful DRC.

Worth it on the grounds that the respin is happening anyway, the marginal
layout work is small, and it removes an entire class of install-day error -
including the one that silently duplicates a quarter of the wall.

## Follow-on: `baybasi verify`

Two bits means "switches never set" reads as column 0, so four unset boards
all claim column 0 and all take 192.168.50.11. Four hosts on one address is an
ugly, confusing failure - and a cheap one to catch. Before any media:

- listen for announcements
- assert four boards, columns 0-3 exactly once each, on the IPs wall.yaml
  expects
- report anything missing, duplicated or unexpected

It cannot confirm physical position - `baybasi pattern id` is still the check
that closes that loop - but it catches every wiring-independent mistake,
including the one this encoding trades away.

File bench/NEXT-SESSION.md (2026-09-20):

# Baybasi — handoff, 2026-09-19

Read `bench/STATE.md` first for the volatile bench state (IPs, the temporary
config hack, what is flashed). The hard-won findings are in memory:
`baybasi-fw-first-run`, `baybasi-fw-first-build`, `baybasi-batch1-bringup`,
`baybasi-power-distribution`, `ws2812-unpowered-panel-kills-gpio`.

## Where it stands

**One controller board is fully validated on hardware.** Power, reverse
protection, both rails, /OE through the socket, U1, the series resistors, the
output terminals, the W5500, Ethernet, DHCP, discovery and DDP.

**Video rate is proven, and at scale.** 40 s of `baybasi pattern flow` -
a pattern where 100 % of pixels change every frame:

    frames=1958  shown=1952  torn=0  gaps=1  malformed=0  oversize=0
    show(): avg 5078 us     heap flat     sender 30.00 fps, 0 send errors

`show()` is **5.08 ms of a 33.3 ms budget - 15 % duty, a ~197 fps ceiling**.
That figure is for **all twelve outputs**: the LCD_CAM driver clocks every lane
in parallel whether a panel is attached or not, so the other nine panels cost
nothing in time. Network is 2.2 Mbps of 100. Twelve panels of 30 fps video is
not a stretch for this board.

**Also proven:** the column-serpentine map (the `bars` pattern renders a
*legible* "1", which validates the 2-D mapping, not just chain order) and the
channel order (`CHANNEL_MAP = {2,0,1}`, measured).

## What to do next, in order

1. ~~**The DHCP gap in `fw/src/net.cpp`.**~~ **DONE 2026-09-19.** A board with
   no address of its own now waits `DHCP_WAIT_MS` (8 s) and then takes
   `192.168.50.<MAC-derived>`. Proven on hardware against a laptop with no
   DHCP server: the board took 192.168.50.125, announced every 2 s, and
   `baybasi discover` listed it as unassigned.

   Two things that were NOT in the original one-line plan:
   - `linkUp()` was `g_link && ETH.linkUp()`, and `g_link` was only ever set
     from `ARDUINO_EVENT_ETH_GOT_IP`. An address the board sets itself raises
     no such event, so the fallback alone would have changed nothing. It now
     reads `ETH.linkUp() && ETH.hasIP()`.
   - The wait is ROLLING, not boot-time. The first version armed once at boot;
     a board that got a lease and then lost it sat at 0.0.0.0 for ever and
     needed a power cycle. That was caught on hardware, not in review.
2. **Commissioning is now usable.** DONE 2026-09-19: `baybasi identify <mac>`
   and `baybasi clear <mac>` exist (both were implemented in ControlPlane and
   unreachable), identify floods the whole column at 2 Hz instead of blinking
   a 2 mm LED inside an enclosure, and a second board can no longer be given a
   column that another board holds. Confirmed on hardware: 12 flashes in 6 s,
   8 in 4 s.

   Install-day plan: commission each board on the BENCH where you can see it
   and put a physical label on it. Keep identify for field recovery - a board
   swapped out, or a label that fell off.

3. **Commission this board.** `baybasi assign ae:27:6e:a5:83:8d 0`. Retires the
   `bench/wall-bench.yaml` ddp_id hack. It reboots onto 192.168.50.11, so this
   also means moving to the pixel-segment addressing.
4. **Strip the debug instrumentation from `fw/src/main.cpp`** - loop counters,
   `acquire()` null counter, show() timing. Earned its keep; noise now.
5. **Real media end to end.** `flow` proves synthetic frames; the actual use
   case is video and images through `baybasi add` / `driver`. That exercises
   decode, scaling and the playlist, none of which have touched hardware.
6. ~~**Outputs J4-J12.**~~ U2 and A1R VALIDATED 2026-09-20 via the step-6
   jumper rig (J4 -> 4 pixels, J7 -> 7). Nothing structural on the PCB is
   unknown now. J8-J12 are individual traces, still untested, one screw
   terminal each if wanted. Original note: Needs both devkit rows, so either the 14 breadboard
   jumpers (table in `hw/BRINGUP.md` step 6) or a devkit with headers soldered
   in the board as a jig.
7. **Batch 2 PCB.** Now a ONE-LINE change: A1L/A1R 22.86 -> 25.4 mm in
   `gen_pcb.py`. The co-routed power+data question is DECIDED 2026-09-20 -
   panel power stays off the board, run separately; see FABRICATION.md. All
   seven defects from the deep QA are already in revA, and U1, U2, A1L and
   A1R are all proven on hardware, so nothing else needs to change.

   Before ordering: record the exact devkit vendor and part number in
   FABRICATION.md. Once the board is cut for 25.4, a reorder that quietly
   ships a different pitch puts you straight back into the socket problem.

## Traps that cost real time tonight

- **Always `pkill -f "baybasi.*pattern"` before any visual test.** A stray
  sender left running by hand sent 7200 frames over four minutes and silently
  interleaved with every colour measurement. "Flashing" or colours that will
  not sit still is exactly what that looks like.
- **Do not reason about the colour chain - measure it.** CHANNEL_MAP ->
  reinterpret_cast to CRGB -> FastLED EOrder -> panel wiring. Predicting that
  composition gave the wrong answer twice.
- **The IDF version is a window, not a floor.** 5.4.x only. `<=5.3` will not
  compile, 5.5 breaks the LCD i80 bus at runtime. Do not "upgrade" the platform
  without re-running the frame-rate test on hardware.
- **Three different MACs.** Commission with the firmware's `ae:27:6e:a5:83:8d`.
- **`firmware.factory.bin` does not exist on the 54.x platform.** Flash four
  images at offsets. A missing file made one flash silently no-op; the tell was
  the panic log's `ELF file SHA256` not changing between builds.

## Uncommitted

Everything from tonight is uncommitted on `master` (last commit `78ec85f`).
Modified: `fw/platformio.ini`, `fw/src/{config,framebuf,leds,main,net,status}`,
`sw/baybasi/{control,patterns}.py`, `hw/FABRICATION.md`, `HANDOFF-software.md`.
New and untracked: `bench/`, `fw-bench/`, `hw/BRINGUP.md`.
**Nothing has been committed - that is deliberate, ask before committing.**

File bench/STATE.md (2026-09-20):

# Bench state — 2026-09-19, end of the first-run session

Volatile things that are NOT in the memory files and will not survive a reboot
or a /tmp clean. Everything durable is in the `baybasi-fw-*` memories.

## The board right now
- **Uncommissioned.** `column=-1`, so `ddp_id` is the default **1**.
- MAC to commission with: **`ae:27:6e:a5:83:8d`** (the firmware's, NOT esptool's
  `ac:...:8c`, NOT the wire's `aa:...:8d`).
- On the **home LAN by DHCP**, last seen **192.168.1.121**. This CHANGES across
  reboots - it was .180 earlier. Never hard-code it; find it with
  `baybasi discover` or by listening on udp/4049.
- On a segment with **no DHCP server** it now takes **192.168.50.125**, derived
  from its MAC and stable across reboots. Any board: the range is .64-.239.
- Firmware: `fw/` built on platform **54.03.21-2** (Arduino 3.2.1 / IDF 5.4.2),
  FastLED S3/I2S, octal PSRAM. Verified 30 fps, shown==frames, colours correct.

## Temporary hacks in force
- **`bench/wall-bench.yaml`** is `config/wall.yaml` with column 0's `ddp_id`
  changed from 10 to **1**, so the UNCOMMISSIONED board accepts data packets.
  Without it every data packet is rejected and only the broadcast PUSH lands
  (`frames=0`, `pkts` climbing). Use `baybasi --config bench/wall-bench.yaml`.
  `--config` is a GLOBAL flag - it goes BEFORE the subcommand.
  Delete this once the board is properly commissioned.
- **Debug instrumentation is still in `fw/src/main.cpp`**: loop-iteration
  counter, `acquire()` null counter, and show() avg/max timing, all reported in
  logSummary. Useful; strip before production.
- With the devkit half-seated in A1L, only **J1-J3** are reachable. D4-D12 need
  the breadboard jumpers (hw/BRINGUP.md step 6) or a jig-soldered devkit.
- **BOTH BUFFERS AND BOTH SOCKET HALVES ARE NOW PROVEN** (2026-09-20, step-6
  jumper rig): D4 on J4 showed 4 white pixels and D7 on J7 showed 7. D4 was the
  first signal ever through A1R; D7 is the first ever through U2, so it proves
  that buffer, its supply and its enable. J8-J12 are individual traces on a
  layout now shown correct in principle, and remain untested.

## Discovery does not cross to Wi-Fi

`baybasi discover` showed nothing all through the first session, with the
board announcing correctly the whole time. The announce is a limited
broadcast (255.255.255.255), and broadcast does not appear to reach wireless
clients on this network - the UniFi gear filters it. Run the utility from a
machine WIRED to the same segment. Not a problem for the wall, where the Pi is
wired to the pixel segment, but it will waste an afternoon on the bench.

Tested directly: laptop on the monitor's Ethernet port (`en3`, service name
"Display Ethernet"), board straight into it, no DHCP server anywhere. A
TP-Link USB-Ethernet adapter was tried first and never established a link -
suspect that adapter, not the board.

## How to drive it
    pkill -f "baybasi.*pattern"        # ALWAYS - a stray sender ruins every test
    cd sw && .venv/bin/baybasi --config ../bench/wall-bench.yaml \
        pattern <name> --brightness 0.1 --target <ip>

Flash (four images; `firmware.factory.bin` exists only on the 55.x platform):
    esptool.py --chip esp32s3 --baud 460800 write_flash \
      0x0 bootloader.bin 0x8000 partitions.bin \
      0xe000 boot_app0.bin 0x10000 firmware.bin

After a BOOT-dance flash the S3 sits in ROM download mode: silent on serial AND
absent from the network. Neither `esptool --after hard_reset` nor DTR/RTS gets
it out. **Tap RST.**

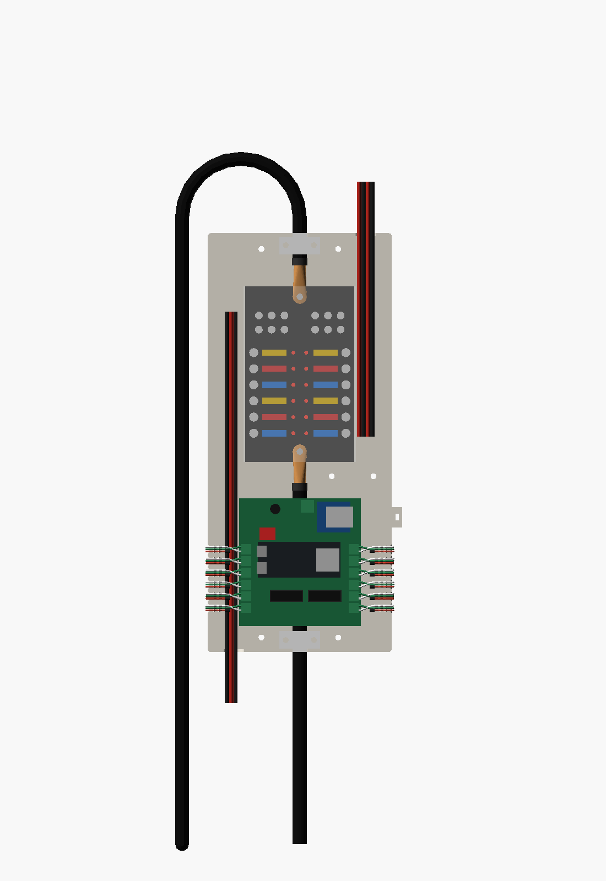
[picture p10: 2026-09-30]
hw/enclosure/enc-open.png

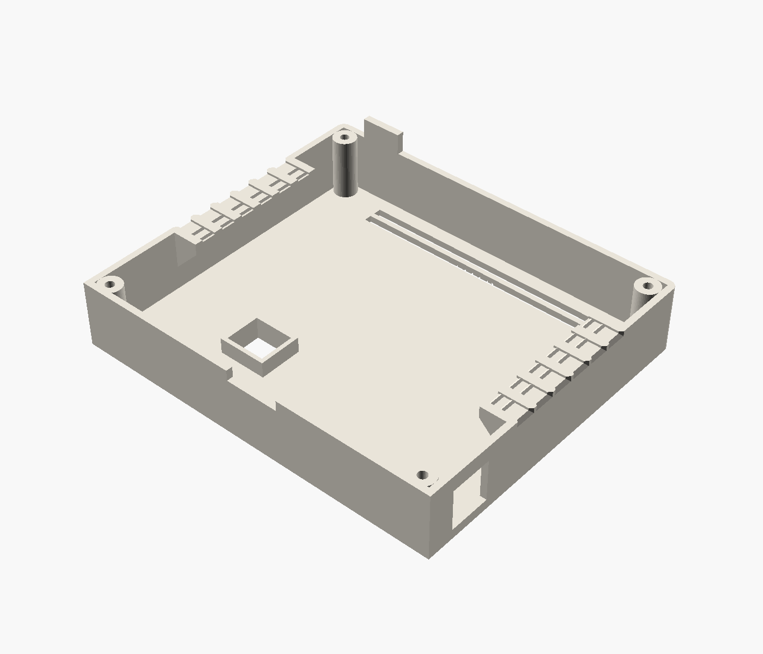
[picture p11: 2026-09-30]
hw/enclosure/enc-cover.png

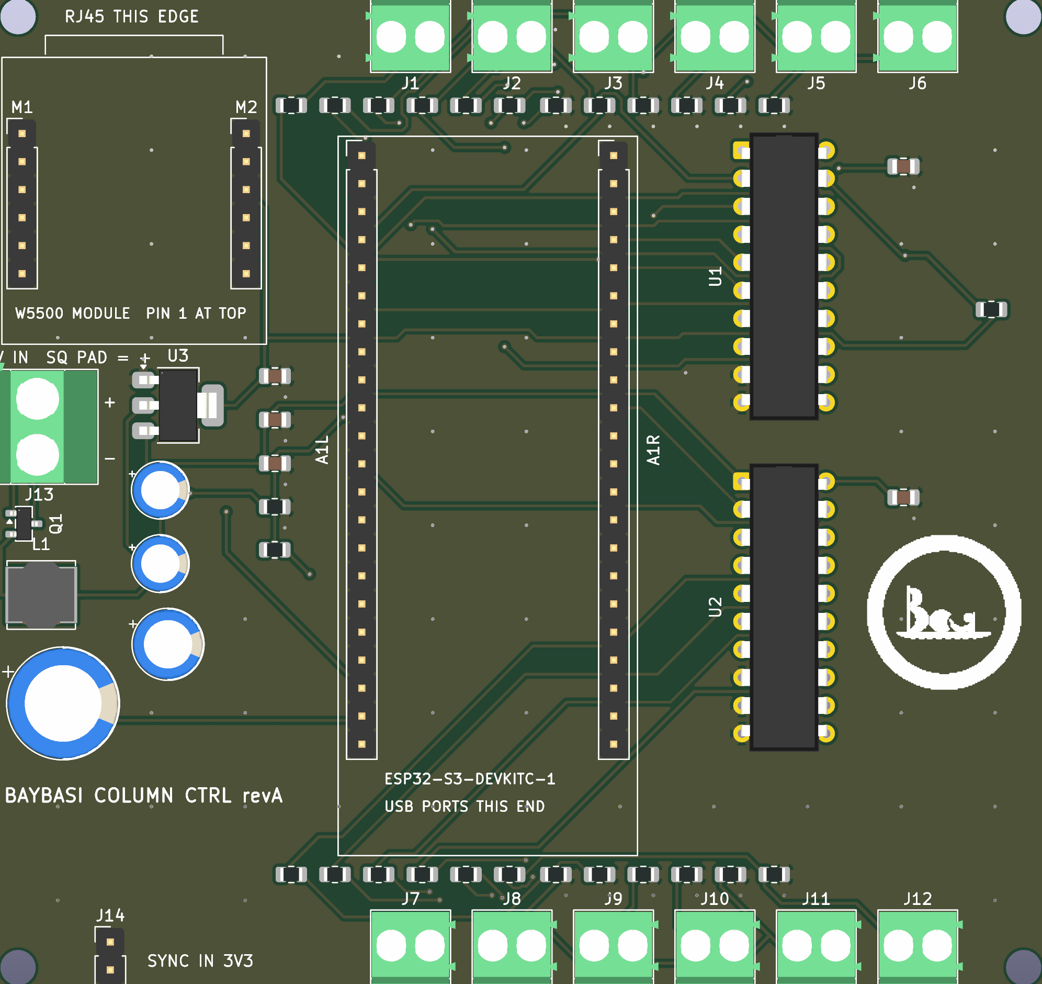
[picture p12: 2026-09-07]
hw/board3d.png

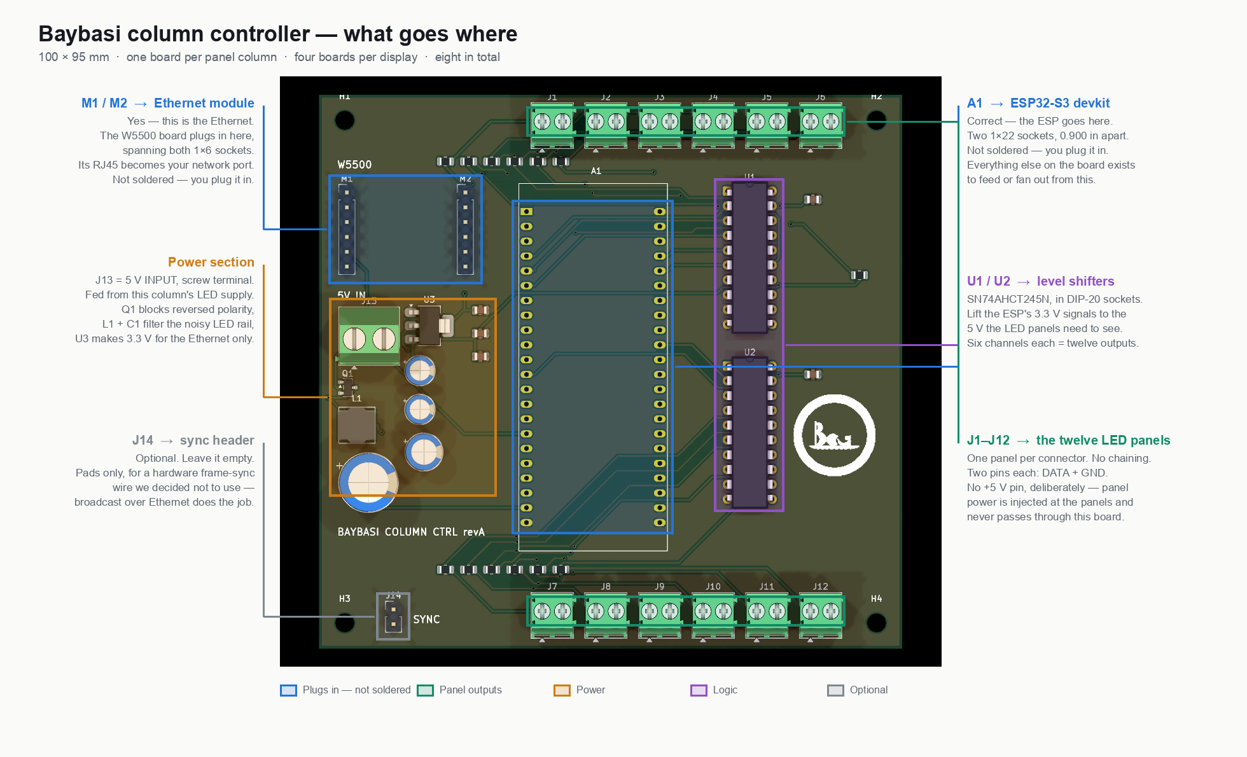
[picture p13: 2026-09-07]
hw/board-annotated.png

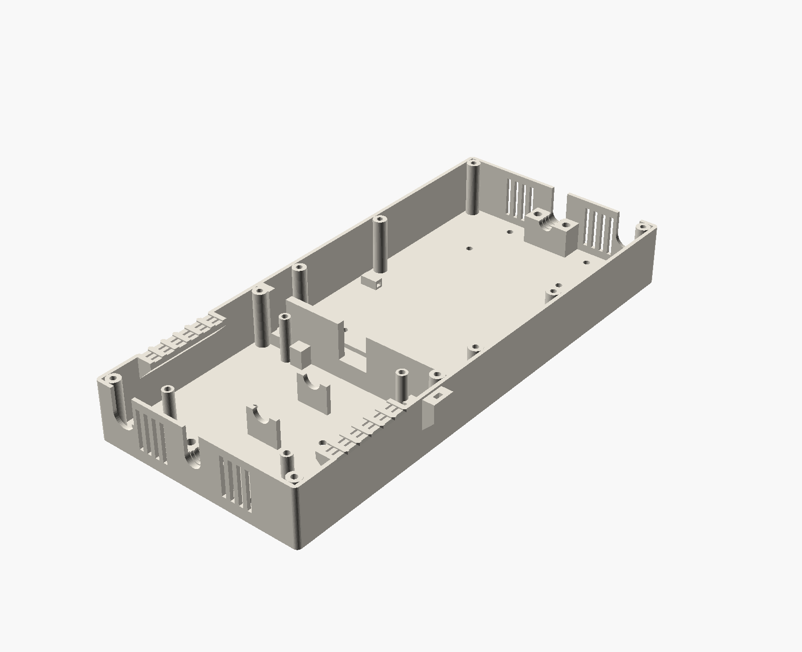
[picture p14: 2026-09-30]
hw/enclosure/enc-tub.png

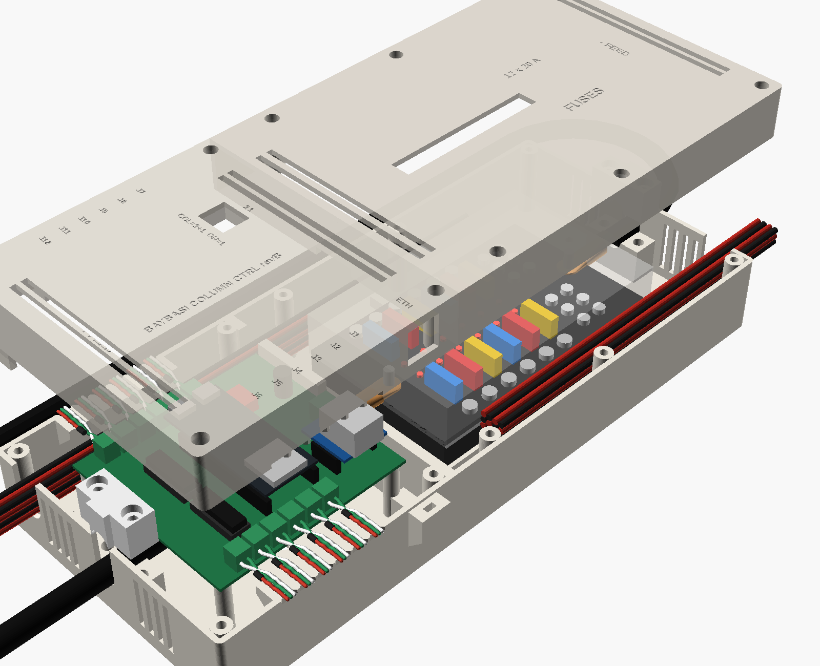
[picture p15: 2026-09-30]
hw/enclosure/enc-exploded.png

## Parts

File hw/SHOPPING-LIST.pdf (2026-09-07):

# Baybasi Pixel Wall — Shopping List

Two displays · 8 controllers in service, 10 built · 96 panels · 24,576 LEDs

ORDER EVERYTHING AT ONCE
The last unknown is resolved. The W5500 header row spacing is 20.32 mm, from the WIZ820io User Manual V1.0 section 5 (symbol B, "20.32 (2.54 x 8)"). WIZnet specify the WIZ850io as a fully pin-compatible replacement for the WIZ820io, and both are 23 × 25 mm with two 1×6 headers on 2.54 mm pitch.

Nothing needs measuring first. Parts and PCBs can go in the same day.

### Controller boards — per board × 10

QTY | PART | NOTES
10 | ESP32-S3-
DevKitC-1 (N8R8
or N16R8)

Official Espressif board. Buy all ten from one listing in one order — clone 30-pin boards vary mechanically and we depend on 0.900″ rows.

10 W5500 module, 23
× 25 mm
USR-ES1 / "W5500
Lite"

Pin-to-pin compatible with the WIZ850io and the same ~23 × 25 mm board, so the 20.32 mm row spacing carries over. Identify it by the spec table, not the title: board ~23 × 25 mm, supply 3.3 V only, ≥200 mA, no onboard regulator. Ignore "3.3V/5V" in listing titles — that refers to 5 Vtolerant I/O and appears on both the right and wrong boards. The wrong one is the larger "Standard Blue" board with an AMS1117 and a single 2×5 dual-row header. Roughly $6–12 each against $19.68 for the WIZnet part — same W5500 silicon. Buy 12 and test them. Not the WIZ820io (that is a W5200, different chip, no driver support).
2 packs ACEIRMC 5-pack
Amazon
B0DTTLGJCS

$25.99 for five = $5.20 each. Listing states "PCB size: 23 * 25 mm", "USR-ES1", "3.3V external power supply, current should be more than 200mA" — three independent confirmations of the Lite footprint, and the photo shows the small green HanRun boards. Ships from Amazon, free 30-day refund/replacement, Amazon's Choice, 4.3★. A 3-pack option is $17.99 ($6.00 each). Two packs = 10 units for $51.98; three packs = 15 for $77.97 if you want generous spares.
alt HiLetgo single
B08KXM8TKJ

$9.99 each, also verified correct (25.7 × 22.8 mm, 3.3 V, ≥200 mA). Useful for buying one immediately; nearly twice the unit price in bulk.

— Avoid: Amazon
B0CDWX9VQ5

HiLetgo 2-pack at $12.99. Photo shows the elongated blue board with a single-row header — wrong form factor.
20 TI SN74AHCT245N,
DIP-20

AHCT, not AHC or HC — TTL input thresholds are the whole point

— Everything else on
the board

Fitted by JLCPCB with the boards: DIP sockets, both socket rows, regulator, FET, inductor, all resistors and capacitors, all terminal blocks, sync header. Nothing to buy, nothing to solder. See Printed circuit boards.
40 M3 × 10 mm
standoff + screw

4 per board

### Per system × 2

QTY | PART | NOTES
2 Raspberry Pi 3 or newer | The Kano Pi serves one. Source a second.
2 microSD card, 16 GB+ | Raspberry Pi OS Lite. Do not reuse the Kano card.
2 5 V / 3 A USB supply for the Pi | Not the Kano battery pack, and not off an LED rail
2 8-port unmanaged switch | 5 ports used. 100 Mbit is enough; gigabit costs the same.
10 Cat5e UTP patch lead | 4 + 1 per system. Unshielded — shielded bonds the column grounds together.

### Panel wiring — 96 panels

QTY PART | NOTES
104 | 3-pin JST-SM
extension lead, 22
AWG
Amazon

One per panel plus spares; 26 packs. 2 m / 6.56 ft ($8.99/pack) if the controller mounts midcolumn, 3 m / 9.84 ft ($9.99/pack) if it mounts at the bottom. Male one end, female the other, so one end mates with the panel whichever gender it is; cut the other end off and land white (GND)

QTY PART | NOTES
B0F6SZF25C, 4-
pack, pick the length
variant

and green (DATA) in the screw terminal. Cut the red +5 V conductor at both ends and heat-shrink the stubs — panel power never goes through the controller.

1 roll Heat-shrink tubing, 2–3 mm, and cable
labels

For the 208 cut red stubs, and to number both ends of every lead before assembly.

200 Small zip ties | One per JST-SM plug at the panel; the latch alone is not enough once the display moves.
96 1000 µF 10 V
electrolytic

Across 5 V at each panel's power entry

— 14–16 AWG for
power injection

Per your existing harness

— Inline fuses, one per
injection run

A shorted strand behind a 60 A supply is a fire

### Printed circuit boards

QTY PART | NOTES
10 | PCB, 100 ×

### 95 mm, 2-

layer

Upload | baybasi-ctrl-<date>-gerbers.zip | plus | jlcpcb-bom.csv | and | jlcpcb-cpl.csv . HASL
lead-free, 1.6 mm, 1 oz, tented vias. Assembly: yes — Economic, top side, "Confirm Parts Placement" on. About $60–90 for five assembled boards plus $20–25 shipping; order five, prove one, then the rest.

### Where to order

Split the order by risk, not by price. Two parts decide whether the boards work; the rest is commodity.

VENDOR | BUY HERE | WHY
DigiKey
one order

ESP32-S3-DevKitC-1 ×10 ·
SN74AHCT245N ×20

Devkits ship same day and are genuine Espressif. Authorised distributor, so the Espressif boards are genuine and mechanically consistent — which is the entire reason we chose the S3. US delivery in about two
| days.
Mouser or
Arrow
Same list, if DigiKey is short | Arrow was marginally cheaper on the WIZ850io (~$17.14 in tens) but
held only ~93 units. Fine as a backup; not worth a second shipment.
Amazon | M3 standoffs · hookup and twisted
wire · Cat5e leads · 8-port switches · Pi
supplies · microSD

Commodity mechanical parts where brand does not matter and nextday delivery does. Do not buy the devkits or the W5500 here — listings claiming "official" frequently are not.
PiShop /
Adafruit /
CanaKit
The second Raspberry Pi | Any Pi 3 or newer. Adafruit and PiShop are reliable on genuine stock.
LCSC | Only if cost beats schedule | WIZ850io is | C134462 | and the passives are far cheaper in bulk, but
shipping from China runs one to two weeks. Given the W5500 measurement gates the PCB order, that delay costs more than it saves.
JLCPCB | The PCBs, assembled | Under 100 × 100 mm is the cheap tier. PCBWay is equivalent; Aisler if
you want EU.

TWO THINGS WORTH KNOWING BEFORE YOU SPEND
Do not pay the WIZnet premium. DigiKey want $24.52 for one WIZ850io and $19.68 each in tens — about $197 for the Ethernet alone. The W5500 chip inside costs a few dollars; the rest is distributor margin on a low-volume first-party module. The USR-ES1 clone is the same silicon on the same 23 × 25 mm board, specified pin-to-pin compatible, at roughly a third of the price. The USR-ES1 / W5500 Lite is specified as pin-to-pin compatible with the WIZ850io on an identical 23 × 25 mm board, so it inherits the 20.32 mm spacing. It is the same W5500 silicon at roughly a third of the price.

Do not substitute the WIZ820io. It is mechanically identical and sold alongside the WIZ850io, but it carries a W5200, not a W5500. Different register map, no driver in the ESP32 Ethernet stack we use, and it needs a hardware reset pulse our board does not generate. It is also end-of-life.

Rough total, excluding LED power supplies: about $340 in board parts with clone Ethernet modules (about $470 if you insist on WIZnet), plus about $135 for the second Pi, two switches and cabling, plus about $30 of PCBs. Call it $510. Add US tariffs — DigiKey warn they may apply and are only shown at checkout.

THREE THINGS THAT WILL BITE IF YOU GET THEM WRONG
1. AHCT, not HC. An | SN74HC245 | looks identical and will not reliably read 3.3 V as a logic high from a 5 V rail.
2. Terminal block pitch. 3.5 mm and 3.81 mm are sold side by side and look the same in a photograph. The board is drilled for 3.5.
3. The W5500 module is 3.3 V only. It has no regulator. 5 V on its V pins destroys it instantly. The larger blue W5500 boards do take 5 V — do not mix them up.

Power supplies for the LEDs are excluded — you said those are handled separately. For reference the design target is roughly 295 A per display at 5 V, sized at 40% of the 737 A theoretical maximum.

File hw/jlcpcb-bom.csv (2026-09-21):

Comment | Designator | Footprint | LCSC Part # | Note
Female header 1x22 2.54mm | A1L,A1R | 1x22 socket | C7499337 | ZX-PM2.54-1-22PY 8.5mm - ESP32-S3-DevKitC-1 plugs in
Female header 1x06 2.54mm | M1,M2 | 1x06 socket | C7499326 | ZX-PM2.54-1-6PY 8.5mm - WIZ850io / USR-ES1 plugs in
IC socket DIP-20 7.62mm | U1,U2 | DIP-20 | C2328 | verified 8543 stock $0.0567 - SN74AHCT245N inserted by hand
AMS1117-3.3 | U3 | SOT-223 | C6186 | basic part - matched 2026-09-07
AO3401A | Q1 | SOT-23 | C15127 | basic part; 1=G 2=S 3=D
10uH 2A | L1 | SRN6045 | C2046332 | Bourns SRN6045TA-100M
470uF 16V | C1 | Radial D10 P3.5 | C165573 | KMG 16V470 8x11.5 THT P3.5
100uF 16V | C2 | Radial D6.3 P2.5 | C43805 | KS107M016E07 6.3x7 THT P2.5
10uF 100V | C3 | Radial D5 P2.5 | C2029 | KM106M100E11 6.3x11 THT P2.5 (6.3 mm can on the D5 footprint - fits)
22uF 50V | C4 | Radial D5 P2.5 | C45098 | KS226M050E07 6.3x7 THT P2.5 (6.3 mm can on the D5 footprint - fits)
100nF 50V X7R | C5,C6,C7,C8,C9 | 0805 | C49678 | basic part
330R 1% | R1,R2,R3,R4,R5,R6,R7,R8,R9,R10,R11,R12 | 0805 | C17630 | basic part - series termination
10k 1% | R16,R17,R18,R19,R20,R21,R22,R23,R24,R25,R26,R27 | 0805 | C17414 | basic part - output pull-downs
10k 1% | R13 | 0805 | C17414 | basic part - Q1 gate pull-down (was 100k; C17407 short at order time)
10k 1% | R14,R15 | 0805 | C17414 | basic part - W5500 reset pull-up / 245 output-enable pull-up (3V3E)
Terminal block 2P 3.50mm | J1,J2,J3,J4,J5,J6,J7,J8,J9,J10,J11,J12 | TB 1x02 P3.50 | C474892 | KF350-3.5-2P - wire entry faces the board edge (silk triangle side)
Terminal block 2P 5.08mm | J13 | TB 1x02 P5.08 | C474952 | KF128-5.08-2P-AA - wire entry faces the left edge
DIP switch 4P 2.54mm | SW1 | SW_DIP_SPSTx04 7.62mm | C99418 | DSWB04LHGET - column select; poles 1-2 = column 0-3 binary | 3-4 spare
Pin header 1x02 2.54mm | J14 | 1x02 header |  | NOT POPULATED - optional sync input; fit by hand if ever needed

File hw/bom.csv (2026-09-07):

Reference | Value | Footprint | QUANTITY
A1 | ESP32-S3-DevKitC-1 | PCM_Espressif:ESP32-S3-DevKitC | 1
C1 | 470uF 16V | Capacitor_THT:CP_Radial_D10.0mm_P3.50mm | 1
C2 | 100uF | Capacitor_THT:CP_Radial_D6.3mm_P2.50mm | 1
C3 | 10uF | Capacitor_THT:CP_Radial_D5.0mm_P2.50mm | 1
C4 | 22uF | Capacitor_THT:CP_Radial_D5.0mm_P2.50mm | 1
C5-C9 | 100nF | Capacitor_SMD:C_0805_2012Metric | 5
J1 | PANEL 1 | TerminalBlock_Phoenix:TerminalBlock_Phoenix_PT-1,5-2-3.5-H_1x02_P3.50mm_Horizontal | 1
J2 | PANEL 2 | TerminalBlock_Phoenix:TerminalBlock_Phoenix_PT-1,5-2-3.5-H_1x02_P3.50mm_Horizontal | 1
J3 | PANEL 3 | TerminalBlock_Phoenix:TerminalBlock_Phoenix_PT-1,5-2-3.5-H_1x02_P3.50mm_Horizontal | 1
J4 | PANEL 4 | TerminalBlock_Phoenix:TerminalBlock_Phoenix_PT-1,5-2-3.5-H_1x02_P3.50mm_Horizontal | 1
J5 | PANEL 5 | TerminalBlock_Phoenix:TerminalBlock_Phoenix_PT-1,5-2-3.5-H_1x02_P3.50mm_Horizontal | 1
J6 | PANEL 6 | TerminalBlock_Phoenix:TerminalBlock_Phoenix_PT-1,5-2-3.5-H_1x02_P3.50mm_Horizontal | 1
J7 | PANEL 7 | TerminalBlock_Phoenix:TerminalBlock_Phoenix_PT-1,5-2-3.5-H_1x02_P3.50mm_Horizontal | 1
J8 | PANEL 8 | TerminalBlock_Phoenix:TerminalBlock_Phoenix_PT-1,5-2-3.5-H_1x02_P3.50mm_Horizontal | 1
J9 | PANEL 9 | TerminalBlock_Phoenix:TerminalBlock_Phoenix_PT-1,5-2-3.5-H_1x02_P3.50mm_Horizontal | 1
J10 | PANEL 10 | TerminalBlock_Phoenix:TerminalBlock_Phoenix_PT-1,5-2-3.5-H_1x02_P3.50mm_Horizontal | 1
J11 | PANEL 11 | TerminalBlock_Phoenix:TerminalBlock_Phoenix_PT-1,5-2-3.5-H_1x02_P3.50mm_Horizontal | 1
J12 | PANEL 12 | TerminalBlock_Phoenix:TerminalBlock_Phoenix_PT-1,5-2-3.5-H_1x02_P3.50mm_Horizontal | 1
J13 | 5V IN | TerminalBlock_Phoenix:TerminalBlock_Phoenix_MKDS-1,5-2-5.08_1x02_P5.08mm_Horizontal | 1
J14 | SYNC IN (opt) | Connector_PinHeader_2.54mm:PinHeader_1x02_P2.54mm_Vertical | 1
L1 | 10uH 2A | Inductor_SMD:L_Bourns_SRN6045TA | 1
M1 | WIZ850io J1 | Connector_PinHeader_2.54mm:PinHeader_1x06_P2.54mm_Vertical | 1
M2 | WIZ850io J2 | Connector_PinHeader_2.54mm:PinHeader_1x06_P2.54mm_Vertical | 1
Q1 | AO3401A | Package_TO_SOT_SMD:SOT-23 | 1
R1-R12 | 330 | Resistor_SMD:R_0805_2012Metric | 12
R13 | 100k | Resistor_SMD:R_0805_2012Metric | 1
R14,R15 | 10k | Resistor_SMD:R_0805_2012Metric | 2
U1,U2 | SN74AHCT245N | Package_DIP:DIP-20_W7.62mm | 2
U3 | AMS1117-3.3 | Package_TO_SOT_SMD:SOT-223-3_TabPin2 | 1

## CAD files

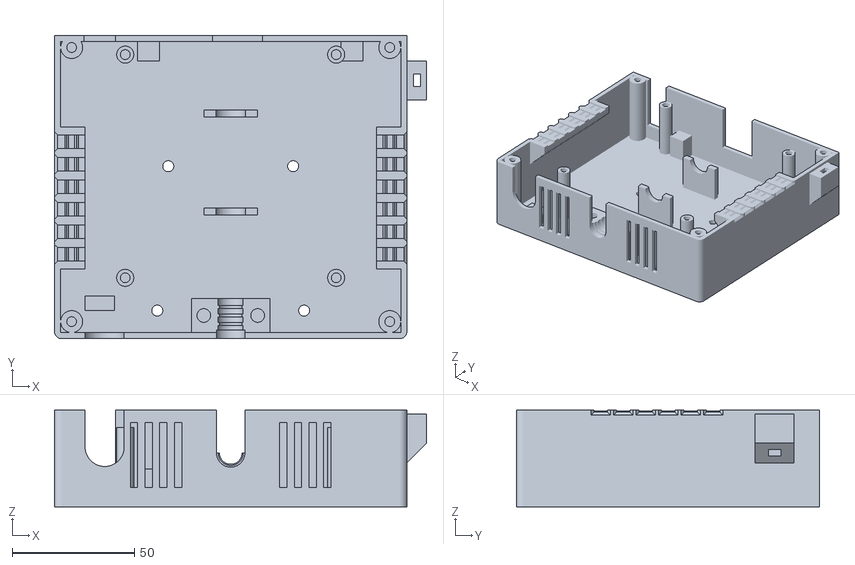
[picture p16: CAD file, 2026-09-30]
hw/enclosure/tub-lower.stl
152.0 x 124.0 x 39.5

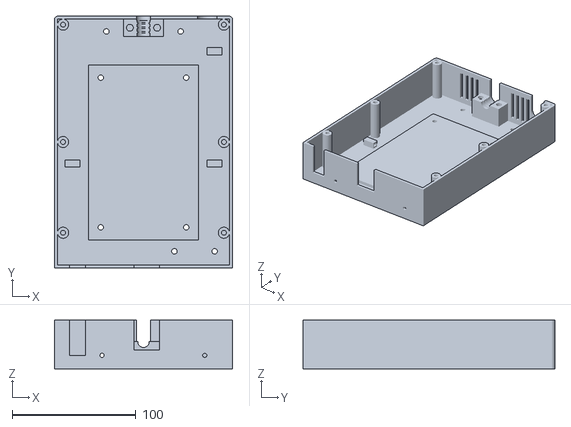
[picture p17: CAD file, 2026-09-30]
hw/enclosure/tub-upper.stl
144.0 x 203.7 x 39.5

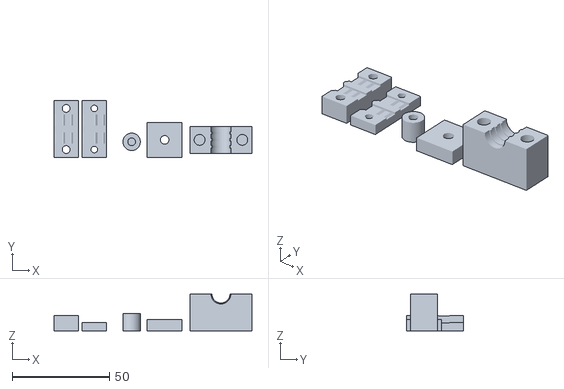
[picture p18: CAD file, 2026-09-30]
hw/enclosure/coupon.stl
102.0 x 29.2 x 19.0

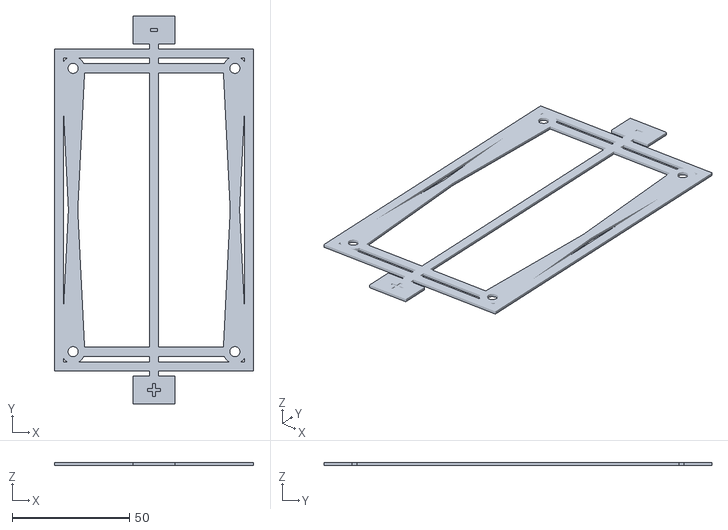
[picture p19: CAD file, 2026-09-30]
hw/enclosure/template.stl
85.1 x 165.7 x 1.20

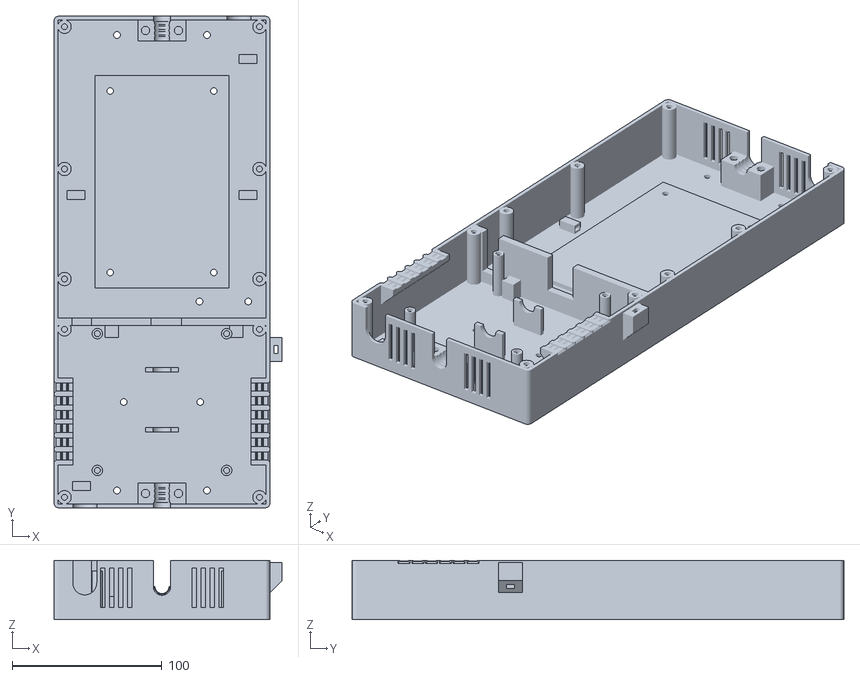
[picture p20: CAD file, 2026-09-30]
hw/enclosure/tub.stl
152.0 x 327.7 x 39.5

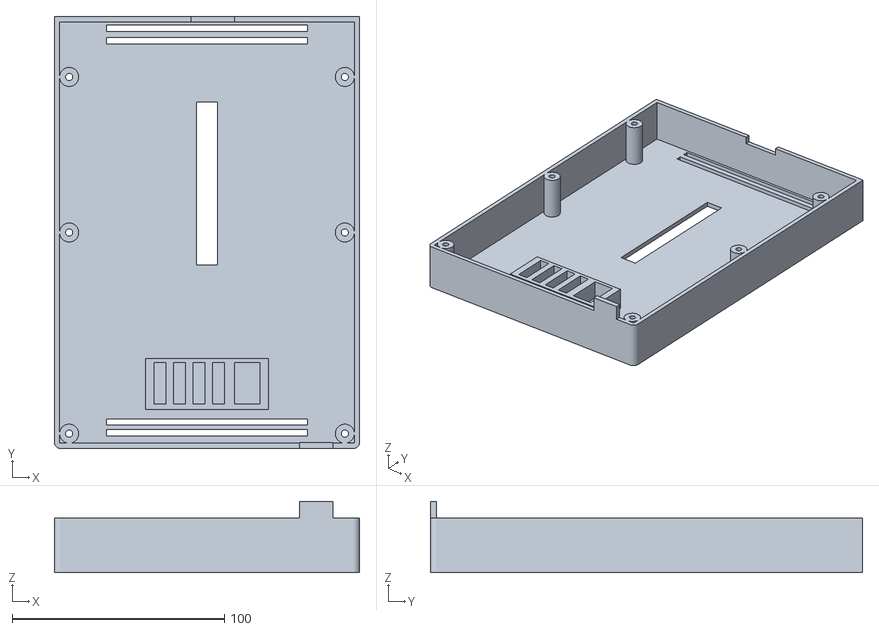
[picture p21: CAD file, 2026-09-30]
hw/enclosure/lid.stl
144.0 x 203.7 x 33.7

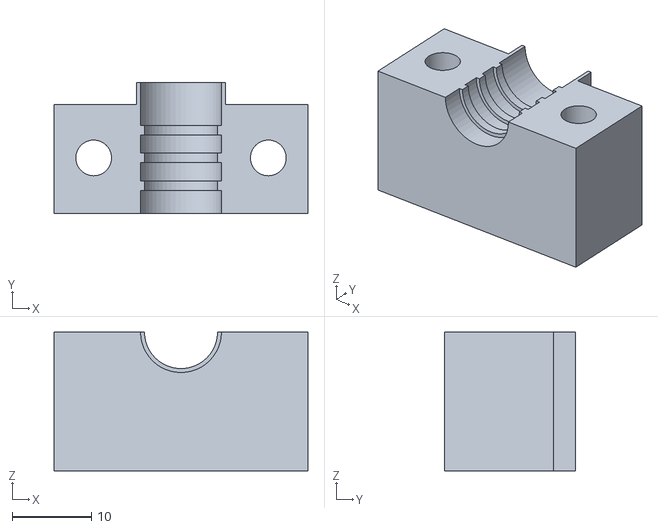
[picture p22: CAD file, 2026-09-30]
hw/enclosure/clamp.stl
32.0 x 16.5 x 17.5

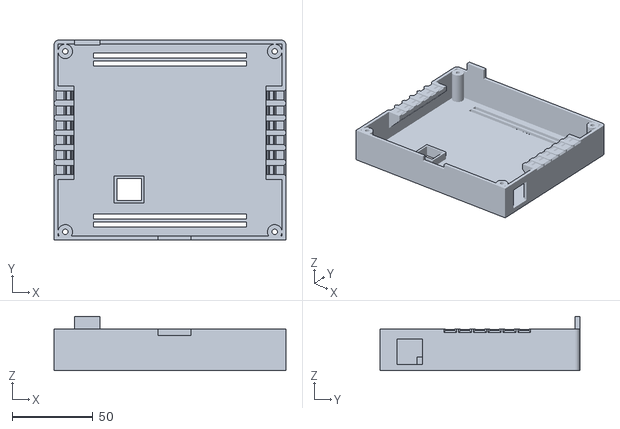
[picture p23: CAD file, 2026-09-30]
hw/enclosure/cover.stl
144.0 x 124.0 x 33.7

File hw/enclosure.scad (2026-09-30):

// Baybasi pixel wall — per-column unit enclosure, rev B
//
// One box per column. It holds the column's 12-way fused distribution block
// and its controller board, block above board, on the inside of a hinged door.
// Four make a display; two ride on each 16 in door (sheet E-2).
//
// WHY THE BLOCK STANDS ON END.  The block is a DAIER FB-1714 (sold as DaierTek
// B0CGT91KTR). Its two feed studs sit on the centreline at OPPOSITE ENDS, and
// its cover lets a cable reach each stud only through a notch in that end
// wall, so each 6 AWG lug points straight out along the block's long axis.
// Laid across the box the way E-1 sketches it, both feeds leave through the
// side walls: 137.7 of block, plus 16 of lug, 6 of heat-shrink and 14 of
// clamp at each end, and two walls, is 215 mm of box before either cable has
// turned, and two of those do not fit on a 406 mm door. Stood on end, the - feed comes straight in through the
// roof, the + feed straight in through the floor, and the box is 144 wide.
//
// WHY THE BOARD STANDS ON TALL POSTS.  The + feed has to reach the bottom of
// the block from below, and the board is below the block. So the + cable runs
// up the middle of the box UNDER the board, and the board stands on posts tall
// enough to clear it. That, not the block, sets the depth of the box:
// blk_lug_z + half the cable + clearance to the board's solder tails. Measure
// blk_lug_z with a lug on the stud before printing anything big.
//
// Carried forward from rev A, unchanged in intent:
//   - Every external connection is held by the enclosure, not by the PCB.
//     Pulling a lead loads the box, never the board.
//   - The controller half splits at the data leads' centreline, so screwing
//     the cover down clamps all twelve at once. Nothing snaps, nothing is glued.
//   - M3 heat-set inserts, and a coupon printed before the big parts.
// New in rev B:
//   - The feeds are clamped to the tub, not to a cover, so either cover can
//     come off with the door swinging and nothing that carries 60 A moves.
//   - The fuse lid and the controller cover are separate. Changing a fuse
//     never unclamps a data lead, and reflashing never exposes the 60 A side.
//   - Half the column is fed upward and half downward (E-3). The right half of
//     the box serves rows 1-6: its six drops leave through the roof and its six
//     data leads through the right wall. The left half serves rows 7-12: drops
//     down past the board and out through the floor, data through the left
//     wall. Power leaves the ends and data the sides, so the looms part at the
//     box (E-3 note 3).
//   - The data leads are wired straight into J1-J12, as the shopping list
//     plans, and clamped where they cross the wall: ribbed jaws in the tub and
//     the cover, staggered so the cover's screws press each lead into a wave.
//     Rev A's JST housings in the wall are gone. Whichever half sat there,
//     either its lock was out of reach or the leads' genders were wrong.
//   - The controller's 5 V shares fuse R07 (E-1), so there is no tap holder.
//
// PRINT THE COUPON AND THE TEMPLATE FIRST.  The coupon checks the lead clamp,
// both insert sizes, the block-bolt pocket and the feed clamp against real
// parts; the template is a 1:1 outline of the block to lay the real block on.
// Every block dimension below comes from the maker's drawings, not a part in
// hand. The coupon and template cost an hour; the tub costs a day.
//
//   openscad -D 'part="coupon"'    -o coupon.stl    enclosure.scad
//   openscad -D 'part="template"'  -o template.stl  enclosure.scad
//   openscad -D 'part="clamp"'     -o clamp.stl     enclosure.scad   (print 2)
//   openscad -D 'part="tub_upper"' -o tub-upper.stl enclosure.scad   (fits a 220 mm bed)
//   openscad -D 'part="tub_lower"' -o tub-lower.stl enclosure.scad
//   openscad -D 'part="lid"'       -o lid.stl       enclosure.scad
//   openscad -D 'part="cover"'     -o cover.stl     enclosure.scad
//   openscad -D 'part="tub"'       -o tub.stl       enclosure.scad   (one piece, needs 330 mm)
//
// export_enclosure.sh writes all of them, and the renders, to enclosure/.
// Every part is exported in its print orientation. ENCLOSURE.md has the
// print settings, the list of things to measure, and the assembly order.

part = "tub";   // [tub, tub_upper, tub_lower, lid, cover, clamp, coupon, template, kit, assembled, open, exploded, door, illus_closed, illus_open, illus_lead, illus_mount]
step = 3;       // [1, 2, 3] illus_lead: lead laid in, cover coming down, clamped
view = "front"; // [front, back, bolt, screw] illus_mount

/* [MEASURE: fuse block, DAIER FB-1714] */
// DAIER publish two drawings of this block that disagree by up to 2 mm. The
// defaults take the newer "product size" sheet, and the larger height.
blk_l        = 137.7;   // length of the base, - end to + end (older sheet: 138.25)
blk_w        = 85.1;    // width of the base (older sheet: 85.0)
blk_w_cover  = 88.0;    // width over the cover's push latches
blk_h        = 36.5;    // mounting face to the top of the latched cover (newer sheet: 35.7)
blk_hole_px  = 121.0;   // mounting-hole pitch along the length (older sheet: 123.25)
blk_hole_py  = 69.1;    // mounting-hole pitch across (older sheet: 70.0)
blk_stud_in  = 8.35;    // stud centre in from each end; both sheets put it level with the holes
blk_lug_z    = 16.0;    // axis of a 6 AWG lug's barrel on a stud, above the mounting face.
                        // THIS SETS THE BOX DEPTH. Guessed from the end view: ~14 to the stud
                        // seat, ~2 more to the barrel axis. Fit a lug and measure it.
blk_led_from = 45;      // blown-fuse LED column, measured from the - end
blk_led_to   = 122;

/* [MEASURE: cables and loose parts] */
feed_od      = 11.0;    // 6 AWG welding cable over the jacket
feed_squeeze = 0.8;     // the clamp's bore is this much under feed_od
lug_reach    = 16.0;    // 6 AWG lug (ring + barrel) past the block's end face, with the ring on the stud
shrink_len   = 6.0;     // heat-shrink over the barrel, past the barrel
drop_bundle  = 15;      // height left in each drop slot for 12 x 14 AWG silicone
lead_w       = 5.2;     // panel data lead, flat 3 x 22 AWG: width. Calipers on a real lead.
lead_t       = 1.7;     // and thickness
lead_bite    = 0.6;     // how far each jaw rib presses into the lead. Coupon check 1.

/* [MEASURE: controller] */
rj45_h       = 13.5;    // RJ45 above the WIZ850io/USR-ES1 module's PCB (rev A)
sock_h       = 8.5;     // A1L/A1R and M1/M2 sockets, ZX-PM2.54 8.5 mm (BOM)
hdr_spacer   = 2.5;     // plastic body of the male headers under the devkit and the module
pcb_pins     = 3.0;     // THT tails below the board. The + feed passes under them.
term_h       = 9.2;     // J1..J12 above the board (KiCad model of the Phoenix part)
dk_usb_by    = 80.5;    // devkit USB receptacle faces, board y. Third-party devkit: measure.

/* [Board: from baybasi-ctrl.kicad_pcb, do not change] */
pcb_x      = 100;
pcb_y      = 95;
pcb_t      = 1.6;
pcb_holes  = [[4.4, 4.4], [95.6, 4.4], [4.4, 90.6], [95.6, 90.6]];
term_x     = [40.0, 49.2, 58.4, 67.6, 76.8, 86.0];  // J1..J6 (y 6.23) and J7..J12 (y 88.6)
j13        = [6.33, 41.58];     // J13 centre; its wires enter from x = 0
eth        = [14.93, 6.04];     // RJ45 centre x, and its face y
sw1_box    = [22.87, 66.59, 32.75, 79.03];
sw1_poles  = [69.0, 71.54, 74.08, 76.62];           // y of poles 1, 2, SP, SP
dk_rows    = [35.57, 60.97];    // A1L and A1R, 25.40 apart on rev B
dk_w       = 28;                // third-party devkit, ~28 wide (FABRICATION.md)

/* [Box] */
wall       = 2.5;
floor_t    = 3;
top_t      = 2.5;
blk_pad    = 3;         // raised seat under the block: 6 mm of floor over the bolt heads
side_ch    = 24;        // least wire channel beside the block
gap_side   = 22;        // board edge to side wall: lead jaws, and the leads' run to J1-J12
div_t      = 5;         // divider between the fuse half and the controller half
clamp_len  = 14;        // feed clamp, along the cable
feed_gap   = 2;         // + feed to the tips of the board's THT tails
lead_above = 5.4;       // data leads' centreline, which is the tub/cover joint, above the board
head_room  = 2.5;
jaw_len    = 10;        // lead jaws, inward from the side wall
jaw_h      = 3.5;       // jaw bar beyond the groove
lead_pitch = 9.2;        // lead to lead: the J1-J12 terminal pitch, so each lead runs straight
eth_w      = 16;        // Ethernet opening, wide enough to reach the plug latch
eth_hi     = 16;
fillet     = 3;

/* [Fasteners] */
m3_free    = 3.4;
m3_insert  = 4.0;       // M3 x 5.7 heat-set, brass
m3_cbore   = 6.5;
m4_free    = 4.5;
m4_insert  = 5.6;       // M4 x 8 heat-set, brass (feed clamps)
m4_head_af = 7.4;       // M4 hex bolt head across flats, plus clearance (block bolts)
m4_head_t  = 3.0;
door_hole  = 4.5;       // #8 or M4 pan head into the door
boss_d     = 9;
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

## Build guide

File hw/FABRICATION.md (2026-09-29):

# Fabrication

## Status: QA'd, routed, DRC-clean, Gerbers build

`export_fab.sh` produces the upload zip. `make_cpl.py` produces the JLCPCB
placement file and refuses to run if the BOM and the board disagree.

The routing is machine-generated by Freerouting (`./route.sh`) and re-runnable:
`gen_pcb.py` rebuilds the board from scratch, `route.sh` re-routes it. Neither
step needs the GUI.

    python3 gen_sch.py && kicad-cli sch export netlist -o net.net baybasi-ctrl.kicad_sch
    python3 gen_pcb.py         # placement, keepouts, stitching vias, silkscreen
    ./route.sh                 # DSN out, Freerouting, SES back, pad ties, pour repair, DRC
    ./export_fab.sh            # runs DRC, exports, zips - fails if unrouted
    <KiCad python3> make_cpl.py   # jlcpcb-cpl.csv from the board, cross-checked against jlcpcb-bom.csv

## Design QA, 2026-09-07

A pin-by-pin review of the schematic, the footprints and the layout against the
part datasheets. Four defects found and fixed, three hardening changes made.

| # | Finding | Severity | Fix |
|---|---|---|---|
| 1 | **Q1 was backwards.** Source faced the input, drain faced the load. A P-FET's body diode runs drain→source, so a reversed supply would have conducted straight through the load — the protection did nothing. | would have shipped a dead feature | Drain to J13 (input), source to L1 (load), gate to GND via R13. Correct polarity: diode conducts until Vgs = −5 V turns the channel on. Reversed: diode blocked, Vgs ≥ 0, channel off. |
| 2 | **/OE pull-up went to +5 V.** GPIO8 is not 5 V tolerant; with the devkit unpowered, 10 kΩ from 5 V back-drives its protection diode. | slow damage / boot flakiness | R15 to the board's own 3V3E rail. 3.3 V clears the AHCT VIH of 2.0 V. 3V3E rather than the devkit 3V3 so the outputs stay disabled with no devkit fitted. |
| 3 | **J1–J6 faced the wrong way.** Both Phoenix footprints put the wire opening on the +y face; on the top edge that pointed into the board. | unusable connectors | J1–J6 rotated 180°. J13 rotated 270° so the PSU leads enter from the left edge instead of running across Q1/L1/C1. |
| 4 | **Devkit body was mis-sized.** The outline was drawn symmetric about the pins; Espressif's footprint has 9.2 mm beyond the last pin at the USB end and 0.85 mm at the antenna end. The USB shells would have hung over the bottom resistor row. | mechanical | Socket moved up 3 mm; body box taken from the Espressif courtyard; silkscreen says which end is USB. |
| 5 | Twelve outputs float while /OE is high (boot, reset, no devkit). A floating WS2812B DIN reads noise as pixels. | cosmetic at power-up | R16–R27: 10 kΩ to GND on every OUT. |
| 6 | W5500 RSTn was pull-up only; firmware could not hard-reset the module. | robustness | RSTn also on GPIO15 (devkit pad 8). `ETH.begin(..., rst=15, ...)`. The pull-up stays. |
| 7 | Surface-mount GND pads relied on the pour reaching them; routing boxed one in. | routing | `route.sh` now ties every SMD GND pad to its own via before routing and repairs pour islands after the fill. |

Verified correct, no change: SPI on the S3's IOMUX pins (10–13) with INT on 14;
all twelve LED pins clear of strapping, USB, PSRAM and console pins; U1/U2
pinout (DIR high, A→B, unused A6/A7 grounded, OE on pin 19); SOT-223 tab = pin
2 = VOUT; W5500 module orientation (J1 left, J2 right, pin 1 at the RJ45 end,
RJ45 toward the top edge — WIZ820io UM figure, top view); female-socket rows
22.86 mm and 20.32 mm; AMS1117 dissipation 0.34 W; LC filter damped (Q ≈ 0.7);
1 A power traces at 1 mm.

Known, accepted: with the LED PSU off and USB plugged into the devkit, the
devkit's 5 V pin back-feeds this board and, through Q1's channel, the 5 V IN
terminal — so USB would try to power the panel column. Flash with the PSU on,
or with the panel supply disconnected. Confirm the devkit's own VBUS diode is
present (Espressif schematic, D1) before relying on the PSU-on case.

## Pin map (ESP32-S3-DevKitC-1)

| Function | GPIO | Devkit pad | Notes |
|---|---|---|---|
| W5500 CS / MOSI / SCK / MISO | 10 / 11 / 12 / 13 | 16 / 17 / 18 / 19 | FSPI IOMUX pins |
| W5500 INT | 14 | 20 | |
| W5500 RST | 15 | 8 | active low; R14 10 k to 3V3E |
| LED outputs 1–3 | 4, 5, 6 | 4, 5, 6 | left row |
| LED outputs 4–12 | 1, 2, 21, 38, 39, 40, 41, 42, 47 | right row | D4=GPIO1 … D12=GPIO47 |
| /OE for U1+U2 | 8 | 12 | drive LOW to enable outputs; R15 10 k to 3V3E |
| Sync in (optional) | 7 | 7 | J14, 3.3 V logic only |
| Status LED | 48 | — | on-board RGB |
| 5 V in / GND | — | 21 / 22, 23, 24, 44 | |

Left socket A1L = devkit pads 1–22 top to bottom; right socket A1R pin *i* =
devkit pad 45 − *i*.

## JLCPCB parts as matched, 2026-09-07

| Ref | LCSC | Part | Note |
|---|---|---|---|
| A1L, A1R | C7499337 | ZX-PM2.54-1-22PY female 1×22, 8.5 mm | extended |
| M1, M2 | C7499326 | ZX-PM2.54-1-6PY female 1×6, 8.5 mm | extended |
| U1, U2 | C2328 | DIP-20 socket, 7.62 mm | extended; SN74AHCT245N by hand |
| U3 | C6186 | AMS1117-3.3 SOT-223 | basic |
| Q1 | C15127 | AO3401A SOT-23 | basic |
| L1 | C2046332 | Bourns SRN6045TA-100M | extended |
| C1 | C165573 | KMG 470 µF 16 V, 8×11.5, P3.5 | THT |
| C2 | C43805 | 100 µF 16 V, 6.3×7, P2.5 | THT |
| C3 | C2029 | 10 µF 100 V, 6.3×11, P2.5 | THT; 6.3 mm can on the D5 footprint, fits |
| C4 | C45098 | 22 µF 50 V, 6.3×7, P2.5 | THT; same |
| C5–C9 | C49678 | 100 nF 50 V X7R 0805 | basic |
| R1–R12 | C17630 | 330 Ω 0805 | basic |
| R13–R27 | C17414 | 10 kΩ 0805 | basic; R13 was 100 k, see gen_sch.py |
| J1–J12 | C474892 | KF350-3.5-2P screw block | THT; openings must face the board edge |
| J13 | C474952 | KF128-5.08-2P-AA screw block | THT; opening faces the left edge |
| J14 | — | not placed | optional sync header |

The auto-matcher picked SMD electrolytics for C1–C3 the first time; every
electrolytic above is the leaded ("插件") part and was chosen by hand.

**CPL conventions (make_cpl.py).** JLCPCB centres each part on the CPL
coordinate and uses its own zero orientation, so KiCad's position export is
wrong for anything whose anchor is pin 1. `make_cpl.py` reports the centre of
the pad bounding box and adds: SOT-223 +180, SOT-23 +180, DIP +270, pin
sockets +270, everything else +0. Verified against JLCPCB's placement overlay
for the parts above. Terminal-block entry direction is inferred from their
overlay arrows; confirm it on the placement image JLCPCB sends before
production ("Confirm Parts Placement" is on, auto-confirm off).

## Assembly notes

- JLCPCB places all SMD parts and the through-hole sockets, terminal blocks,
  inductor and electrolytics. You insert: the devkit, the W5500 module, and
  the two SN74AHCT245N into their DIP sockets.
- **DIP notch up** (toward the top edge) on U1 and U2 — pin 1 is top-left.
- **Devkit: USB ports toward the bottom edge**, 3V3 pin at the top-left of A1L.
- **W5500 module: RJ45 toward the top edge**, pin 1 (GND) at the top of each row.
- **J13:** square pad = +5 V. **J1–J12:** square pad = DATA, round = GND.
- J1–J6 wires leave over the top edge, J7–J12 over the bottom edge; the USB
  plug passes above J7–J9 with ~2.5 mm to spare (sockets 8.5 mm + header
  spacer 2.5 mm + devkit 1.6 mm).
- **Mount the board mid-column**, between panels 6 and 7. That keeps the longest
  data run near 4 ft instead of 8-10 ft, and puts the board's ground tap in the
  middle of the column's ground bus rather than at one end.
- Panel data leads are pre-made 3-pin JST-SM extension leads, 22 AWG, 2 m.
  White (GND) and green (DATA) land in J1-J12; the red +5 V conductor is cut and
  capped at **both** ends, because panel power never routes through this board.
- If one output is glitchy after everything else checks out, drop that channel's
  series resistor from 330 to 150 ohms. 330 over-damps a 2-3 m lead.

## Where to have them made

Board is 100 × 95 mm, 2-layer — 14.7 sq in. That size matters: shops that price
per square inch get expensive fast, while shops with a flat "under 100 × 100 mm"
tier are at their cheapest.

| Option | Build | In your hands | ~Cost, 10 boards | Notes |
|---|---|---|---|---|
| **JLCPCB + assembly**, DHL express | 3–5 days | **~1 week** | ~$60–90 boards + parts | Economic PCBA, top side. Best cost/speed balance. |
| PCBWay + assembly | similar | ~1–2 weeks | somewhat more | Equivalent; use if JLC's DFM queue stalls |
| Bay Area Circuits (Fremont), bare boards | same day | same/next day | $$$ | Only if the schedule turns on days; you then place ~50 SMD parts per board yourself |

**Recommendation: JLCPCB with assembly and express shipping.**

One caveat on the "24 hour build" everywhere: the clock starts *after* DFM
review, which can add a day. Submit early in their working day and check for
DFM queries so the file is not sitting waiting on your reply.

## Order settings — JLCPCB

Upload `baybasi-ctrl-<date>-gerbers.zip` and take the defaults except where noted.

| Setting | Value | Why |
|---|---|---|
| Base material | FR-4 | |
| Layers | 2 | |
| Dimensions | 100 × 95 mm | auto-detected from Edge.Cuts |
| PCB qty | **5** | build one, prove it, then order the rest |
| Thickness | 1.6 mm | |
| Surface finish | **HASL (lead free)** | free; ENIG buys flatness we have no use for |
| Outer copper | 1 oz | |
| Via covering | Tented | |
| Remove order number | "Specify a location" | keeps it off the visible face |
| **PCB Assembly** | **Yes — Economic, top side, qty 5** | SMD + THT; "Confirm Parts Placement" on. Quoted $50.72 for five assembled boards on 2026-09-07, before shipping (an earlier $44.72 figure had the devkit sockets unticked) |
| BOM / CPL | `jlcpcb-bom.csv`, `jlcpcb-cpl.csv` | regenerate with `make_cpl.py` after any change |

## Before you click order

- [ ] `./export_fab.sh` exits 0 — no unrouted nets, no DRC errors
- [ ] `python3 make_cpl.py` says "BOM and CPL agree"
- [ ] **Print the layout at 1:1 on paper and stand the real parts on it.** Every
      one, including the devkit and the W5500. Check the printer did not scale.
- [ ] RJ45 face sits 6 mm inside the top edge; the plug clears H1's standoff
- [ ] Every part JLCPCB matched is the intended value and package (3.5 mm
      blocks for J1–J12, 5.08 mm for J13, DIP-20 *socket* for U1/U2)
- [ ] Placement preview: SOT-223 tab up, SOT-23 pin 1 where the silkscreen dot is
- [ ] Gerber preview on the fab's site looks like `board3d.png`

## Files

| File | Purpose |
|---|---|
| `gen_sch.py` | generates the schematic — edit this, not the `.kicad_sch` |
| `gen_pcb.py` | generates the PCB; re-verifies placement on every run |
| `route.sh` | headless autoroute: DSN out, Freerouting, SES back, pad ties, pour repair, DRC |
| `export_fab.sh` | DRC gate + Gerber/drill export + zip |
| `make_cpl.py` | JLCPCB CPL from the board (pad centres, JLC rotations), cross-checked with the BOM |
| `jlcpcb-bom.csv` | assembly BOM with LCSC numbers where known |
| `drc-full.rpt` | last DRC including warnings |

## Panel power stays off this board - DECIDED 2026-09-20

Settled: the board carries DATA and GND only. Panel +5 V is run separately
from the supply, and the red conductor in every JST-SM lead stays cut and
capped at both ends. The alternative considered was a co-routed
power+data cable out of the board, three conductors per panel.

Rejected on current. Twelve panels at full white is 12 x 15.4 A = 184 A. Even
a fraction of that has no business crossing a 2-layer signal board, its
terminal blocks or its ground pour. Keeping the two apart means the board's
GND connection is a signal reference tap and nothing else, which is also why
it is mounted mid-column: the tap lands in the middle of the column's ground
bus rather than at one end.

Consequence for the build: every panel needs a power drop from the riser as
well as a data lead from the board. That is more wiring, and it is the right
trade. See the power-riser design for the distribution.

## Devkit header pitch - rev A 22.86 mm, rev B 25.4 mm (settled 2026-09-21)

**Rev B is fitted at 25.4 mm. Rev A - batch 1, five boards - is at 22.86 mm.**
Two boards that look identical and take different devkits. This was the whole
point of the rev B respin; the only other change is SW1.

The confusion this section exists to prevent: **25.40 mm is the official
DevKitC-1's board WIDTH, and 22.86 mm is its row spacing.** Espressif's own
dimension drawing gives both - board width 25.40, 1.27 mm from each edge to the
pin-row centreline, so 25.40 - 1.27 - 1.27 = 22.86. Their difference is also
2.54 mm, so mixing the two yields "exactly one pitch" as an artefact and reads
like confirmation. Rev A was never wrong for the part it was drawn for.

  https://dl.espressif.com/dl/schematics/esp_idf/DXF_ESP32-S3-DevKitC-1_V1.1_20220429.pdf

The third-party ESP32-S3 boards actually in hand are at **25.4 mm** between
rows - one 2.54 mm pitch wider than Espressif's, same pinout pad for pad. They
are about 28 mm wide, not 25.4. They do not seat in a rev A board and must not
be forced.

**Measure hole centre to hole centre, on a bare unsoldered board, or do not
measure at all.** A photograph cannot settle it: the board and the ruler are
not coplanar, so the parallax is the same order as the difference being
measured. Confirmed that way 2026-09-15, and independently from the shipped
fabrication data:

| Gerber zip | A1L column X | A1R column X | Spacing |
|---|---|---|---|
| `baybasi-ctrl-20260907-gerbers.zip` (rev A) | 135.570 | 158.430 | **22.860 mm** |
| `baybasi-ctrl-20260921-gerbers.zip` (rev B) | 135.570 | 160.970 | **25.400 mm** |

22 holes in each column on 2.54 pitch over the same Y span. A1L never moved;
only A1R did, by exactly one pitch. **Verify a shipped board's geometry from
the `.drl` inside the gerber zip, not from the `.kicad_pcb`** - the zip is what
the fab actually cut.

The spacing lives in one place, `gen_pcb.py`:

    A1_PITCH   = 25.4
    A1_PAD1    = (35.57, 17.0)
    POS['A1L'] = (A1_PAD1[0], A1_PAD1[1], 0)
    POS['A1R'] = (A1_PAD1[0] + A1_PITCH, A1_PAD1[1], 0)

`A1_BODY` and the silkscreen outline derive from `A1_PAD1`, so they follow. The
silkscreen carries the revision for exactly this reason - **read the board
before you pick a devkit for it.**

### Buying devkits

**Order two and confirm one seats before buying the rest.** Not because the
geometry is in doubt any more, but because a week and $32 is cheap against
eight wrong boards.

For rev B, buy the same third-party 25.4 mm boards already in hand. The
official part is only needed for a rev A board.

Orderable part: **ESP32-S3-DevKitC-1-N8R8**. DigiKey and Mouser stock it; so does
Espressif's own Amazon storefront, ASIN B09MHP42LY:

  https://www.amazon.com/stores/ESPRESSIFSYSTEMS/page/C3408769-6DB1-4CC2-A7B3-59C8EBAC8205

**Buy through the Espressif storefront, not an Amazon search.** Marketplace
listings titled "ESP32-S3-DevKitC-1" are overwhelmingly third-party boards with
that pinout and a different row pitch - almost certainly where the 25.4 mm boards
in hand came from. Row spacing is stated in no listing anywhere, so the brand and
seller are the only signal.

Any flash/PSRAM variant works: the firmware is ~300 KB and a double-buffered
column of 3 072 pixels is ~18 KB. The **R8** part is what matters to keep
identical - octal PSRAM reserves GPIO 35, 36, 37 internally, and this design
already routes around all three.

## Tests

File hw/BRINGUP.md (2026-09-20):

# Board bring-up — BAYBASI COLUMN CTRL revA, batch 1

Validation procedure for the five assembled boards, 2026-09-15.

**Constraint this is written around:** the ESP32-S3 devkits in hand have their
header rows at **25.4 mm**; A1L/A1R are at **22.86 mm**. The **left row seats,
the right row does not.** Everything below works with the devkit half-seated.
Batch 2 will move A1L/A1R to 25.4 mm — see FABRICATION.md.

Every pin number below is extracted from `net.net`, not counted by hand.

Work top to bottom. Each step gates the next, so a failure is isolated to the
step that found it. **Do not skip step 0** — it is the one that catches an
assembly fault before you put energy into it.

---

## Step 0 — Meter only. No power, no ICs, no devkit, no W5500

### 0.1 Visual

- Solder bridges, especially across U1/U2 socket pins and the 0805 rows.
- All twelve terminal blocks: wire entry faces the board edge, matching the
  silkscreen arrow.
- Electrolytics C1–C4: stripe matches the silkscreen.

### 0.2 The supply input must not be a short

**J13 pin 1 (`+`, square pad) to J13 pin 2 (GND).**

Expect a **brief** beep as C1–C4 charge from the meter's own ~1 mA, then a
reading climbing into the kΩ. **A beep that never stops is a short — stop here.**
Short the terminals before repeating, or the caps are still charged and you will
see nothing the second time.

### 0.3 Output chain sweep — the big one

ICs **out** of their sockets. Probe socket pin to terminal block. This proves all
twelve series resistors, both buffers' output traces and every connector, with no
power anywhere.

| Out | Socket pin | Terminal | Expect |
|---|---|---|---|
| D1 | U1 pin 18 | J1 pin 1 | **330 Ω** |
| D2 | U1 pin 17 | J2 pin 1 | 330 Ω |
| D3 | U1 pin 16 | J3 pin 1 | 330 Ω |
| D4 | U1 pin 15 | J4 pin 1 | 330 Ω |
| D5 | U1 pin 14 | J5 pin 1 | 330 Ω |
| D6 | U1 pin 13 | J6 pin 1 | 330 Ω |
| D7 | U2 pin 18 | J7 pin 1 | 330 Ω |
| D8 | U2 pin 17 | J8 pin 1 | 330 Ω |
| D9 | U2 pin 16 | J9 pin 1 | 330 Ω |
| D10 | U2 pin 15 | J10 pin 1 | 330 Ω |
| D11 | U2 pin 14 | J11 pin 1 | 330 Ω |
| D12 | U2 pin 13 | J12 pin 1 | 330 Ω |

Then, every `J`n **pin 1 to GND: 10 kΩ** (R16–R27, the output pull-downs), and
every `J`n **pin 2 to GND: 0 Ω**.

`J`n pin 1 is the **square** pad — the silkscreen says `J1-J12: SQ PAD = DATA`.

### 0.4 Enable and power nets

| Check | Expect |
|---|---|
| U1 pin 19 ↔ U2 pin 19 ↔ A1L pin 12 | 0 Ω — one net, `OE_N` |
| U1 pin 19 to +3V3E (M2 pin 2) | 10 kΩ — R15 pull-up |
| A1L pin 21 ↔ U1 pin 20 ↔ U2 pin 20 | 0 Ω — the 5 V rail |
| J13 pin 1 to A1L pin 21 | a **diode drop**, not 0 Ω — through Q1 |
| A1L pin 22, A1R pins 1/21/22, U1 pins 8/10 to J13 pin 2 | 0 Ω — GND |
| A1L pin 8 to M2 pin 5 | 0 Ω — `ETH_RST` |

---

## Step 1 — Power, nothing fitted

Bench supply to **5.00 V** with the **current limit at 100 mA**. The limit is the
safety net: a fault trips it instead of burning a trace.

Apply to J13, square pad positive.

| Measure | Expect |
|---|---|
| Supply current | a few mA. **If it sits at the 100 mA limit, stop** |
| U1 pin 20 | ~4.7 V (5 V less Q1's drop) |
| M2 pin 2 (+3V3E) | 3.3 V — U3 is alive |
| U1 pin 19 (/OE) | ~3.3 V — outputs **disabled**, which is correct with no devkit |

### 1.1 Reverse polarity, once (optional)

Still limited to 100 mA, reverse the supply leads. Expect **~0 mA** — Q1 blocking.
This validates the QA fix from 2026-09-07, where S and D were transposed and the
body diode would have passed a reversed supply. Restore correct polarity after.

---

## Step 2 — Devkit, left row only

Power off. Seat the devkit's **left** row in A1L, USB ports toward the bottom edge.

- **Insulate the unseated right row.** Those pins sit over U2's socket and the
  output resistors. Card or Kapton underneath.
- Support the raised side so the seated pins do not carry a bending moment.

Raise the current limit to 500 mA. Power from **J13 only, no USB**.

**The devkit should come up.** That proves A1L pins 21 and 22 are making real
contact — the two that matter most, tested in one second.

---

## Step 3 — Flash, and prove the /OE path

USB to the devkit's **COM** port (the UART bridge).

```bash
cd fw-bench
pio run -e ctrl-all12 -t upload
```

**Flash `ctrl-all12`, not `ctrl-board`.** It drives all twelve outputs from one
binary, each in its own colour, with **N white pixels at the head of the chain
where N is the output number**. So you flash once and then just move a panel
around: no rebuild between outputs, and if you plug into J7 and count six white
pixels you have found a wiring error rather than a dead output.

With the devkit half-seated it still works for D1-D3; D4-D12 simply have nothing
on the other end yet.

Monitor on the **USB** port — the env sets `ARDUINO_USB_CDC_ON_BOOT=1`.

The banner prints, including `/OE on GPIO 8 driven LOW: 245 outputs enabled`.

**Now measure U1 pin 19: it must be LOW (< 0.4 V).** It was 3.3 V in step 1. That
transition proves the whole /OE path — devkit GPIO 8, A1L pin 12, the trace, both
buffers — through a socket contact you cannot see.

---

## Step 4 — U1 and the first panel

**Power everything down first.**

### 4.1 Form the DIP legs

New DIP ICs ship with their leads splayed to ~8.5 mm for auto-insertion. The
socket is **7.62 mm**. Press an unformed DIP onto a socket and it perches on top
making no contact.

Lay the IC on its side on a flat hard surface, legs against the surface, and roll
the body toward the legs until that row is parallel and vertical. Flip, repeat.

**Check pin 1 against the socket notch and the silkscreen.** A '245 in backwards
puts 5 V on the outputs and ground on VCC. Insert until the body is flush, then
pull it back out once — a seated DIP resists. If it lifts away freely it was never in.

### 4.2 Wire the panel

- Panel 5 V and GND **from the bench supply on its own thick leads**. Never from
  this board. J1–J12 carry DATA + GND only, which is exactly why this board
  cannot repeat the dev-kit failure of 2026-09-13.
- Panel **DIN → J1 pin 1** (square pad).
- Panel **GND → J1 pin 2**. Keep the panel's power leads short and thick so this
  signal ground carries negligible current.

### 4.3 Light it

Start with a small budget. 256 LEDs at white is 15.4 A; FastLED scales the frame
to fit whatever you declare.

```bash
PLATFORMIO_BUILD_FLAGS="-DSUPPLY_MA=1000" pio run -e ctrl-board -t upload
```

**Panel supply on first, board second.** Every time.

Expect the four bench patterns, dim. Raise `SUPPLY_MA` toward what the supply can
actually deliver once it works.

---

## Step 5 — D2 and D3

Move the panel to J2, rebuild with `-DLED_PIN=5`. Then J3 with `-DLED_PIN=6`.

Three of U1's six outputs proven. D4–D12 need the right row.

---

## Step 6 — U2, one jumper at a time

Fit U2 (form the legs, check pin 1). Its inputs come from the right row.

**Best method: put the devkit in a breadboard** and run **male-to-male** jumpers
from the breadboard rows into the socket holes. The breadboard gives strain
relief and a stable platform, which flying leads onto bare header pins do not.
Devkit from USB, board from J13, and the GND jumper is what ties them.

Fourteen jumpers reach everything. **Count holes from the TOP of the board.**

| Signal | Devkit pin | Hole |
|---|---|---|
| GND | GND | A1L 22 |
| /OE | 8 | A1L 12 |
| D1 | 4 | A1L 4 |
| D2 | 5 | A1L 5 |
| D3 | 6 | A1L 6 |
| D4 | 1 | A1R 4 |
| D5 | 2 | A1R 5 |
| D6 | 21 | A1R 18 |
| D7 | 38 | A1R 10 |
| D8 | 39 | A1R 9 |
| D9 | 40 | A1R 8 |
| D10 | 41 | A1R 7 |
| D11 | 42 | A1R 6 |
| D12 | 47 | A1R 17 |

A second GND jumper (A1R 1, 21 or 22) costs nothing and helps if you see flicker.

Do **not** jumper 5 V: the devkit's 5 V pin back-feeds this board through Q1.

**Count check before trusting it:** A1R holes 1, 21 and 22 are all GND, so all
three are dead shorts to J13 pin 2. If they are not, you are counting from the
wrong end.

Which buffer each output goes through, for fault isolation:

| Out | Devkit pin | A1R hole | Terminal | Buffer |
|---|---|---|---|---|
| D4 | 1 | 4 | J4 | U1 |
| D5 | 2 | 5 | J5 | U1 |
| D6 | 21 | 18 | J6 | U1 |
| D7 | 38 | 10 | J7 | **U2** |
| D8 | 39 | 9 | J8 | U2 |
| D9 | 40 | 8 | J9 | U2 |
| D10 | 41 | 7 | J10 | U2 |
| D11 | 42 | 6 | J11 | U2 |
| D12 | 47 | 17 | J12 | U2 |

**D7 is the one that matters** — it is the first output through U2, so it proves
the second buffer, its supply and its enable. With `ctrl-all12` there is nothing
to rebuild; just move the panel to J7 and count seven white pixels.

**PASSED 2026-09-20.** J4 -> 4 white pixels, J7 -> 7. U1 and U2 both good, A1L
and A1R both good. Note what the count buys you: it separates "this output is
dead" from "your jumpers are off by one", which is the failure this rig is most
likely to produce and the one most easily mistaken for a bad chip.

Verify the hole count before trusting it: A1R pin 1, 21 and 22 are all GND, so
holes 1, 21 and 22 are dead shorts to J13 pin 2. If they are not, you are counting
from the wrong end.

---

## Step 7 — Ethernet

Every W5500 signal is on the seated left row, so this needs no jumpers.

Fit the module — silkscreen says `MODULE PIN 1 AT TOP`. Then flash the production
firmware in `../fw`, which has never run on hardware.

Check in order: link LED on the RJ45, ARP/ping from the Pi, then DDP frames.

---

## What this cannot test on batch 1

- **All twelve outputs at once.** Nine of them need one jumper each; driving them
  simultaneously through nine flying leads is not a meaningful test of anything.
- **Full-column current.** That is a power test, not a board test — see the power
  riser sheet.

Both clear the moment a devkit seats on both rows: either batch 2 at 25.4 mm, or a
devkit soldered in a batch-1 board used as a jig (FABRICATION.md).

---

## Fault table

| Symptom | Look at |
|---|---|
| Step 1 pegs the current limit immediately | J13 polarity; C1–C4 orientation; Q1; a bridge under U1/U2 |
| No 3.3 V at M2 pin 2 | U3 and its input/output caps |
| /OE stays at 3.3 V after flashing | A1L pin 12 not contacting — re-seat the left row |
| Devkit dead with board powered, no USB | A1L pins 21/22 not contacting |
| Panel dark, heartbeat fine, /OE low | U1 legs not formed; U1 pin 1 backwards; panel power; DIN on the round pad instead of the square one |
| Brief garbage on the panel at power-up | Normal. R16–R27 park DIN low until the firmware enables the buffers |
| One output dead, its neighbours fine | That R*n*, or that socket pin — re-run the step 0.3 sweep on it |
| Far end of a panel dim or orange | Voltage drop, not dead LEDs. Feed the panel at both ends |

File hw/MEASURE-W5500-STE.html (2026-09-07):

# W5500 Module — Measurement Request

Written in ASD-STE100 Simplified Technical English.

## 1. Why we need this data

We build a printed circuit board. The W5500 module attaches to this board.

The module has two rows of pins. We must know the distance between the two rows. We must know this distance before we make the board.

The manufacturer does not give this distance. The data sheet does not have it.

Important

Do not send a photograph of the module with a ruler. We tried this two times. It did not work.

A photograph gives an error of 2 mm to 7 mm. The distance that we must find changes in steps of 2.54 mm. Thus the error is larger than the step. A photograph cannot give the correct answer.

## 2. Procedure A — count the holes

This procedure gives an exact answer. You do not measure a length. You count holes.

1. Get a breadboard. You can also use a piece of perfboard. The holes must have a pitch of 0.1 inch (2.54 mm).
2. Push the pins of the module into the holes. Push the module down fully.
3. Select one pin in the first row.
4. Find the pin in the second row that is directly opposite this pin.
5. Count the empty holes between the two pins.
6. Record this number.

Send us the number only. Do not measure a distance.

## 3. Procedure B — find the direction of the socket

1. Hold the module. The pins must point down.
2. Turn the module until the Ethernet socket points at you.
3. Look at the two rows of pins.
4. Tell us the direction of the rows. The rows go from left to right, or the rows go away from you.

## 4. Procedure C — identify the module

1. Read the text that is printed on the circuit board.
2. Send us this text. You can also send a photograph of the text.

The module is one of two types. It is a WIZnet WIZ850io. It is also possible that it is a W5500 Lite copy or a USR-ES1 copy.

The two types have the same pin functions. The two types do not have the same shape. Thus we must know the type.

## 5. What we do with your data

### Data from procedure A

The pitch of the pins is 2.54 mm. This value is a standard. Thus we calculate the distance:

distance = (number of holes + 1) × 2.54 mm

Holes between the rows | Distance | Note
0 | 2.54 mm | The two rows touch. This is one 2 × 6 connector.
5 | 15.24 mm
6 | 17.78 mm
7 | 20.32 mm | This is the value that our design uses now.
8 | 22.86 mm | This is the same as the ESP32 board.

### Data from procedure B

We turn the module on the circuit board. The Ethernet socket must point away from the board. Your data tells us the angle.

### Data from procedure C

Your data tells us if the distance is correct for our module.

## 6. If you do not have a breadboard

1. Get a caliper.
2. Measure from the center of one pin to the center of the pin opposite it.
3. Send us the value. Give one number after the decimal point.

We round your value to the nearest multiple of 2.54 mm. The correct value is always a multiple of 2.54 mm.

After we get your answer, we change one line in the file gen_pcb.py. Then we make the board again and we test it. This operation takes 10 seconds. We do not order the boards before we have your answer.

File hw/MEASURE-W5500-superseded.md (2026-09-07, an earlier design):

# Ask your friend for three things

Copy-paste the block below. It avoids rulers and photographs entirely — both
failed us already, because a 2.54 mm error and a 2.54 mm answer look identical
through a camera.

---

**1 — Row spacing, counted not measured.**

Push the module's pins into a breadboard or a scrap of 0.1-inch perfboard so it
seats fully. Then pick any pin in one row, look straight across at the pin
opposite it in the other row, and **count the empty hole positions between
them.**

Just the number. Don't measure anything.

**2 — Which way does the RJ45 face?**

Hold the module with the pins pointing down and the Ethernet socket facing you.
Are the two pin rows running **left-to-right** across your view, or
**away from you** (front to back)?

**3 — What is it exactly?**

Photograph the silkscreen text on the PCB, or read it out. I need to know
whether it is a genuine WIZnet **WIZ850io** or one of the **W5500 Lite /
USR-ES1** clones — the signal order is identical but the board outlines are not.

---

## What we do with the answers

**Answer 1** gives the spacing exactly. Pin pitch is 2.54 mm by definition, so
if there are *N* empty holes between the rows:

    W5500_ROW_MM = (N + 1) * 2.54

| holes between | spacing | |
|---|---|---|
| 0 | 2.54 mm | the two rows are adjacent — a plain 2×6 header |
| 5 | 15.24 mm | |
| 6 | 17.78 mm | |
| **7** | **20.32 mm** | what `gen_pcb.py` currently assumes |
| 8 | 22.86 mm | same as the ESP32 devkit rows |

Set the constant at the top of `gen_pcb.py`, run `python3 gen_pcb.py`, and the
placement checker re-verifies the whole board. If the new spacing collides with
anything it will say so before the file is written.

**Answer 2** decides the module's rotation on the board, so the RJ45 points off
the left edge instead of into the ground pour.

**Answer 3** is the reason we're asking at all: WIZnet publish the pinout but
not the mechanical spacing, and the clones are not guaranteed to match.

## If they can't get to a breadboard

Second best: calipers **across the two rows, pin centre to pin centre**, and
tell us the number to one decimal. We'll round to the nearest multiple of
2.54 mm — the true value is always one of those.

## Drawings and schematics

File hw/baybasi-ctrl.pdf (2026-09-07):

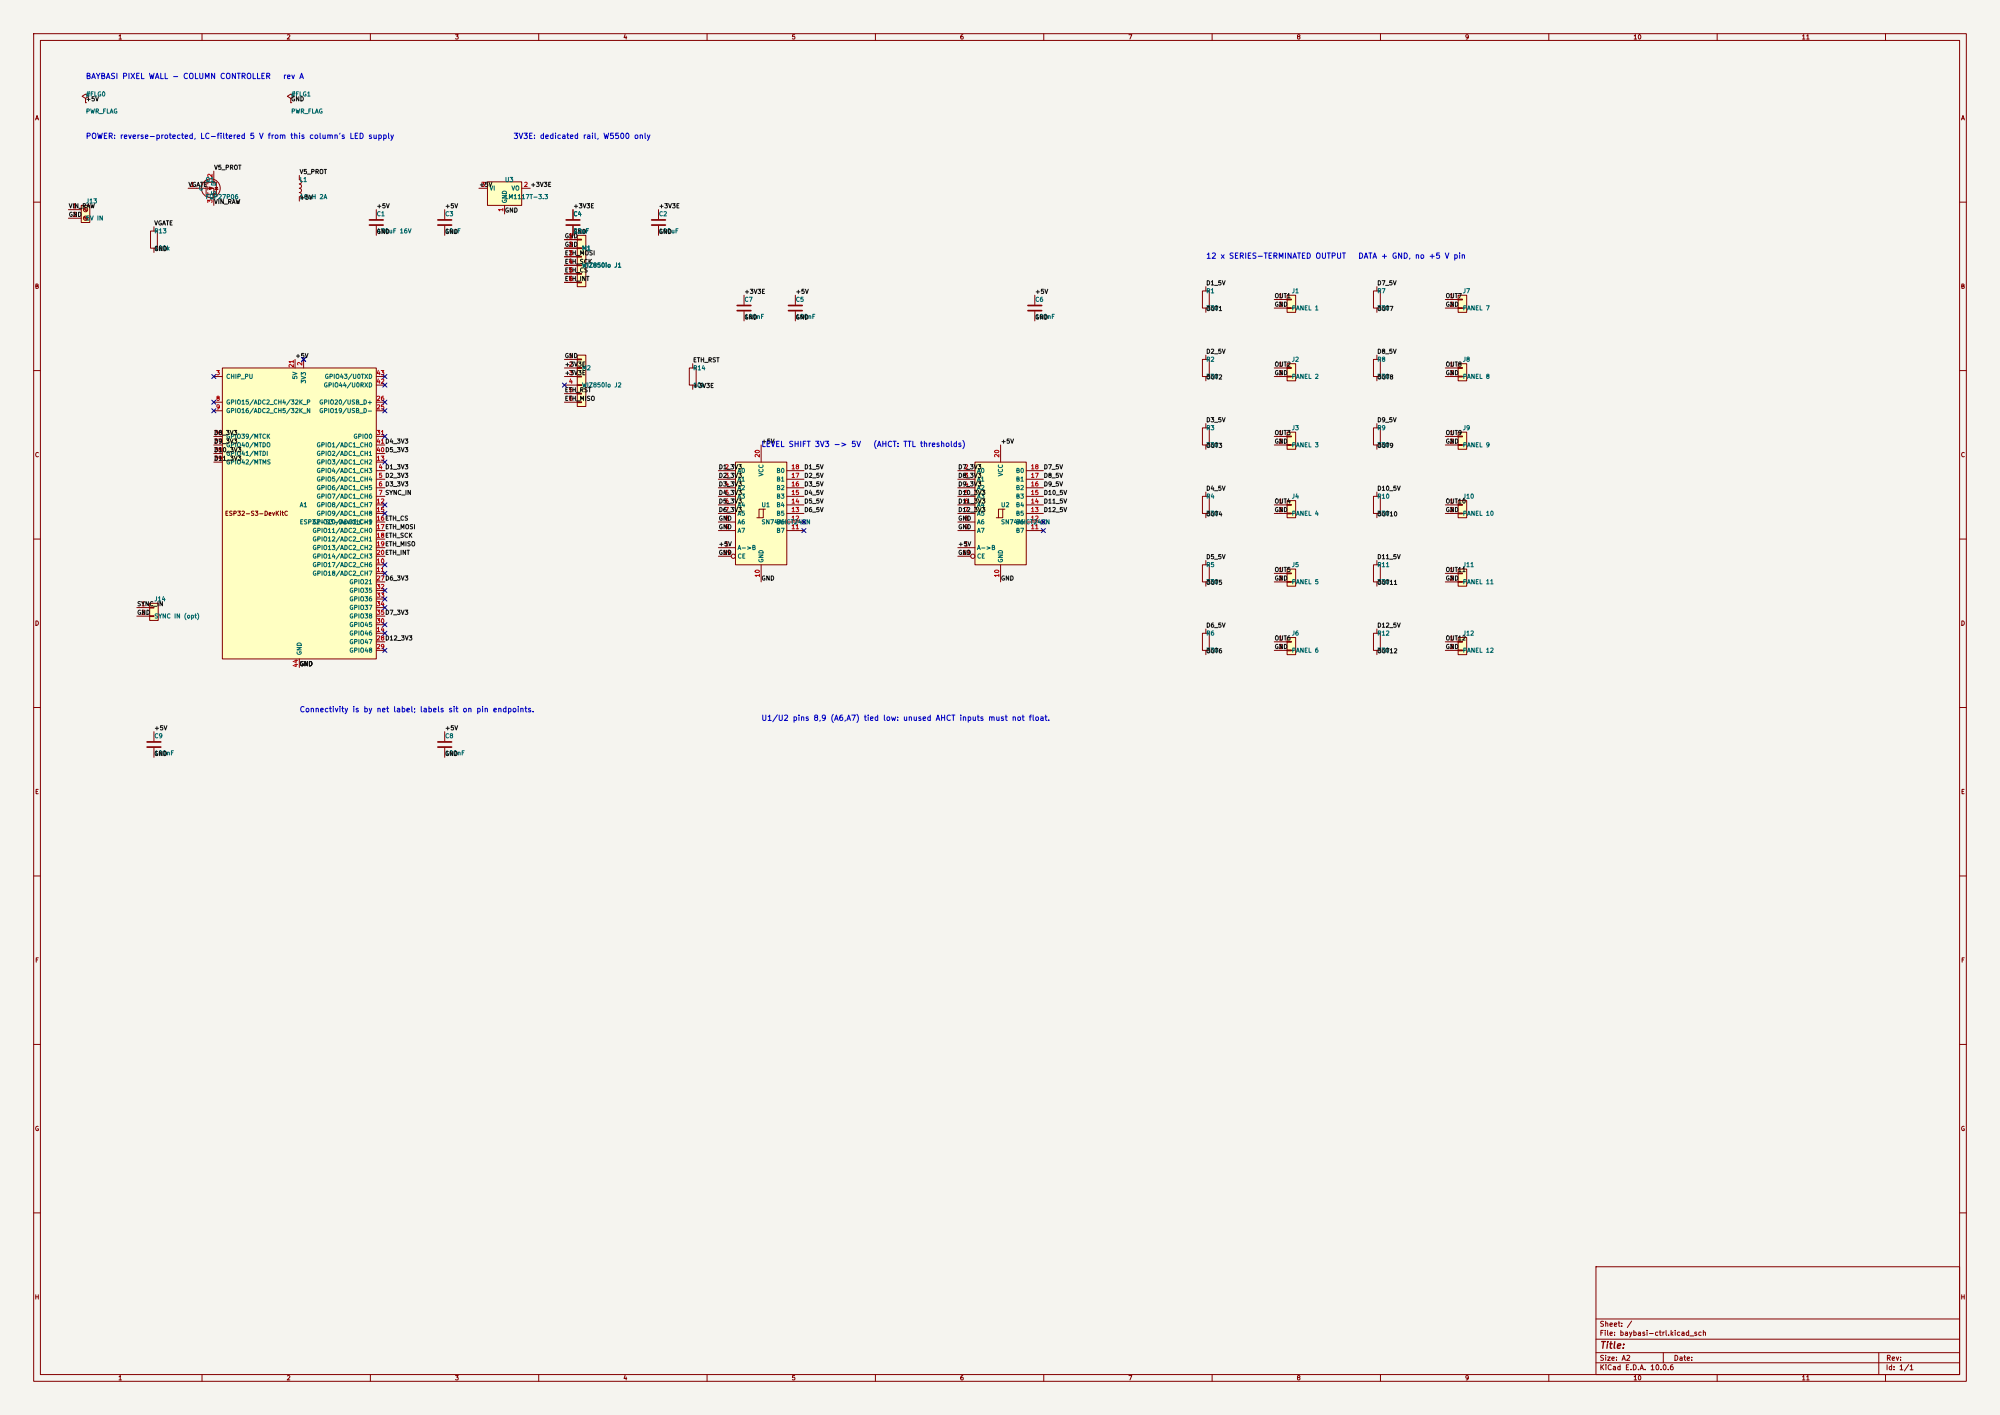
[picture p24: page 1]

POWER: reverse-protected, LC-filtered 5 V from this column's LED supply

Connectivity is by net label; labels sit on pin endpoints.

U1/U2 pins 8,9 (A6,A7) tied low: unused AHCT inputs must not float.

Size: A2 | Rev:
KiCad E.D.A. 10.0.6 | Id: 1/1

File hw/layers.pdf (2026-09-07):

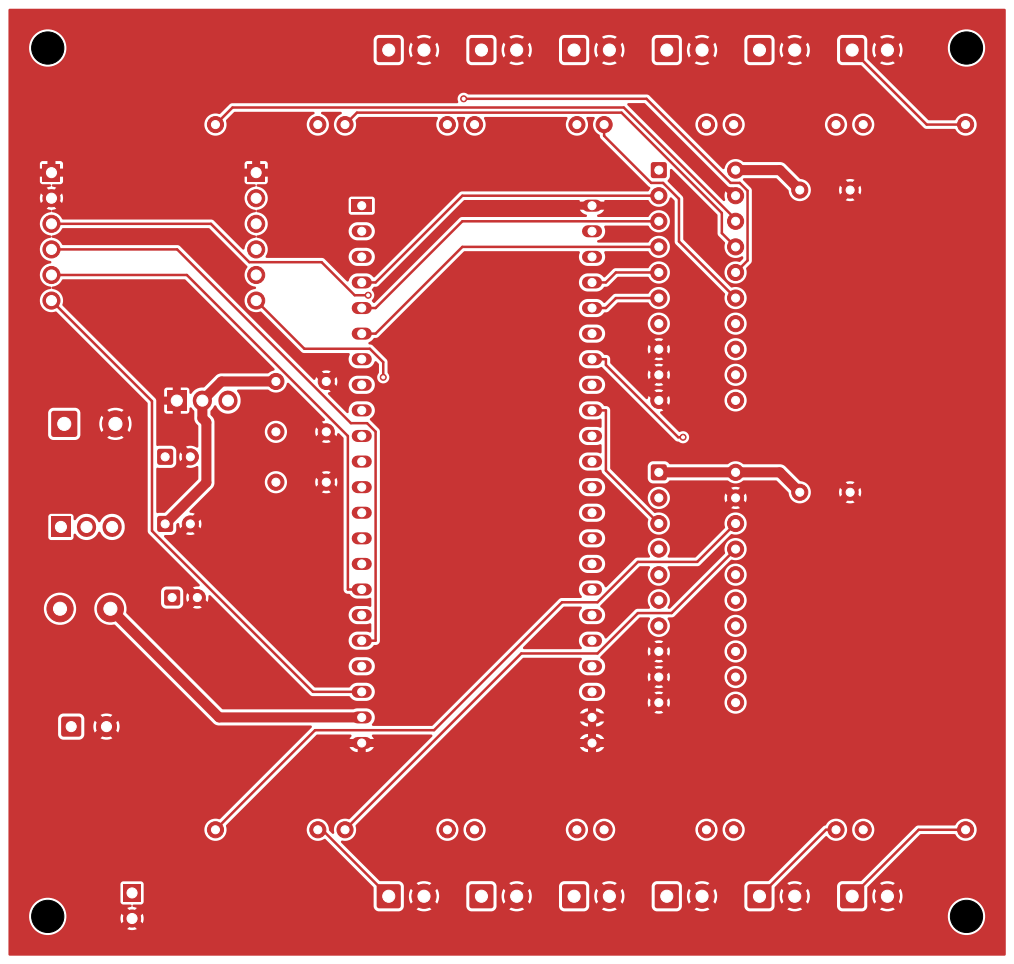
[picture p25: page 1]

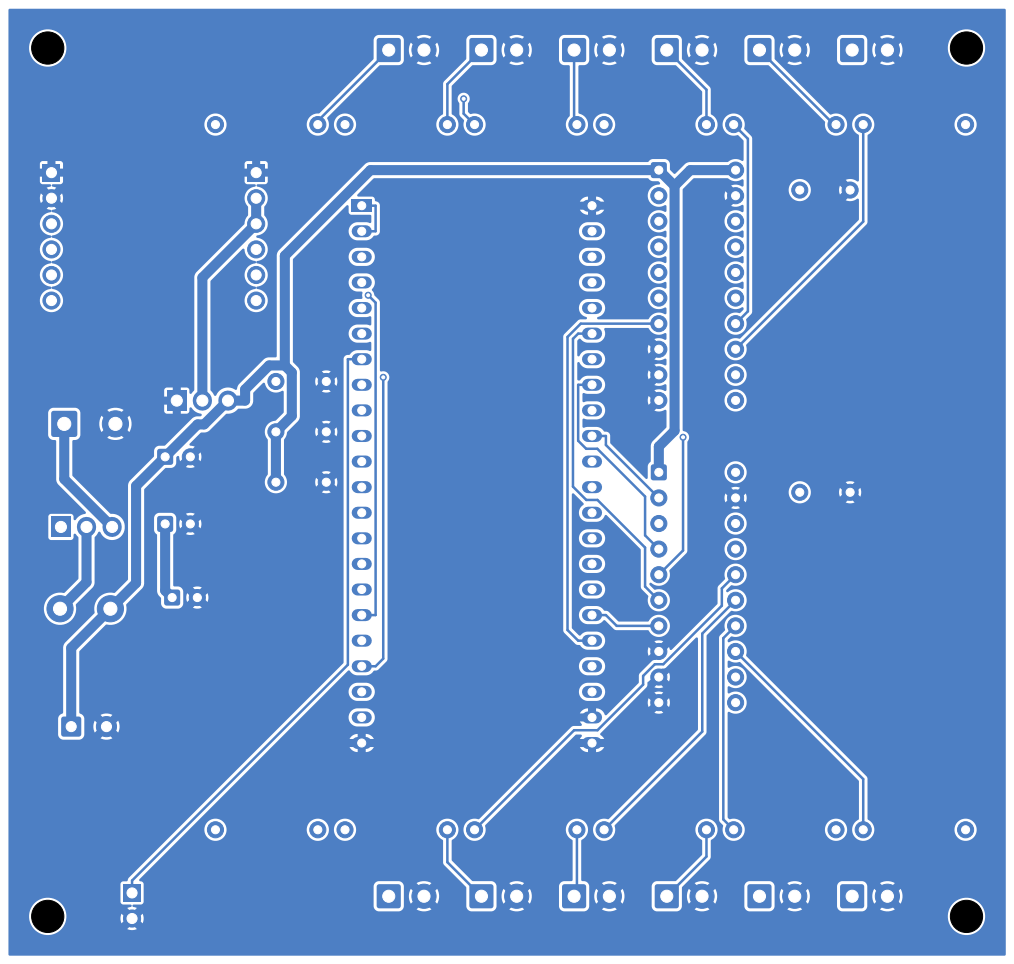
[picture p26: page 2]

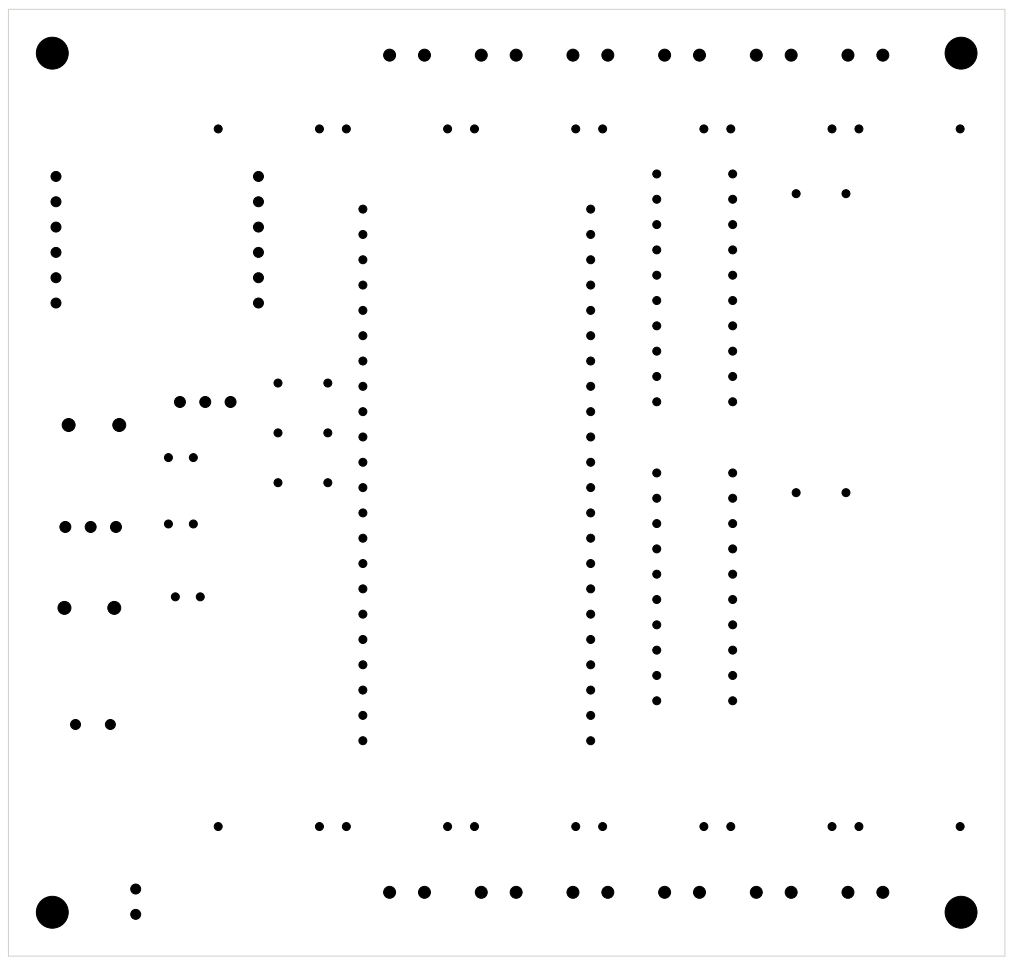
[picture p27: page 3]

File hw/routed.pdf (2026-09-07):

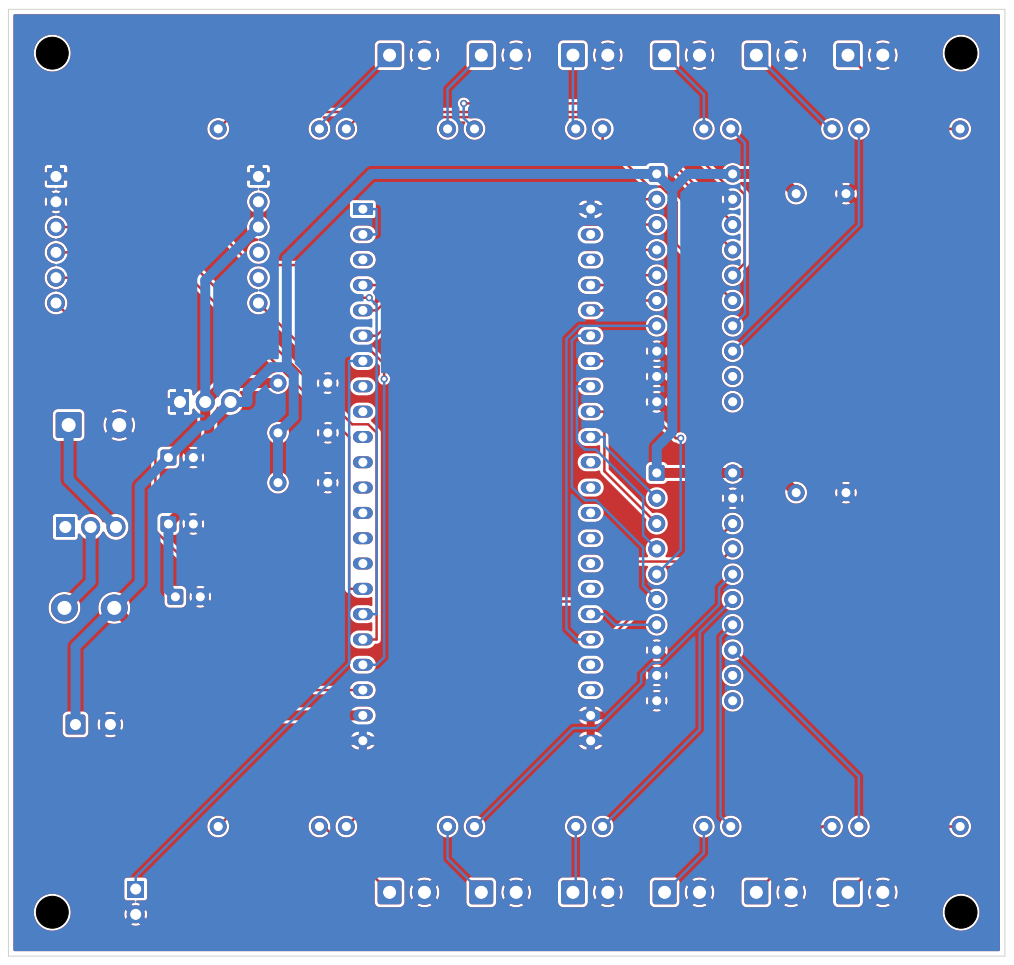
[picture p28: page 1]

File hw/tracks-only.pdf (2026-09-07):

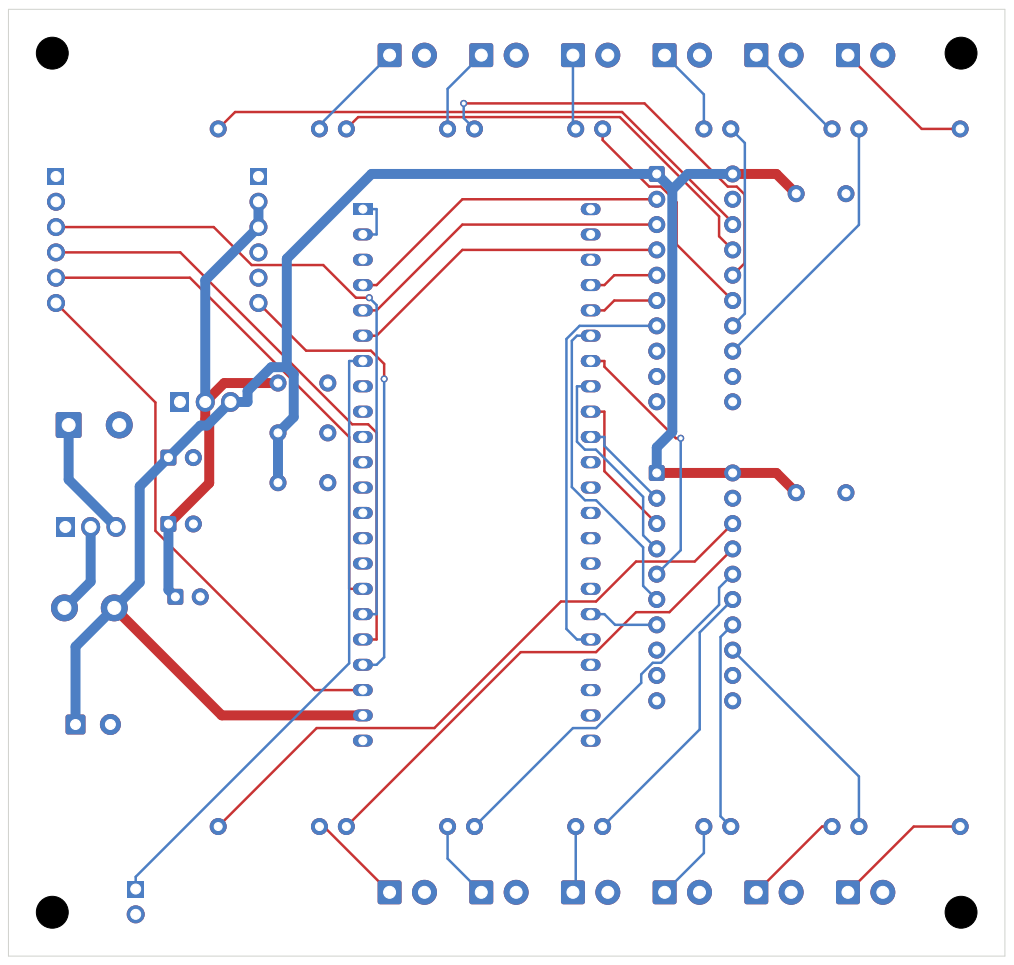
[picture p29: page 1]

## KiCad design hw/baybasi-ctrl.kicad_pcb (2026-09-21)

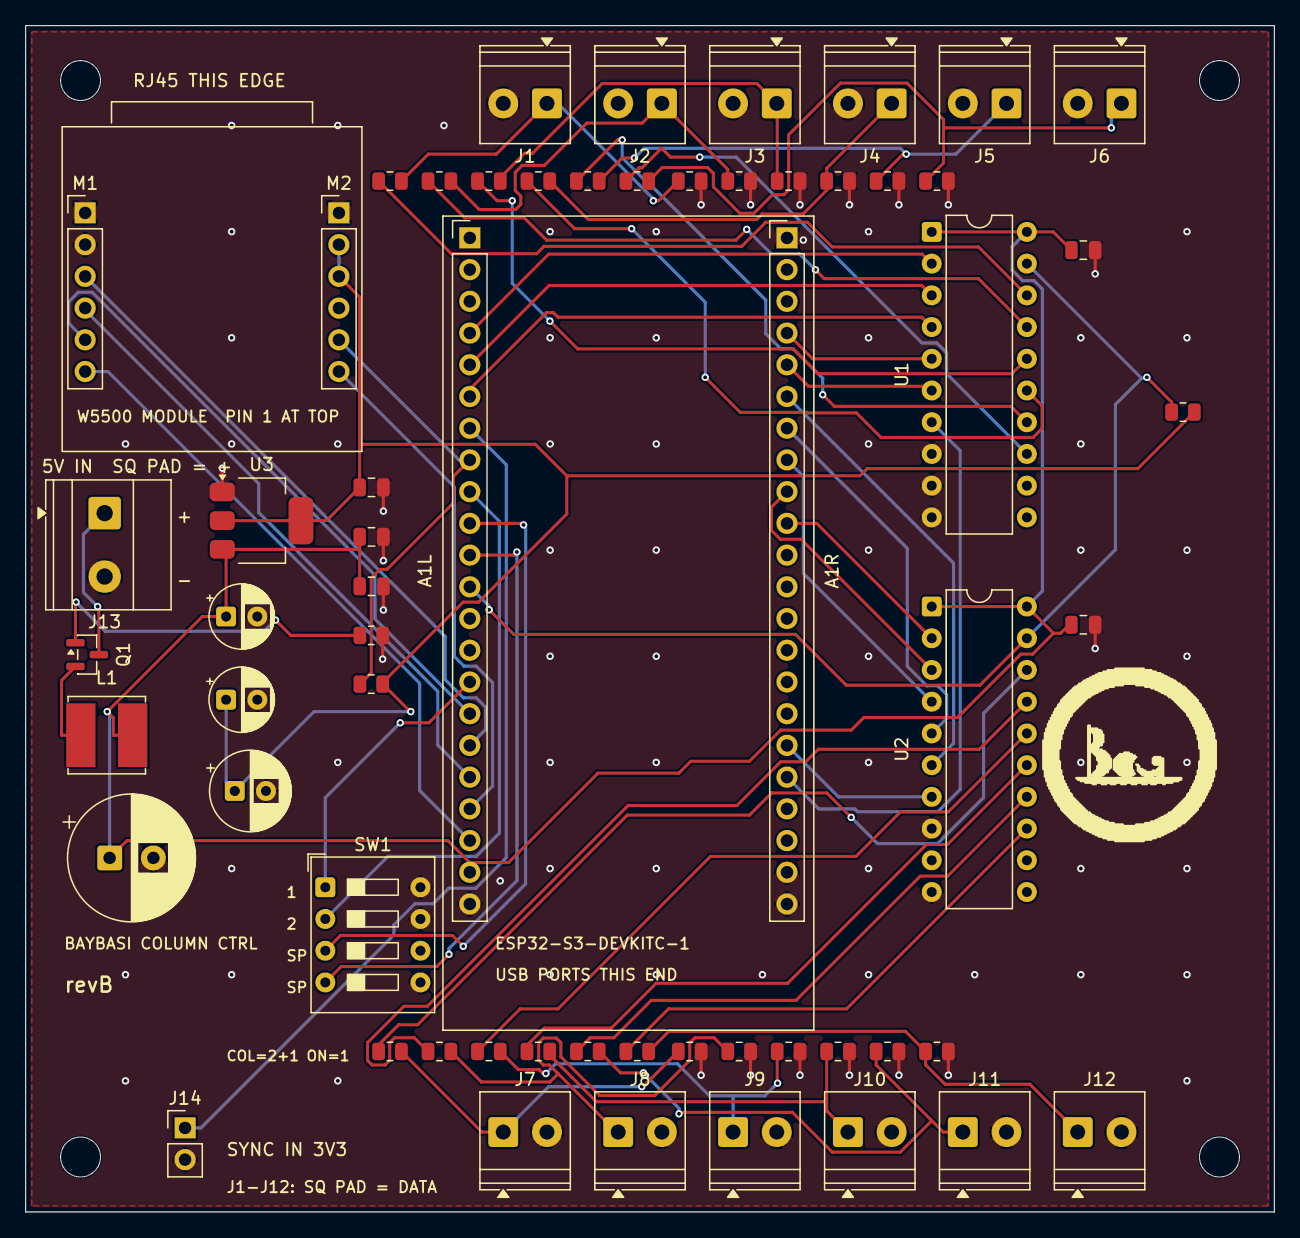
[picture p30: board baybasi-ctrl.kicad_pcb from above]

Board: 2 copper layers, 100.0 x 95.0 mm, 64 parts (0 on the bottom side), 54 nets.

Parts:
A1L, A1R: PinHeader_1x22_P2.54mm_Vertical
C1: CP_Radial_D10.0mm_P3.50mm
C2: CP_Radial_D6.3mm_P2.50mm
C3, C4: CP_Radial_D5.0mm_P2.50mm
C5, C6, C7, C8, C9: C_0805_2012Metric
H1, H2, H3, H4: MountingHole_3.2mm_M3
J1, J2, J3, J4, J5, J6, J7, J8, J9, J10, J11, J12: TerminalBlock_Phoenix_PT-1,5-2-3.5-H_1x02_P3.50mm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; TerminalBlock_Phoenix_PT-1,5-2-3.5-H_1x02_P3.50mm_Horizontal
J13: TerminalBlock_Phoenix_MKDS-1,5-2-5.08_1x02_P5.08m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; TerminalBlock_Phoenix_MKDS-1,5-2-5.08_1x02_P5.08mm_Horizont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
J14: PinHeader_1x02_P2.54mm_Vertical
L1: L_Bourns_SRN6045TA
M1, M2: PinHeader_1x06_P2.54mm_Vertical
Q1: SOT-23
R1, R2, R3, R4, R5, R6, R7, R8, R9, R10, R11, R12, R13, R14, R15, R16, R17, R18, R19, R20, R21, R22, R23, R24, R25, R26, R27: R_0805_2012Metric
SW1: SW_DIP_SPSTx04_Slide_9.78x12.34mm_W7.62mm_P2.54mm
U1, U2: DIP-20_W7.62mm
U3: SOT-223-3_TabPin2

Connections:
+3V3E: C2.1, C4.1, C7.1, M2.2, M2.3, R14.2, R15.2, U3.2
+5V: A1L.21, C1.1, C3.1, C5.1, C6.1, C8.1, C9.1, L1.2, U1.1, U1.20, U2.1, U2.20, U3.3
COL_B0: A1L.15, SW1.1
COL_B1: A1L.9, SW1.2
COL_SP0: A1L.10, SW1.3
COL_SP1: A1L.11, SW1.4
D1_3V3: A1L.4, U1.2
D1_5V: R1.1, U1.18
D2_3V3: A1L.5, U1.3
D2_5V: R2.1, U1.17
D3_3V3: A1L.6, U1.4
D3_5V: R3.1, U1.16
D4_3V3: A1R.4, U1.5
D4_5V: R4.1, U1.15
D5_3V3: A1R.5, U1.6
D5_5V: R5.1, U1.14
D6_3V3: A1R.18, U1.7
D6_5V: R6.1, U1.13
D7_3V3: A1R.10, U2.2
D7_5V: R7.1, U2.18
D8_3V3: A1R.9, U2.3
D8_5V: R8.1, U2.17
D9_3V3: A1R.8, U2.4
D9_5V: R9.1, U2.16
D10_3V3: A1R.7, U2.5
D10_5V: R10.1, U2.15
D11_3V3: A1R.6, U2.6
D11_5V: R11.1, U2.14
D12_3V3: A1R.17, U2.7
D12_5V: R12.1, U2.13
ETH_CS: A1L.16, M1.5
ETH_INT: A1L.20, M1.6
ETH_MISO: A1L.19, M2.6
ETH_MOSI: A1L.17, M1.3
ETH_RST: A1L.8, M2.5, R14.1
ETH_SCK: A1L.18, M1.4
GND: A1L.22, A1R.1, A1R.21, A1R.22, C1.2, C2.2, C3.2, C4.2, C5.2, C6.2, C7.2, C8.2, C9.2, J1.2, J2.2, J3.2, J4.2, J5.2, J6.2, J7.2, J8.2, J9.2, J10.2, J11.2, J12.2, J13.2, J14.2, M1.1, M1.2, M2.1, R13.2, R16.2, R17.2, R18.2, R19.2, R20.2, R21.2, R22.2, R23.2, R24.2, R25.2, R26.2, R27.2, SW1.5, SW1.6, SW1.7, SW1.8, U1.8, U1.9, U1.10, U2.8, U2.9, U2.10, U3.1
OE_N: A1L.12, R15.1, U1.19, U2.19
OUT1: J1.1, R1.2, R16.1
OUT2: J2.1, R2.2, R17.1
OUT3: J3.1, R3.2, R18.1
OUT4: J4.1, R4.2, R19.1
OUT5: J5.1, R5.2, R20.1
OUT6: J6.1, R6.2, R21.1
OUT7: J7.1, R7.2, R22.1
OUT8: J8.1, R8.2, R23.1
OUT9: J9.1, R9.2, R24.1
OUT10: J10.1, R10.2, R25.1
OUT11: J11.1, R11.2, R26.1
OUT12: J12.1, R12.2, R27.1
SYNC_IN: A1L.7, J14.1
V5_PROT: L1.1, Q1.2
VGATE: Q1.1, R13.1
VIN_RAW: J13.1, Q1.3

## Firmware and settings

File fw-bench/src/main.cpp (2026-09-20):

// Baybasi pixel wall — standalone ROW test
//
// Flash it, unplug the laptop, leave it running. Four patterns cycle forever on
// a row of four daisy-chained 16x16 WS2812B panels (1024 LEDs on one wire).
// Nothing waits on serial and nothing ever finishes, so the dev kit drives the
// panels on its own. Runs on a CLASSIC ESP32 devkit (ESP-WROOM-32, 30-pin,
// HW-394 or similar).
//
// This is NOT the production topology. The real controller gives each panel its
// own output: 256 LEDs per wire, 8 ms a frame, twelve in parallel. Chaining is a
// bench convenience. Nothing here transfers to ../fw except the serpentine map.
//
// POWER IS THE WHOLE DESIGN CONSTRAINT. 1024 LEDs at white is ~61 A and no
// bench supply wants that, least of all unattended. So no pattern here ever
// lights more than 256 LEDs at once, and most light far fewer. That is not only
// safer, it looks better: FastLED scales the whole frame down to fit the current
// cap, so lighting less at a time means what IS lit runs near full brightness.
//
// The onboard LED blinks once a second. If the panels are dark but that LED is
// blinking, the firmware is alive and the fault is power, data or the panels —
// not a crashed board. That is the only diagnostic you get with no laptop, and
// it is worth more than it looks.

#include <Arduino.h>
#include <FastLED.h>

// ---------------------------------------------------------------- hardware --
// One output; the panels are chained back to back. GPIO 13 avoids every ESP32
// strapping pin (0, 2, 5, 12, 15) and every input-only pin (34, 35, 36, 39).
//
// GPIO 12 is the one that bites: held high at reset it sets the flash voltage
// wrong and the board will not boot. On the header it sits between D14 and D13,
// so count pins rather than trusting the gap.
// NOT "LED_PIN". FastLED uses that name as a template parameter in 42 of its
// headers, so -DDATA_PIN=4 on the command line rewrites `int DATA_PIN,` to
// `int 4,` and the library will not compile. Defining it in this file after
// #include <FastLED.h> is safe, which is why the classic env never noticed;
// a build flag is not. Found 2026-09-15 building the S3 env for the first time.
#ifndef LED_PIN
#define LED_PIN    13     // classic ESP32; the S3 envs override this to 4
#endif
#ifndef STATUS_LED
#define STATUS_LED 2      // the onboard LED next to PWR on this board
#endif

#define PANEL_W 16
#define PANEL_H 16
#define PANEL_LEDS (PANEL_W * PANEL_H)

// A row of the wall is four panels. Override with -DPANELS=n for a single panel
// (1) or a whole column (12); every pattern scales itself to fit.
#ifndef PANELS
#define PANELS 4
#endif
#define N_LEDS (PANELS * PANEL_LEDS)

// These panels are older than the WS2812B the wall is specified around. Wrong
// chipset looks exactly like a dead row, so rule it out before condemning
// hardware: add one of
//   -DLED_CHIPSET=WS2811   -DLED_CHIPSET=WS2812   -DLED_CHIPSET=SK6812
// to build_flags in platformio.ini.
#ifndef LED_CHIPSET
#define LED_CHIPSET WS2812B
#endif

// Current budget. FastLED rescales brightness every frame to stay inside it, so
// a mistake dims the row rather than browning out the supply or melting a lead.
// SET THIS TO WHAT YOUR BENCH SUPPLY CAN ACTUALLY DELIVER.
#ifndef SUPPLY_VOLTS
#define SUPPLY_VOLTS 5
#endif
#ifndef SUPPLY_MA
#define SUPPLY_MA    5000
#endif

#define BAND_ROWS 2       // band pattern: 2 rows x 16 x PANELS = 128 LEDs lit
#define BLOCK     64      // block pattern: a quarter panel, lit at any instant

// The trace is paced to a fixed wall-clock duration rather than one LED per
// frame, because frame time scales with chain length and the useful speed does
// not. One panel runs at ~130 fps, so a per-frame trace would cross it in two
// seconds and you would never see where it stopped. Floored by the frame time:
// a long chain is frame-limited and simply takes longer.
#define TRACE_MS  20000

CRGB leds[N_LEDS];

// ----------------------------------------------------------------- mapping --
// Column-serpentine inside one panel, the same formula the driver uses:
//   local = x * 16 + (y if x even else 15 - y)
// The band pattern uses it, so a scrambled band means this is wrong for your
// panels. The other patterns work in raw chain order on purpose: when you are
// checking wiring you want the physical chain, not an interpretation of it.
static inline uint16_t px(uint8_t panel, uint8_t x, uint8_t y) {
    return panel * PANEL_LEDS + (uint16_t)x * PANEL_H + ((x & 1) ? (PANEL_H - 1 - y) : y);
}

// ---------------------------------------------------------------- patterns --
// Ordered so the lit-LED count falls as you go down, and so the first thing you
// see after a reset is the one that proves the chain.
enum Pattern {
    P_WALK,    // one panel white at a time   256 lit   chain order and aliveness
    P_BAND,    // a sliding band on each panel 128 lit  all panels at once, hues cycling
    P_BLOCK,   // a block marching the row      64 lit  every LED in six colours
    P_TRACE,   // one LED end to end             1 lit  exactly where the chain stops
    P_COUNT
};

struct Step { const char *name; uint32_t ms; uint16_t lit; };

// ms == 0 means the pattern steps once per frame and says when it is done, so a
// slow frame can never make it skip an LED.
static const Step STEPS[P_COUNT] = {
    {"panel walk", PANELS * 700UL, PANEL_LEDS},
    {"band",       12000,          BAND_ROWS * PANEL_W * PANELS},
    {"block",      0,              BLOCK},
    {"trace",      0,              1},
};

static uint8_t  pattern   = P_WALK;
static uint32_t stepStart = 0;
static uint32_t pos       = 0;      // frame-stepped cursor for block and trace
static bool     done      = false;
static int      lastNote  = -1;
static uint32_t lastAdv   = 0;   // paces the trace

static void clear() { fill_solid(leds, N_LEDS, CRGB::Black); }

static void renderWalk(uint32_t t) {
    clear();
    int p = (t / 700) % PANELS;
    fill_solid(&leds[p * PANEL_LEDS], PANEL_LEDS, CRGB::White);
    if (p != lastNote) { lastNote = p; Serial.printf("    panel %d\n", p); }
}

// Every panel shows a band at the same height, so one glance tells you all four
// are alive. The band slides and the hue rotates, which also proves the colour
// channels without ever lighting a whole panel.
static void renderBand(uint32_t t) {
    clear();
    uint8_t row = (t / 250) % PANEL_H;
    uint8_t hue = (uint8_t)((t / 250) * 11);
    for (int p = 0; p < PANELS; p++)
        for (uint8_t r = 0; r < BAND_ROWS; r++)
            for (uint8_t x = 0; x < PANEL_W; x++)
                leds[px(p, x, (row + r) % PANEL_H)] = CHSV(hue, 255, 255);
}

// A quarter-panel block marches the whole row, once per colour. The lit count is
// fixed no matter how long the chain is, so this runs at genuine full brightness
// and still exercises every LED in every channel.
static void renderBlock() {
    static const CRGB  C[6]  = {CRGB::White, CRGB::Red,    CRGB::Green,
                                CRGB::Blue,  CRGB::Yellow, CRGB::Cyan};
    static const char *NM[6] = {"white", "red", "green", "blue", "yellow", "cyan"};
    const uint32_t STRIDE = 8;                  // LEDs advanced per frame
    const uint32_t SPAN   = N_LEDS / STRIDE;    // frames in one colour pass

    uint32_t phase = pos / SPAN;
    if (phase >= 6) { done = true; return; }
    uint32_t start = (pos % SPAN) * STRIDE;

    clear();
    for (uint32_t i = 0; i < BLOCK; i++)
        if (start + i < N_LEDS) leds[start + i] = C[phase];

    if ((int)phase != lastNote) {
        lastNote = (int)phase;
        Serial.printf("    %s\n", NM[phase]);
    }
    pos++;
}

// One LED at a time, nothing skipped, paced to about 20 seconds whatever the
// chain length. The index is printed in case a laptop is attached, but the point
// is that you can watch where the dot stops without one.
static void renderTrace() {
    uint32_t now = millis();
    if (now - lastAdv < (uint32_t)(TRACE_MS / N_LEDS)) return;    // hold this frame
    lastAdv = now;

    for (uint16_t i = 0; i < N_LEDS; i++) leds[i].nscale8(140);   // short tail
    if (pos < N_LEDS) leds[pos] = CRGB::White;
    if (pos % 64 == 0 && pos < N_LEDS)
        Serial.printf("    LED %4lu   (panel %lu, pixel %lu)\n",
                      (unsigned long)pos,
                      (unsigned long)(pos / PANEL_LEDS),
                      (unsigned long)(pos % PANEL_LEDS));
    if (++pos >= N_LEDS + 16) done = true;      // +16 lets the tail fade out
}

// -------------------------------------------------------------------- main --
static void enter(uint8_t p) {
    pattern   = p;
    stepStart = millis();
    pos       = 0;
    done      = false;
    lastNote  = -1;
    lastAdv   = 0;
    clear();
    Serial.printf("\n[%d/%d] %s   (max %u LEDs lit, ~%.1f A before capping)\n",
                  p + 1, P_COUNT, STEPS[p].name, STEPS[p].lit, STEPS[p].lit * 0.060f);
}

static void banner() {
    float frame = N_LEDS * 0.030f;
    Serial.println(F("\n=== Baybasi standalone row test =============================="));
    Serial.printf("  %d panels chained on GPIO %d  =  %d LEDs\n", PANELS, LED_PIN, N_LEDS);
    Serial.printf("  frame ~%.0f ms (~%.0f fps).  Whole string white would be ~%.0f A.\n",
                  frame, 1000.0f / frame, N_LEDS * 0.060f);
    Serial.printf("  Cap %.1f A.  No pattern lights more than %d LEDs (~%.1f A).\n",
                  SUPPLY_MA / 1000.0f, PANEL_LEDS, PANEL_LEDS * 0.060f);
    Serial.println(F("  Runs forever with no laptop attached. Onboard LED blinks 1 Hz"));
    Serial.println(F("  while the firmware is alive: panels dark + LED blinking means"));
    Serial.println(F("  power, data or panels, not a crashed board."));
    Serial.println(F("  Far panels dim or orange = voltage drop. Inject 5 V at both"));
    Serial.println(F("  ends of the chain before believing an LED is dead."));
    Serial.println(F("=============================================================="));
}

void setup() {
    Serial.begin(115200);              // harmless with nothing attached
    pinMode(STATUS_LED, OUTPUT);

#ifdef OE_PIN
    // Talking to a panel THROUGH the production controller board. Its twelve
    // outputs pass two SN74AHCT245s whose /OE is pulled HIGH by R15, so they
    // come out of reset DISABLED and stay that way until this pin goes low.
    //
    // Park the data line low FIRST. The 245 is a buffer, not a latch: enable it
    // while its input is still a floating ESP32 pad and it drives that float
    // straight at a panel's DIN. Order matters, one line of code apart.
    pinMode(LED_PIN, OUTPUT);
    digitalWrite(LED_PIN, LOW);
    pinMode(OE_PIN, OUTPUT);
    digitalWrite(OE_PIN, LOW);
    Serial.printf("  /OE on GPIO %d driven LOW: 245 outputs enabled\n", OE_PIN);
#endif

    FastLED.addLeds<LED_CHIPSET, LED_PIN, GRB>(leds, N_LEDS);
    FastLED.setMaxPowerInVoltsAndMilliamps(SUPPLY_VOLTS, SUPPLY_MA);
    FastLED.setBrightness(255);        // the power cap does the real limiting
    FastLED.clear(true);

    banner();
    enter(P_WALK);
}

void loop() {
    uint32_t now = millis();
    digitalWrite(STATUS_LED, (now / 500) % 2);   // 1 Hz "firmware is alive"

    uint32_t t = now - stepStart;
    bool over = STEPS[pattern].ms ? (t >= STEPS[pattern].ms) : done;
    if (over) {
        enter((pattern + 1) % P_COUNT);          // wraps forever
        t = 0;
    }

    switch (pattern) {
        case P_WALK:  renderWalk(t);  break;
        case P_BAND:  renderBand(t);  break;
        case P_BLOCK: renderBlock();  break;
        case P_TRACE: renderTrace();  break;
        default:      clear();        break;
    }
    FastLED.show();
}

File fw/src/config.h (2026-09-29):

#pragma once
#include <Arduino.h>

// ---------------------------------------------------------------------------
// Baybasi controller: compile-time configuration.
//
// The pin map is final.  It comes from the board's pad coordinates, not from
// preference - see hw/FABRICATION.md.  Nothing here is a suggestion.
// ---------------------------------------------------------------------------

#define FW_VERSION "0.1.0"

// ---- W5500 on SPI ---------------------------------------------------------
static constexpr int PIN_ETH_CS   = 10;   // devkit pad 16, FSPI IOMUX
static constexpr int PIN_ETH_MOSI = 11;   // pad 17
static constexpr int PIN_ETH_SCK  = 12;   // pad 18
static constexpr int PIN_ETH_MISO = 13;   // pad 19
static constexpr int PIN_ETH_INT  = 14;   // pad 20
static constexpr int PIN_ETH_RST  = 15;   // pad 8, active low, 10k to 3V3E
// Overridable so the bench can drop it without editing this file:
//   PLATFORMIO_BUILD_FLAGS="-DETH_SPI_MHZ_CFG=4" pio run
// 25 MHz is well inside the W5500's 33 MHz ceiling, but it crosses two socket
// pairs and a plug-in module, so it is the first thing to lower when SPI reads
// back all zeros.
#ifndef ETH_SPI_MHZ_CFG
#define ETH_SPI_MHZ_CFG 25
#endif
static constexpr int ETH_SPI_MHZ  = ETH_SPI_MHZ_CFG;

// ---- twelve LED outputs, D1 .. D12 ---------------------------------------
// D1-D3 are the left row; D4-D12 the right row.
static constexpr int NUM_OUTPUTS = 12;
static const int LED_PINS[NUM_OUTPUTS] = {
    4, 5, 6,                              // D1  D2  D3
    1, 2, 21, 38, 39, 40, 41, 42, 47,     // D4 .. D12
};

// ---- level shifters -------------------------------------------------------
// GPIO 8 drives /OE on both SN74AHCT245N and is pulled up to 3V3E on the board.
// HIGH = outputs high-impedance, and the panels then see a defined low through
// R16-R27.  It is held high through boot and driven low only once a complete
// frame is buffered, otherwise the wall shows noise at power-up.
static constexpr int PIN_OE = 8;

static constexpr int PIN_SYNC   = 7;      // J14, optional, unpopulated
static constexpr int PIN_STATUS = 48;     // on-board RGB LED

// ---- geometry this board owns --------------------------------------------
// One panel per output, never daisy-chained.  That is what holds a strand to
// 256 LEDs and the frame time to 7.68 ms + 300 us latch = 7.98 ms, so 125 fps.
static constexpr int    PANEL_LEDS  = 256;
static constexpr int    NUM_LEDS    = PANEL_LEDS * NUM_OUTPUTS;   // 3072
static constexpr size_t FRAME_BYTES = (size_t)NUM_LEDS * 3;       // 9216

// ---- power cap ------------------------------------------------------------
// The one line the whole electrical design rests on.
//
// A 16x16 panel at full white is 256 LEDs x 60 mA = 15.4 A. Twelve of them is
// 184 A a column, and no supply in this design delivers that - an RSP-320-5 is
// 60 A, and the S-350-5 on hand derates to about 50 A continuous. So the budget
// is enforced here, in software, and the supply is sized to the cap rather than
// to the arithmetic. hw/POWER-RISER.html sizes every conductor on the
// assumption that this is present and working.
//
// FastLED applies it inside show(), BEFORE any controller clocks out: it sums
// the unscaled power of every registered controller and scales the whole frame
// down to fit. Two properties matter here and both were read out of the library
// rather than assumed (FastLED.cpp, m_pPowerFunc in CFastLED::show()):
//   - it is driver-agnostic, so it works on the S3 LCD_CAM parallel path, not
//     just on RMT;
//   - it sums ACROSS controllers, so twelve addLeds() outputs are budgeted
//     together. That is exactly what a per-column cap needs.
//
// It only engages on very bright frames. The cap is about a third of full
// white, so a frame has to be almost entirely white before it bites - at which
// point a second 8-bit quantisation of an all-white frame is not something
// anyone can see. That is why setBrightness stays at 255 in leds.cpp: real
// brightness is done on the Pi in 16 bit, and this is a ceiling, not a level.
//
// SET THIS TO MATCH THE SUPPLY ACTUALLY FEEDING THE COLUMN. Override it rather
// than editing this file:
//   PLATFORMIO_BUILD_FLAGS="-DCOLUMN_MAX_MA_CFG=50000" pio run    # S-350-5
//
// NOT YET CONFIRMED ON HARDWARE. Before trusting it, drive one column to full
// white and put a clamp meter on the feeder: it must sit at the cap, not climb
// toward 184 A. A cap that silently fails to engage is worse than no cap at
// all, because the wiring was sized on the assumption that it does.
#ifndef COLUMN_MAX_MA_CFG
#define COLUMN_MAX_MA_CFG 60000
#endif
static constexpr uint32_t COLUMN_MAX_MA = COLUMN_MAX_MA_CFG;
static constexpr uint8_t  SUPPLY_VOLTS  = 5;

// ---- wire -----------------------------------------------------------------
static constexpr uint16_t DDP_PORT  = 4048;
static constexpr uint16_t CTRL_PORT = 4049;   // announce / assign / OTA
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

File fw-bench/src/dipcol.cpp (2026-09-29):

// Baybasi pixel wall — rev B bring-up: one panel, and the column DIP switch
//
// The first test that needs a rev B board. The devkit is FULLY SEATED in
// A1L/A1R (rev B's 25.4 mm pitch), so unlike the ctrl-board env there are no
// flying leads and GPIO 9/16/17/18 are reachable for the first time.
//
// What it does: draws the column number the DIP switch is asking for, as a big
// digit on one 16x16 panel hung off J1, and prints the raw pin state to serial.
// Flip a slider and the digit changes within about 50 ms.
//
//   pio run -e ctrl-revb -t upload
//   pio device monitor
//
// TWO PHASES, AND WHY.
//
// Data into a panel whose 5 V is OFF back-feeds through its protection diodes
// and kills the driving GPIO (FABRICATION.md). Rather than rely on getting the
// power-up order right at the bench, this build makes it structural:
//
//   Phase 1, on boot: /OE stays HIGH. Both 245s are high-impedance and every
//     panel sees a defined low through R16-R27. The switch readout runs and
//     prints. YOU CAN TEST THE WHOLE DIP CIRCUIT HERE, with the panel dark and
//     unpowered - it is pure GPIO and owes the panel nothing.
//
//   Phase 2, when you say so: power the panel, press ENTER in the monitor, and
//     /OE goes LOW. Only then does anything reach J1.
//
// So a panel can sit connected and unpowered through a flash, a reset and as
// much switch-flipping as you like, and nothing is at risk. Build with
// -DAUTO_ENABLE=1 to skip the gate when you want it running unattended.
//
// The other rule still stands and this build cannot enforce it: a seated devkit
// with USB live back-feeds 5 V out of J13 through Q1. Either the bench supply
// is on before USB goes in, or J13 is empty.
//
// The panel's 5 V does NOT come from this board. J1-J12 carry DATA + GND only
// (FABRICATION.md, "Panel power stays off this board"). The panel's red lead
// goes to the bench supply, its GND to the supply, and the J1 pair carries data
// and the signal ground.
//
// WHAT "PASS" LOOKS LIKE
//   - Serial banner names the pin map, then a line every time a slider moves.
//   - The panel shows 0, 1, 2 or 3 matching the sliders, in its own colour.
//   - Two blocks on the LEFT edge mirror the two column poles, so you can see
//     which slider you just touched without decoding the digit.
//   - Two blocks on the RIGHT edge are the spare poles, GPIO 17 and 18. They
//     are wired and routed but nothing reads them in production; they are here
//     so the traces get exercised once before anyone relies on them.
//
// A dark panel with a healthy serial banner is power, data or the panel - not
// the firmware. That is the whole point of printing before lighting anything.

#include <Arduino.h>
#include <FastLED.h>

// ------------------------------------------------------------------ pins ----
// D1 on the production board: GPIO 4 -> R1 (330R) -> U1 -> J1.
#ifndef LED_PIN
#define LED_PIN 4
#endif
// Both SN74AHCT245s share /OE. HIGH = high-impedance and the panels see a
// defined low through R16-R27; the board pulls it up, so it is already safe at
// reset. Nothing reaches a panel until this goes LOW.
#ifndef OE_PIN
#define OE_PIN 8
#endif

// Column select, rev B. Confirmed against hw/gen_sch.py: devkit pad 15 = GPIO 9
// = COL_B0, pad 9 = GPIO 16 = COL_B1, pad 10 = GPIO 17, pad 11 = GPIO 18.
// Every pole's common side is GND, so the internal pull-up makes an OPEN switch
// read 1 and a CLOSED switch read 0 - and the firmware inverts. Closed = 1.
#define PIN_COL_B0  9    // silkscreen "1", binary weight 1
#define PIN_COL_B1  16   // silkscreen "2", binary weight 2
#define PIN_COL_SP0 17   // silkscreen "SP", unread in production
#define PIN_COL_SP1 18   // silkscreen "SP", unread in production

#define PANEL_W 16
#define PANEL_H 16
#ifndef PANEL_LEDS
#define PANEL_LEDS (PANEL_W * PANEL_H)
#endif

// One panel of a digit is roughly 90 LEDs. At full white that would be 5.4 A,
// which is not what anyone wants on a bench with a meter on it. FastLED rescales
// the whole frame to stay inside MAX_MA, so a mistake dims the panel instead of
// browning out the supply.
#ifndef BRIGHTNESS
#define BRIGHTNESS 80
#endif
#ifndef MAX_MA
#define MAX_MA 1500
#endif

// 1 = drive /OE low as soon as the first frame is buffered, with no prompt.
// Only for a panel you know is powered, or a bench with nothing on J1.
#ifndef AUTO_ENABLE
#define AUTO_ENABLE 0
#endif

static CRGB leds[PANEL_LEDS];

// ---------------------------------------------------------------- mapping ---
// Column-serpentine, the same formula the driver and wall.yaml agree on:
//   local = x * 16 + (y if x even else 15 - y)
// x is 0..15 left to right, y is 0..15 top to bottom. If the digit comes out
// mirrored in alternate columns, THIS is wrong for your panels, not the glyphs.
static inline uint16_t px(uint8_t x, uint8_t y) {
    return (uint16_t)x * PANEL_H + ((x & 1) ? (PANEL_H - 1 - y) : y);
}

static inline void put(uint8_t x, uint8_t y, const CRGB &c) {
    if (x < PANEL_W && y < PANEL_H) leds[px(x, y)] = c;
}

static void block(uint8_t x0, uint8_t y0, uint8_t w, uint8_t h, const CRGB &c) {
    for (uint8_t y = 0; y < h; y++)
        for (uint8_t x = 0; x < w; x++) put(x0 + x, y0 + y, c);
}

// ----------------------------------------------------------------- glyphs ---
// Four digits, 10 wide x 12 tall, drawn as one bitmask per row with bit 9 at
// the LEFT. Placed at x=3, y=2, which leaves x 0-2 and 13-15 clear for the
// switch indicators and y 0-1 / 14-15 clear at top and bottom.
#define GLYPH_W 10
#define GLYPH_H 12
#define GLYPH_X 3
#define GLYPH_Y 2

static const uint16_t GLYPH[4][GLYPH_H] = {
    // 0
    {0x0FC, 0x1FE, 0x387, 0x303, 0x303, 0x303,
     0x303, 0x303, 0x303, 0x387, 0x1FE, 0x0FC},
    // 1
    {0x030, 0x070, 0x0F0, 0x1F0, 0x030, 0x030,
     0x030, 0x030, 0x030, 0x030, 0x1FE, 0x1FE},
    // 2
    {0x0FC, 0x1FE, 0x303, 0x003, 0x006, 0x00C,
     0x018, 0x030, 0x060, 0x0C0, 0x3FF, 0x3FF},
    // 3
    {0x0FC, 0x1FE, 0x303, 0x003, 0x006, 0x07C,
     0x07C, 0x006, 0x003, 0x303, 0x1FE, 0x0FC},
};

// One colour per column, so the panel is readable from across the room before
// the digit resolves. The DIGIT is the real signal; colour is redundant on
// purpose, because "which green did you mean" is not a bring-up conversation.
static const CRGB COL_RGB[4] = {
    CRGB(255,  24,   0),   // 0  red
    CRGB(255, 120,   0),   // 1  amber
    CRGB(  0, 220,  40),   // 2  green
    CRGB( 40, 110, 255),   // 3  blue
};
static const char *COL_NAME[4] = {"red", "amber", "green", "blue"};

// ------------------------------------------------------------------ state ---
static bool g_live = false;     // have the level shifters been enabled yet
static void enableOutputs();

struct Switches { bool b0, b1, sp0, sp1; uint8_t col; };
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

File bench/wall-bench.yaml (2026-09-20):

# Baybasi pixel wall - geometry and wire map.
#
# Everything here is data on purpose.  When the wall is up and row 7 of column 2
# is showing row 8's picture, you fix it by editing this file and restarting the
# driver.  Nothing in this file requires a code change to correct.
#
# One file per display.  Both displays are identical, so both Pis use this same
# file - see manifest checksums in the upload utility for keeping them in step.

wall:
  width: 64          # 4 columns x 16
  height: 192        # 12 rows x 16

panel:
  width: 16
  height: 16

  # How the 256 LEDs inside one panel are chained.
  #
  #   axis: column   -> the strand runs along y, moving one column of x at a time
  #   start: top_left-> LED 0 is at local (0, 0) and the first run goes downward
  #   serpentine: true -> every other run is reversed
  #
  # Together these reproduce the mapping verified against the team's earlier code:
  #     local = x * 16 + (y if x % 2 == 0 else 15 - y)
  chain:
    axis: column
    start: top_left
    serpentine: true

# Channel order on the wire.
#
# The WS2812B itself is 24-bit GRB, MSB first, but that is a property of the LED,
# not of the link.  DDP's data-type byte declares RGB, so the Pi sends RGB and
# the firmware reorders on the way into the strand buffer (one flag,
# LED_ORDER_GRB in fw/src/config.h).  That keeps a packet capture and any
# third-party DDP tool honest, and costs the controller nothing.
#
# If you would rather the Pi did the reorder, set this to GRB and set
# LED_ORDER_GRB to 0 in the firmware.  Exactly one of the two must swap.
# `baybasi pattern bars` tells you which way round you are in one look: the
# top band is red.
color_order: RGB

# Image pipeline.  Gamma and brightness are applied on the Pi, in 16 bit,
# then dithered to 8 bit.
render:
  fps: 30
  gamma: 2.2
  brightness: 0.5      # 0.0 .. 1.0, applied after gamma, before dither
  dither: bayer8       # bayer8 | none
  # Fixed wall-clock epoch shared by BOTH displays.  Changing it desynchronises
  # them until both Pis are updated.  Unix seconds.
  epoch: 1767225600    # 2026-01-01T00:00:00Z

network:
  # Both displays use this same subnet.  They never see each other.
  broadcast: 192.168.50.255
  ddp_port: 4048
  control_port: 4049
  pixels_per_packet: 480   # 1440 data bytes + 10 header = 1450, under 1472
  # DDP destination id.  Each controller answers to its own id and to 255.
  # Per-controller ids also let one software sink demultiplex all four columns
  # from a single socket - see sw/README.md.
  id_mode: per_controller  # per_controller | default

# One entry per controller board.  `column` is which 16-px-wide column of the
# wall it drives.  `panels` maps a wall row to a physical output D1..D12 on that
# board; the wire layout is by OUTPUT number, so output N owns bytes
# [(N-1)*768, N*768) of that controller's 9216-byte buffer.
#
# `transform` rotates or mirrors an individual panel, for the one that got
# mounted upside down.  none | rot90 | rot180 | rot270 | flipx | flipy
controllers:
  - column: 0
    ip: 192.168.50.11
    ddp_id: 1
    panels:
      - {row: 0,  output: 1}
      - {row: 1,  output: 2}
      - {row: 2,  output: 3}
      - {row: 3,  output: 4}
      - {row: 4,  output: 5}
      - {row: 5,  output: 6}
      - {row: 6,  output: 7}
      - {row: 7,  output: 8}
      - {row: 8,  output: 9}
      - {row: 9,  output: 10}
      - {row: 10, output: 11}
      - {row: 11, output: 12}

  - column: 1
    ip: 192.168.50.12
    ddp_id: 11
    panels:
      - {row: 0,  output: 1}
      - {row: 1,  output: 2}
      - {row: 2,  output: 3}
      - {row: 3,  output: 4}
      - {row: 4,  output: 5}
      - {row: 5,  output: 6}
      - {row: 6,  output: 7}
      - {row: 7,  output: 8}
      - {row: 8,  output: 9}
      - {row: 9,  output: 10}
      - {row: 10, output: 11}
      - {row: 11, output: 12}

  - column: 2
    ip: 192.168.50.13
    ddp_id: 12
    panels:
      - {row: 0,  output: 1}
      - {row: 1,  output: 2}
      - {row: 2,  output: 3}
      - {row: 3,  output: 4}
      - {row: 4,  output: 5}
      - {row: 5,  output: 6}
      - {row: 6,  output: 7}
      - {row: 7,  output: 8}
      - {row: 8,  output: 9}
      - {row: 9,  output: 10}
      - {row: 10, output: 11}
      - {row: 11, output: 12}

  - column: 3
    ip: 192.168.50.14
    ddp_id: 13
    panels:
      - {row: 0,  output: 1}
      - {row: 1,  output: 2}
      - {row: 2,  output: 3}
      - {row: 3,  output: 4}
      - {row: 4,  output: 5}
      - {row: 5,  output: 6}
      - {row: 6,  output: 7}
      - {row: 7,  output: 8}
      - {row: 8,  output: 9}
      - {row: 9,  output: 10}
      - {row: 10, output: 11}
      - {row: 11, output: 12}

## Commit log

2026-09-07 Baybasi pixel wall: driver, upload utility, DDP sink and controller firmware
    Software for a 64x192 WS2812B wall of two network-isolated displays, built
    against HANDOFF-software.md.
    sw/ (Python, runs on the Pi)
    - software DDP sink: stands in for all four controllers on one host, so the
    driver and utility were finished and demoed before any board existed
    - driver: 30 fps against a wall clock, gamma/brightness in 16 bit then
    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
    [baybasi-ctrl-B_Cu.gbr, baybasi-ctrl-B_Mask.gbr, baybasi-ctrl-B_Paste.gbr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]
2026-09-07 Remove the superseded pre-QA shopping list
    hw/SHOPPING-LIST.pre-qa.html predates the 2026-09-07 design QA, which found
    four defects and changed parts. Two shopping lists in one directory, with
    nothing to say which is current, is how the wrong parts get ordered.
    The ignore rule was `hw/*.pre-qa`, which only matched names ending in
    `.pre-qa`; this file carries it in the middle. Widened to `hw/*.pre-qa*`.
2026-09-20 hw: batch-1 bring-up procedure and the socket pitch finding
    The five batch-1 PCBs are good except for one dimension: the dev-kit socket
    rows are on the official Espressif 22.86 mm spacing, and every third-party
    ESP32-S3-DevKitC-1 in hand is 25.40 mm - exactly one 2.54 mm pitch wider. The
    boards work with the devkit half-seated, which is how the whole bring-up was
    done, and batch 2 moves the socket out by one pitch.
    BRINGUP.md is the procedure that validated the board in that state: line
    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
2026-09-20 fw-bench: standalone bench firmware for the twelve outputs
    A second, deliberately minimal PlatformIO project that drives the LED outputs
    with nothing else running - no Ethernet, no DDP, no framebuffer. When the main
    firmware showed one frame every four seconds, this is what separated "the LED
    driver is slow" from "something else is blocking the loop".
    Two environments: ctrl-board walks one output, ctrl-all12 drives all twelve.
    The macro is LED_PIN, not DATA_PIN. -DDATA_PIN collides with FastLED's own
    template parameter of that name and breaks 42 of its headers; the error points
    into the library, not at the flag. Finding that also revealed that the earlier
    panel-test-s3 sketch had never act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
    [all12.cpp, main.cpp]
2026-09-20 fw: 30 fps on all twelve outputs - FastLED, octal PSRAM, IDF 5.4.x
    First working firmware on hardware. Measured: 30 fps sustained, shown ==
    frames, torn == 0, show() 5078 us average against a 7680 us theoretical
    transfer - 15% duty, so the ceiling is around 197 fps for twelve outputs.
    The throughput blocker was three faults wearing one symptom (frames assembled
    at 30 fps, ~0.27/s reaching the panel), and none of the three is fixable
    alone:
    1. hpwit/I2SClocklessLedDriver replaced with FastLED's S3 LCD_CAM driver
    (-DFASTLED_USES_ESP32S3_I2S). The old library compiles on IDF 5.5 but takes
    ~1 s per frame. FastLED wraps the same peripheral and version-guards the IDF
    releases it is brok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
    [config.h, leds.cpp, main.cpp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]
2026-09-20 sw: ident pattern, saturated flow, and the fix that made discover work
    `baybasi discover` had never worked. ControlPlane's receive handler was named
    _handle, and threading.Thread grew a _handle attribute in Python 3.13 - a
    _thread._ThreadHandle assigned during start() - which shadows a subclass method
    of that name. The thread died on its first packet with "'_thread._ThreadHandle'
    object is not callable", and discover's screen-clearing output wiped the
    traceback, so it looked like nothing was announcing. Renamed _on_message.
    Fine on 3.12, broken on 3.13.
    `flow` rebuilt on proper HSV. It had built each channel as sin()*0.5+0.5, which
    never lets a channel reach zero: the three always summed to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
2026-09-20 bench: wall config, state of the build, and what comes next
    wall-bench.yaml is the single-board bench geometry - the real four-column wall
    config with column 0's ddp_id corrected from 10 to 1 to match the firmware's
    default identity, so a fresh board answers without commissioning first.
    STATE.md records what is proven on hardware versus what is only designed:
    power, /OE through the socket, U1, series resistors, output terminals, W5500,
    Ethernet, DHCP, discovery, DDP, serpentine mapping, colour order and 30 fps on
    twelve outputs are all measured. Panels beyond J3, the second display and the
    Pi-side deployment are not.
    NEXT-SESSION.md carries the open work, highest value first. The DHCP gap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
    [wall-bench.yaml]
2026-09-20 sw: marquee pattern, and fix the preview being twice as dark as the wall
    `marquee` scrolls a word left to right, one line per wall row, in that
    output's own colour over a sparkle field. Tuned for ONE 16x16 panel seen on
    its own, which is the bench reality today and the harder case: a 5 px word in
    a 16 px square leaves a lot of empty board, so the sparkles are denser and
    blunter than a 64x192 view would need, and a slow wash in the output's hue
    sits under everything so the panel never looks like a few lit dots on black.
    Each row runs the full 64 px width rather than repeating per panel, so on the
    finished wall one word crosses all four boards - which only looks right if
    four independent cont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
2026-09-20 fw: an unassigned board gives itself an address when there is no DHCP
    There is deliberately no DHCP server on the pixel segment, so an unassigned
    board never got an address, never announced, and could not be commissioned.
    That is every board in the field. It went unnoticed because the bench runs on
    a home LAN that does have DHCP.
    A board with no static address of its own now asks for DHCP and, if it still
    has no address after DHCP_WAIT_MS (8 s), takes 192.168.50.<MAC-derived>.
    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
2026-09-20 Close the identify gap: make commissioning usable at install time
    Discovery gives you MACs. A MAC does not tell you which of four identical
    boxes behind the wall it is, so commissioning needs a way to make one board
    show itself. That existed in the firmware and in ControlPlane and could not be
    reached: only `assign` was on the CLI.
    - `baybasi identify <mac> [--seconds N]` and `baybasi clear <mac>` added.
    - Identify floods the whole column at 2 Hz instead of blinking the on-board
    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
2026-09-20 hw: U2 and the A1R socket half validated - the PCB is now fully proven
    Both were completely untested until tonight. The devkit sits half-seated in
    A1L, so every output proven so far (D1-D3) came through A1L and U1; the whole
    right-hand socket and the second buffer had never passed a signal. Ten boards
    were about to be ordered on that basis.
    Tested with the step-6 breadboard jumper rig and fw-bench's ctrl-all12:
    J4 -> 4 white pixels first signal ever through A1R
    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
2026-09-20 hw: panel power stays off the board - batch 2 is now a one-line change
    Decided: the controller carries DATA and GND only. Panel +5 V runs separately
    from the supply and the red conductor in every JST-SM lead stays cut and
    capped at both ends. The alternative was a co-routed three-conductor cable out
    of the board.
    Rejected on current. Twelve panels at full white is 184 A; even a fraction of
    that has no business crossing a 2-layer signal board, its terminal blocks or
    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
2026-09-20 fw-bench: panel-liveness - walk a built wall and find dead panels
    No controller PCB and no bench supply: the devkit powers one panel from its
    own 5 V pin and drives DIN directly, so the rig is a USB cable and a 3-pin
    lead, repeated 48 times.
    Three phases, shaped entirely by the current budget:
    chain one white pixel walks 0 -> 255. Where it stops is where the chain
    breaks; a gap is a dead pixel. Nearly free in current, and the test
    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
2026-09-20 fw-bench: liveness on GPIO 14, contiguous with 5Vin and GND
    The bottom of the devkit's left header is DATA(14) / 5Vin / GND, three in a
    row, so one 3-pin lead reaches all of it. A standard WS2812 JST-SM lead has
    DATA in the MIDDLE, so the test lead is deliberately re-ordered to come out
    correct at the panel end.
    That lead is now a special item: it is wired differently from every other
    JST-SM lead in this project, where white is GND, green is DATA and the red
    +5 V conductor is cut and capped at both ends. Mixed into the panel leads it
    would put +5 V onto a data line. The env comment says to label it.
    Also flagged in the env: meter 5Vin before relying on it. On most devkits it
    sits on USB VB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
    [liveness.cpp]
2026-09-20 fw-bench: liveness sized for an external 5 V source, not a USB port
    MEASURED on this devkit 2026-09-20: 5Vin reads 0.18 V with USB-C connected,
    against 3.28 V on the 3V3 pin from the same ground point. That pin is an
    INPUT, isolated from VBUS, so it cannot source the panel - the original plan
    of powering everything from one USB-C cable does not work on this hardware.
    The fix is smaller than it sounds and leaves the rig better off: drive 5Vin
    from a USB power bank. The devkit runs off it through the same diode that is
    doing the isolating, and because the pin is now driven, the panel taps it
    directly. The three contiguous pins stay DATA(14) / 5Vin / GND, the
    re-ordered test lead is unchanged,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
    [liveness.cpp]
2026-09-20 fw-bench: panel-liveness-ctrl - liveness through the controller board
    Devkit half-seated in A1L, panel 5 V from the supply as it is in service, no
    computer and no Ethernet. D1/D2/D3 -> J1/J2/J3 all carry the SAME pattern from
    one buffer, so any jumper will do, or hang three panels on and check three at
    a time.
    This is the better of the two liveness builds, and the reason is the level
    shifter. The bare-devkit build drives DIN from a 3.3 V GPIO, under the
    WS2812B's 0.7*VDD threshold, so a good panel can fail it and every failure has
    to be re-tested before the panel is set aside. Here the signal goes through
    the SN74AHCT245s and arrives at a proper 5 V: a panel that fails this one has
    really f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
    [liveness.cpp]
2026-09-20 fw-bench: pin upload/monitor port so auto-detect stops picking Bluetooth
    PlatformIO's port auto-detect on macOS chose /dev/cu.Bluetooth-Incoming-Port
    and sat there timing out against a Bluetooth device. A glob on the devkit's
    own pattern fixes it in all six envs without hardcoding a path that changes
    between reboots.
    upload_port = /dev/cu.usbmodem*
    monitor_port = /dev/cu.usbmodem*
    Note this matches the NATIVE USB port only. A board flashed through the
    UART-bridge port enumerates as usbserial and would need the glob widened.
2026-09-21 hw: spec column select by DIP switch for batch 2
    Proposed, not built. The column currently lives in NVS and is set over the
    network, which rests on a binding no machine can check: which MAC is in which
    physical column. The MAC is a factory eFuse value printed nowhere, so the
    answer today is "read it on the bench and put a sticker on".
    Switches close that by kind rather than degree. identify, DHCP reservations
    and power-on ordering all DISCOVER a binding a human established and must not
    forget; switches make the hardware state its own position.
    The find that makes this worth more than expected: production addressing is a
    pure function of the column - ip = 192.168.50.(11 + col), ddp_id = 10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
2026-09-21 hw: DIP column select drops to 2 bits, plain binary
    Raj pushed back on the three-position encoding and was right. The third
    switch was an ENABLE, there so "no switches set" could be told apart from
    "column 0" - two bits gives four codes and I wanted five states.
    The fifth state does not earn a GPIO:
    - The only boards without a DIP are batch 1, which are bench-only (wrong
    socket pitch, never going in the wall). A -DNO_COLUMN_DIP build covers them.
    - "Someone forgot to set the switches" is a real failure - four boards read
    00, all claim column 0, all take .11 - but it is trivially visible as four
    boards announcing col:0. That is a software check, not a pin.
    What plain binary buys back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
2026-09-21 hw: real JLCPCB part for the column switch - and my SMD advice was wrong
    Checked the JLCPCB assembly parts library rather than reciting a series from
    memory, and the earlier recommendation in this doc does not survive it.
    Searching "DIP Switch" returns 12 parts and exactly ONE has stock:
    C99987, Diptronics EI-04 - 4 position, THROUGH-HOLE, 2.54 mm, SPST slide,
    24V/25mA, 103 in stock, $0.52 at qty 1. Everything else is stock 0 and marked
    Consign Part, including CSWDIP-2P (C9900014698), the 2-bit SMD part this doc
    told you to prefer.
    The 4-position part is better than the 2-position it replaces: use poles 1-2
    for the column and wire poles 3 and 4 to the free GPIOs 17 and 18. Two spare
    config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
2026-09-21 hw: column switch part is C99418, not C99987 - and JLCPCB search lies
    Second correction to the part recommendation in this doc, both found by
    actually looking rather than reciting.
    C99418, DongGuan KINGTEK DSWB04LHGET: 4 position, THT 2.54 mm, SPST slide,
    24V/25mA. 61,704 in stock at $0.2094. Same footprint as the C99987 I
    recommended an hour ago, at a quarter the price and 600x the stock - so the
    "stock of 103 is thin, check before ordering" warning I wrote simply goes
    away.
    The lesson is about the tool. JLCPCB's keyword search is NOT a survey of what
    they stock: searching "DIP Switch" returns 12 parts and does not include
    C99418 at all, despite 61,704 in stock. Searching the MPN finds it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
2026-09-21 hw: batch 2 - socket pitch 25.4 mm and the column-select DIP switch
    Both generator changes for the batch-2 run. Board is regenerated and placement
    is clean; routing is the next step and is not in this commit.
    **Socket pitch 22.86 -> 25.4.** A1_PITCH is now a named constant and A1_BODY
    derives from it, so the body cannot drift from the pads the way it would have
    if both were edited by hand. 22.86 was never wrong - it is Espressif's own row
    spacing for the DevKitC-1 - but every devkit actually in hand is a third-party
    board one 2.54 mm pitch wider. Three independent confirmations now: the fit
    test (binary, cannot be misread), a hole-centre measurement on a bare board
    2026-09-15, and Raj re-me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
    [gen_pcb.py, gen_sch.py]
2026-09-21 hw: revB routed, DRC clean, gerbers exported
    Board regenerated, routed and exported for the batch-2 run.
    0 DRC violations, 0 unconnected, 7 warnings
    all 7 are lib_footprint_mismatch - exactly batch 1's baseline
    Getting there took three real fixes beyond the two intended changes:
    **The right-hand cluster had to move with the socket.** A1R shifting 2.54 mm
    right squeezed the A1R-to-U1 channel from ~7 mm to ~4.5 mm, and the router
    could not keep the B.Cu pour continuous through it - isolated GND regions
    around x 60-78, y 24-34. U1/U2 shifted +2.5 mm restores it. An earlier attempt
    to paper over this with island_removal_mode made it worse (1 unconnected
    region became 3) and is reverte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
    [baybasi-ctrl-B_Cu.gbr, baybasi-ctrl-B_Mask.gbr, baybasi-ctrl-B_Paste.gbr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]
2026-09-21 hw: pre-order verification of revB against revA
    Deep comparison before committing to ten boards, done on the BOARD FILES with
    KiCad's parser rather than on the generators. revA is the batch-1 design that
    was fabricated and validated on the bench.
    Result: two intended changes, no unintended ones.
    - Components: SW1 added, nothing removed, no footprint substitutions.
    - Netlist: 74 nets both. Only new nets are COL_B0/B1/SP0/SP1; the only nets
    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
2026-09-22 hw: SW1's CPL rotation verified on JLCPCB's placement preview
    8d0537b listed three things that still needed a human before the batch-2
    boards could be trusted. This closes the first: SW1's CPL rotation, the one
    entry in ROT_FIX reasoned by analogy with the DIP sockets rather than read
    off JLCPCB's overlay.
    Checked on their part-placement preview for order W2026092200361486 and
    confirmed 2026-09-22. SW1 renders with the part's own printed 1/2/3/4 running
    top-to-bottom against the board silkscreen 1/2/SP/SP, and ON toward the GND
    pads, so pole 1 = pad 1 = COL_B0 = the top slider. +270 is correct.
    The comment now records the result instead of standing as an instruction to
    redo the check on th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
    [make_cpl.py]
2026-09-28 hw: commit the power and wiring design, and revise the feeder
    The power design has lived only as a published artifact. This repo already
    keeps its HTML design docs (SHOPPING-LIST, MEASURE-W5500-STE), so it belongs
    here too. Live version, which is what gets edited:
    https://claude.ai/artifact/TJyUNJveoNYpmtzpAhhYQu
    What changed since the sheet was first drawn on 2026-09-13:
    - The fused block and the controller board now share ONE enclosure per column,
    block above board, and four of those ride on two hinged doors in a 33 in bay
    on the side of the frame. New sheets E-1 and E-2. This broke an assumption:
    power up one stile and data up the other used to fall out of the geometry,
    and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
2026-09-29 fw: enforce the 60 A column cap, and correct two stale comments
    The whole electrical design is sized on the assumption that a column never
    draws more than 60 A, and until now nothing enforced it. Twelve panels at
    full white is 184 A; no supply in this design delivers that.
    COLUMN_MAX_MA lives in config.h with the arithmetic and is overridable per
    build (-DCOLUMN_MAX_MA_CFG=50000 for the S-350-5 on hand), because the cap
    must match whatever supply actually feeds the column. leds.cpp registers it
    before the first show().
    Two properties were read out of FastLED 3.10.3 rather than assumed, since a
    cap that silently fails to engage is worse than no cap:
    - CFastLED::show() applies m_pPowerFunc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
    [config.h, leds.cpp]
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2026-09-29 hw: per-column unit enclosure, rev B
    One printed box per column holding the 12-way fused block and the controller
    board, block above board, screwed flat to the inside of a hinged door. Four
    make a display, two to a 406 mm door. 144 x 328 x 65 mm.
    Rev A was a box for the bare PCB and predates the door-mounted unit, so this
    supersedes it; its STLs and renders go with it.
    THE BLOCK STANDS ON END. A DAIER FB-1714 puts its two feed studs on the
    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
    [clamp.stl, coupon.stl, cover.stl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]
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2026-10-10 sw: understand boards that take their column from a switch
    The Pi's role shrinks with rev B: a switch board configures itself, so the Pi
    has two jobs left - say which boards do, and notice when two of them have been
    set alike.
    - ControllerInfo records col_src from the announcement; `discover` shows it,
    and the fw column is wide enough for "0.2.0+<sha>".
    - Two online boards on one column are flagged "duplicate". Switches set
    alike put both boards on one column AND one address: half the wall goes
    dark and from the floor it looks like a content bug. This is the
    `baybasi verify` check DIP-COLUMN-SELECT.md asked for, in the place an
    operator already looks.
    - assign() ra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
2026-10-10 fw: flash_fleet.py - flash a run of devkits with one image
    Builds once, then waits on the USB bus. Plug in a devkit: a factory-fresh one
    (TinyUSB PID 0x4001, which esptool cannot reset) gets told to do the BOOT
    dance; anything on USB-Serial/JTAG is flashed with the image built at the
    start - `-t nobuild`, never a rebuild, so every board in the run carries the
    same bytes - and its identity line is read back and printed as one row.
    Warns up front if the image would be stamped -dirty, and at the end if a
    column was set on more than one board.
    macOS only (it watches ioreg). Run with PlatformIO's Python, which has
    pyserial.
2026-10-10 fw: flash_fleet.py - plain upload, and guard the image instead
    -t nobuild does not do what e627494 claimed. On this platform it skips
    assembling the bootloader, partition and boot images as well as the compile,
    so the write-flash command PlatformIO hands esptool is malformed and every
    upload fails:
    Invalid value for '<address> <filename>...': Must be pairs of an address
    and the binary filename to write there.
    Found on the first real board. The earlier check ran `-t nobuild` alone,
    which writes nothing and so could not catch it.
    Each upload is now a plain `pio run -t upload`. Its build is incremental, so
    unchanged source compiles nothing and firmware.bin keeps the same bytes -
    measur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
